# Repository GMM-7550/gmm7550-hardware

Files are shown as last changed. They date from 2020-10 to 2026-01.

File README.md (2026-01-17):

# CologneChip GateMate FPGA Module: GMM-7550

**January 2026 Update**

USB 3 adapter board is out of production, RP2040 firmware
is running, and basic functionality is tested -- no hardware
issues discovered.

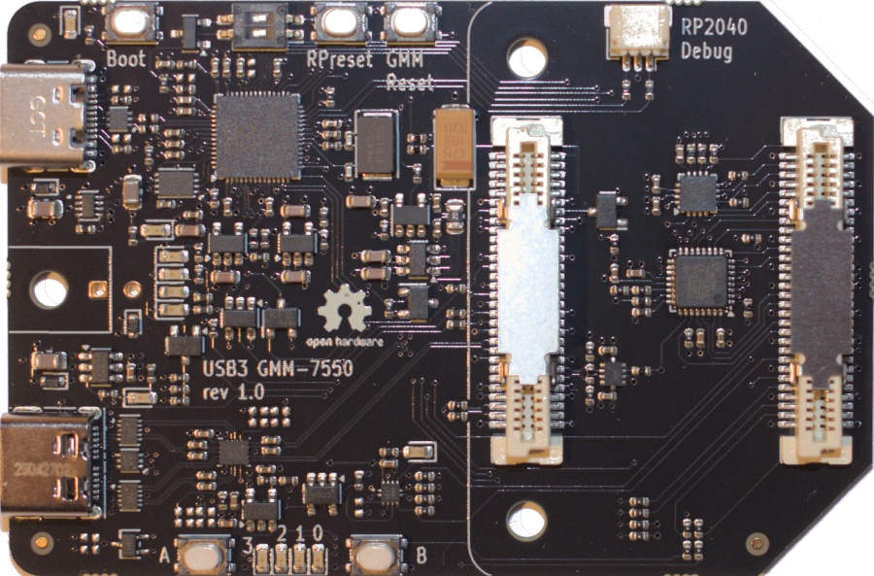
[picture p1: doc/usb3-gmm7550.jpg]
USB3 Adapter board


**October 2025 Update**

USB 3 adapter board is ready for production after the
[schematic](./doc/USB3-GMM-7550_1.0_2025-10-10.pdf)
changes and layout. KiCad 3D render of the board:

**July 2025 Update**

An experimental USB 3 Adapter board schematic is ready for
layout:

[USB 3 Adapter revision 0.9](./doc/USB3-GMM-7550_0.9_2025-07-24.pdf)

**January 2024 Update**

The project repositories are moved to a dedicated account.
Please, update your references to <https://github.com/gmm-7550/>
to follow further development.

**June 2022 Update**
After more than two years of development and delays
the module and adapter boards are out of production.

Tests are underway, no problems discovered so far, updates
are expected in a few weeks.

This project is licensed under [CERN-OHL-P v2](./cern_ohl_p_v2.txt)

Current module revision is 2.1 -- it is updated to the latest
(flip-chip) GateMate FPGA pin out. The other changes are complete
redesigns of the power and clock subsystems due to component
availability.

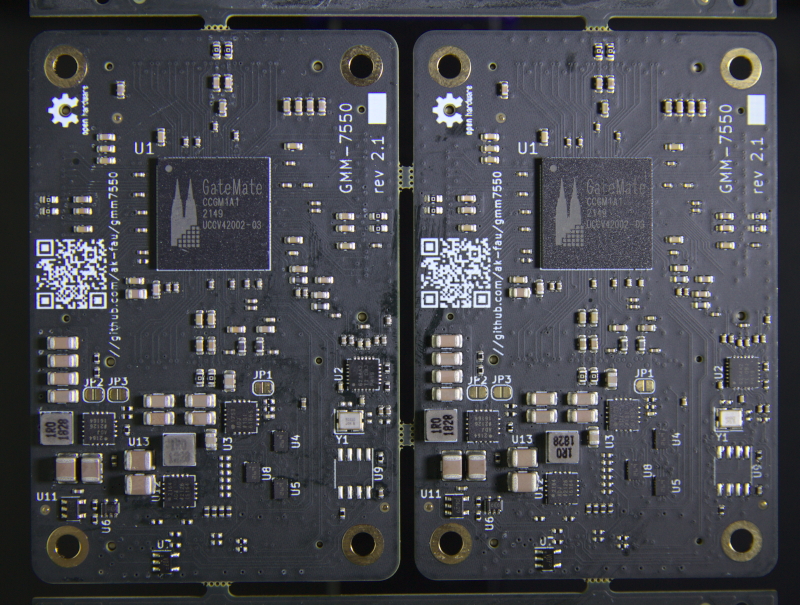
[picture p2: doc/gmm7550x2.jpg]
Assembled modules


[Schematic (pdf) version 2.1](./doc/GMM-7550_2.1_2022-04-24.pdf)

## 40-pin GPIO (R-Pi HAT) Adapter for GMM-7550 Module

The adapter board provides power to the GMM-7550 module (5V from
40-pin GPIO or from an external connector), I2C and SPI interfaces,
control over the module power enable and reset signals and module
power consumption monitoring.

Two 12-pin Pmod extension connectors are routed to the GateMate
FPGA South GPIO pins through 2.5/3.3 bi-directional level converter.

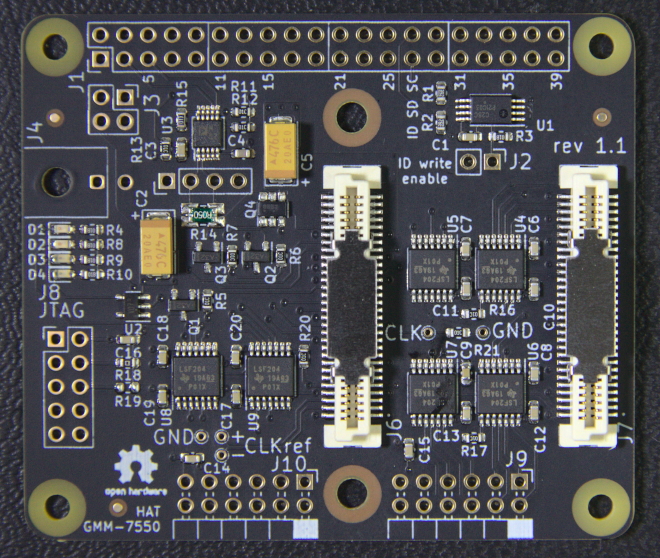
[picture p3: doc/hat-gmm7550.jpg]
Assembled 40-pin adapter board


[Schematic (pdf) version 1.1](./doc/HAT-GMM-7550_1.1_2022-04-24.pdf)

## Memory Extension Module

The module provides 512Kx8 static RAM (CY7C1049GN30-10ZSXI) with 10 ns
access time and 16 MiB QSPI NOR FLASH (S25LP128-JBLE). The module may
be connected to P1, P2 or P3 connector of the GMM-7550, up to three
modules may be connected simultaneously. An SPI Bridge example design
for FPGA routes SPI from a host (R-Pi or VisionFive board) to the
module connector and allows to access the SPI NOR chip on the module
from the host. The module control software provides commands to
automate the FPGA configuration and access to the SPI on the extension
module.

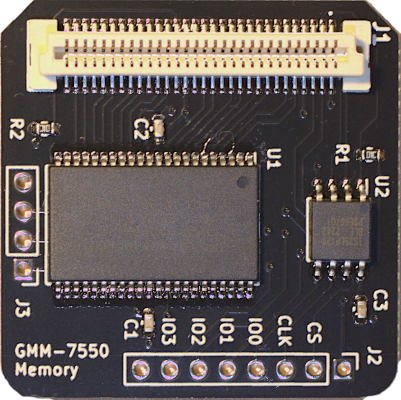
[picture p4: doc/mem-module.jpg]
Memory module


[Schematic (pdf) version 1.0](./doc/MEM-GMM-7550_1.0_2023-04-24.pdf)

## Test and Demo System based on VisionFive RISC-V SBC

The SBC runs [`buildroot`](https://buildroot.org/) embedded Linux,
experimental
[configuration for the VisionFive board](https://github.com/ak-fau/buildroot-visionfive/)
is available as a `buildroot`-external tree.

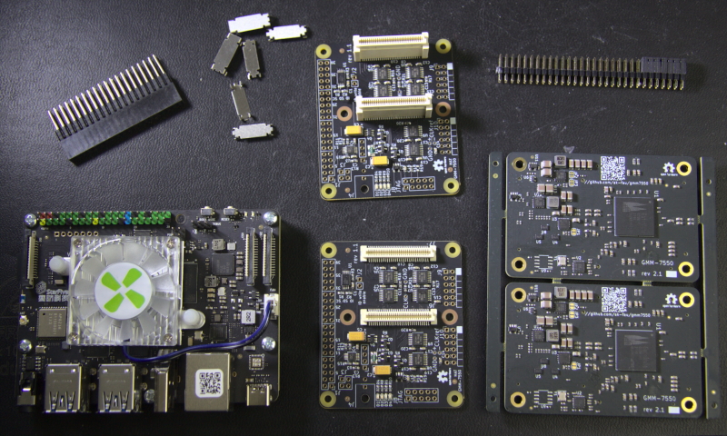
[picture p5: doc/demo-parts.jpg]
VisionFive SBC and modules for the test system


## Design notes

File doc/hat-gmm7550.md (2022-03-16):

# 40-pin GPIO (Raspberry Pi) HAT adapter for GMM-7550 module

# Connectors

## 40-pin GPIO J1

| RPi HAT | VisionFive | GMM | Pin | Pin | GMM | VisionFive | RPi HAT |
|---|---|---|:---:|:---:|---|---|---|
| +3.3V | +3.3V | +3.3V |  1  |  2  | +5V | +5V | +5V |
| | GPIO48 | SDA |  3  |  4  | +5V | +5V | +5V |
| | GPIO47 | SCL |  5  |  6  | GND | GND | GND |
| | GPIO46 | ON |  7  |  8  | Tx | GPIO14 | |
| GND | GND | GND |  9  |  10 | Rx | GPIO13 | |
| | GPIO44 | MR |  11 |  12 | | | |
| | GPIO22 | OFF |  13 |  14 | GND | GND | GND |
| | | |  15 |  16 | | | |
| +3.3V | +3.3V | +3.3V |  17 |  18 | | | |
| | GPIO18 | MOSI  |  19 |  20 | GND | GND | GND |
| | GPIO16 | MISO  |  21 |  22 | | | |
| | GPIO12 | SCK |  23 |  24 | | | |
| GND | GND | GND |  25 |  26 | | | |
| ID_SD | ID_SD | ID_SD |  27 |  28 | ID_SC | ID_SC | ID_SC |
| | | |  29 |  30 | GND | GND | GND |
| | | |  31 |  32 | | | |
| | | |  33 |  34 | GND | GND | GND |
| | | |  35 |  36 | | | |
| | | |  37 |  38 | | | |
| GND | GND | GND |  39 |  40 | GND | GND | GND |

## Pmod J9

Enable signal: `IO_SB_B3`

| Signal | Pin | Pin | Signal |
|---|:---:|:---:|---|
| `IO_SB_A6 (CLK3)` |  1  |  7  | `IO_SB_B6` |
| `IO_SB_A7 (CLK2)` |  2  |  8  | `IO_SB_B7` |
| `IO_SB_A8 (clk1)` |  3  |  9  | `IO_SB_B8` |
| `IO_SB_A5 (clk4)` |  4  |  10 | `IO_SB_B5` |
|  `GND` |  5  |  11 | `GND` |
|  `+3.3V` |  6  |  12 | `+3.3V` |

## Pmod J10

Enable signal: `IO_SA_A7`

| Signal | Pin | Pin | Signal |
|---|:---:|:---:|---|
| `IO_SA_A0` |  1  |  7  | `IO_SA_B0` |
| `IO_SA_A1` |  2  |  8  | `IO_SA_B1` |
| `IO_SA_A2` |  3  |  9  | `IO_SA_B2` |
| `IO_SA_A3` |  4  |  10 | `IO_SA_B3` |
|  `GND` |  5  |  11 | `GND` |
|  `+3.3V` |  6  |  12 | `+3.3V` |

## JTAG J8

| Signal | Pin | Pin | Signal |
|---|:---:|:---:|---|
| TCK |  1  |  2  | GND |
| TDO |  3  |  4  | Vio (opt)  |
| TMS |  5  |  6  | Vio (opt)  |
| n.c. |  7  |  8  | n.c. |
| TDI |  9  | 10  | GND |

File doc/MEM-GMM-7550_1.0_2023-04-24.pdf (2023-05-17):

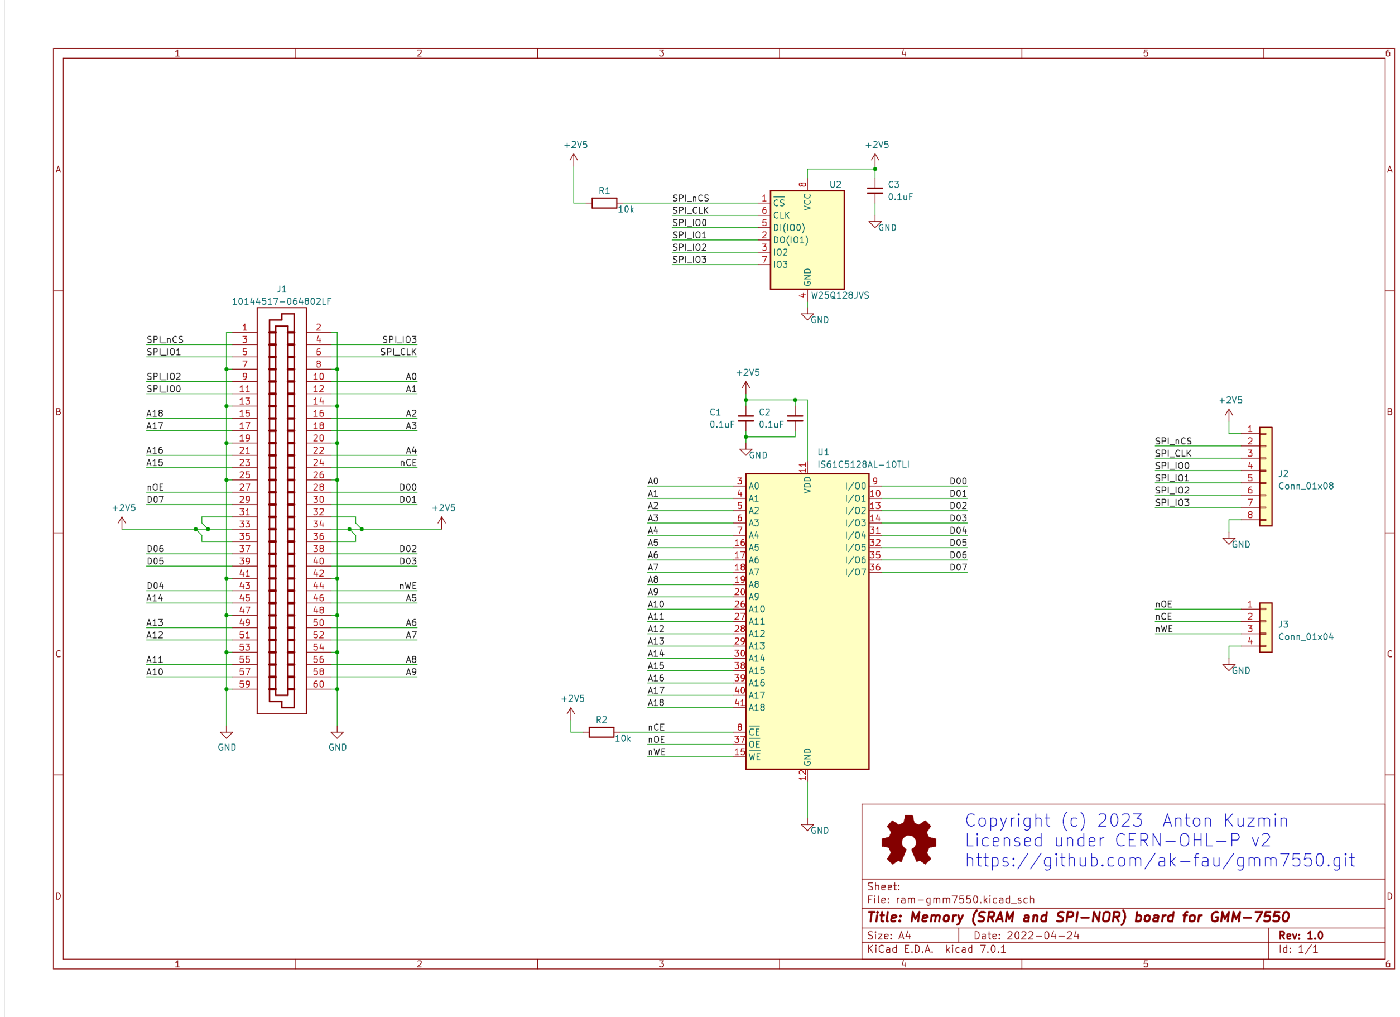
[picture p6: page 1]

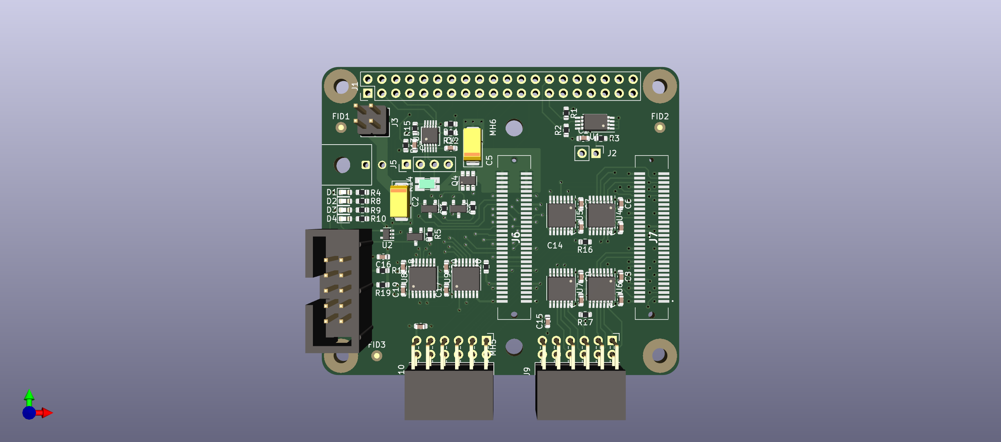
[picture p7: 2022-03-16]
doc/hat-gmm7550_preview_2022-01-22.png

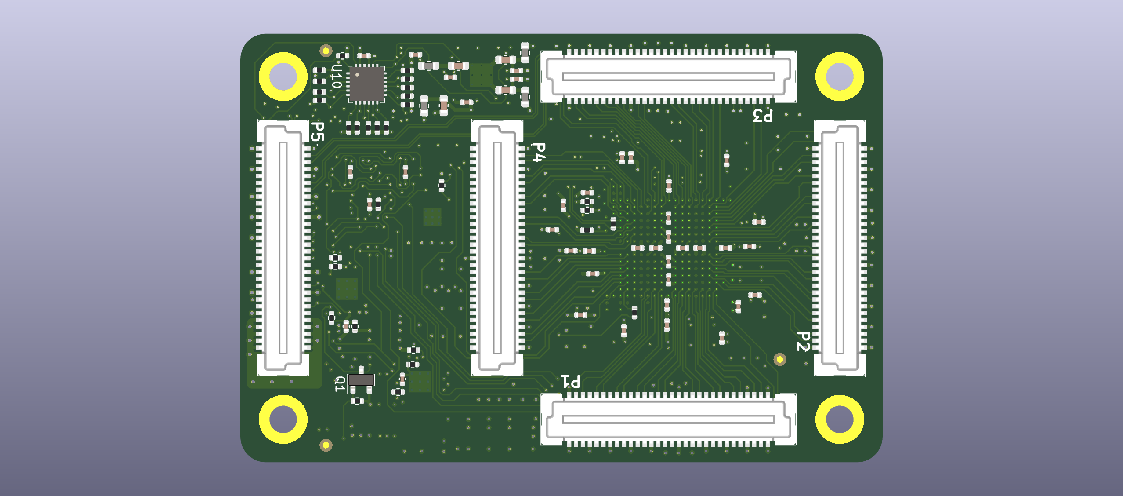
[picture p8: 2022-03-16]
doc/gmm7550_preview_bot_2022-03-09.png

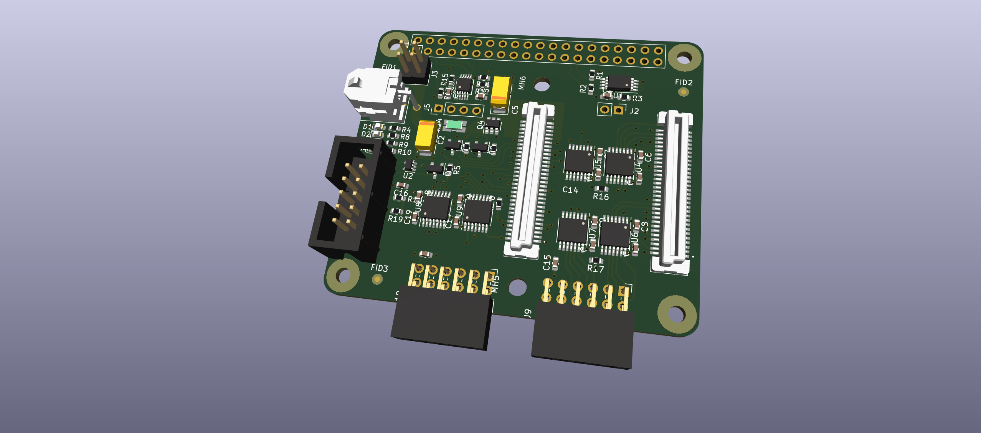
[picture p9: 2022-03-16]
doc/hat-gmm7550_preview_2022-01-27.png

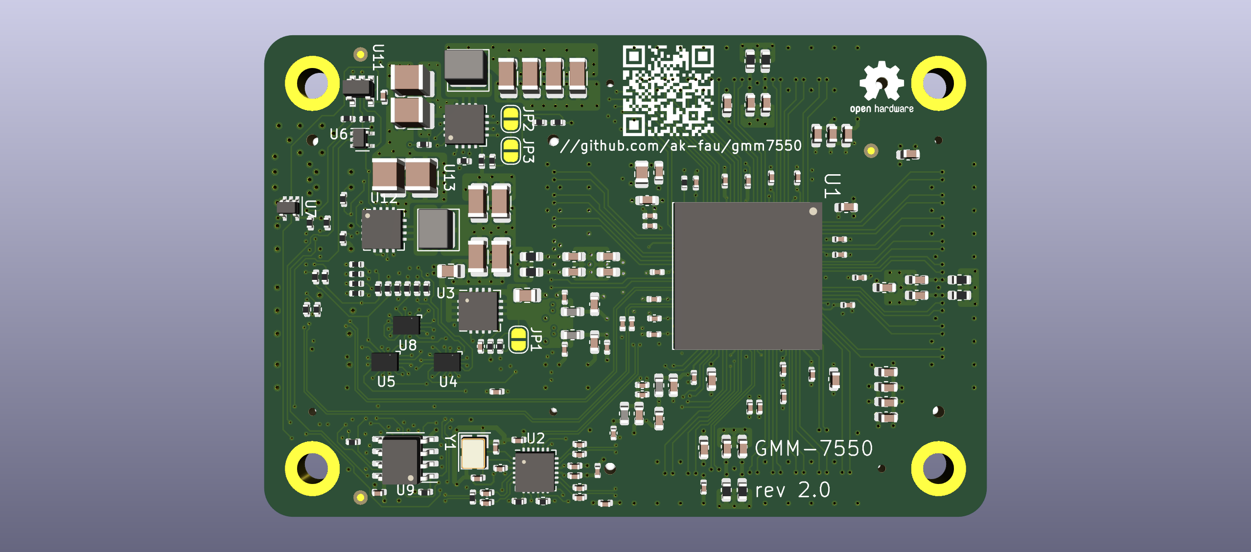
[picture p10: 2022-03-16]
doc/gmm7550_preview_top_2022-03-09.png

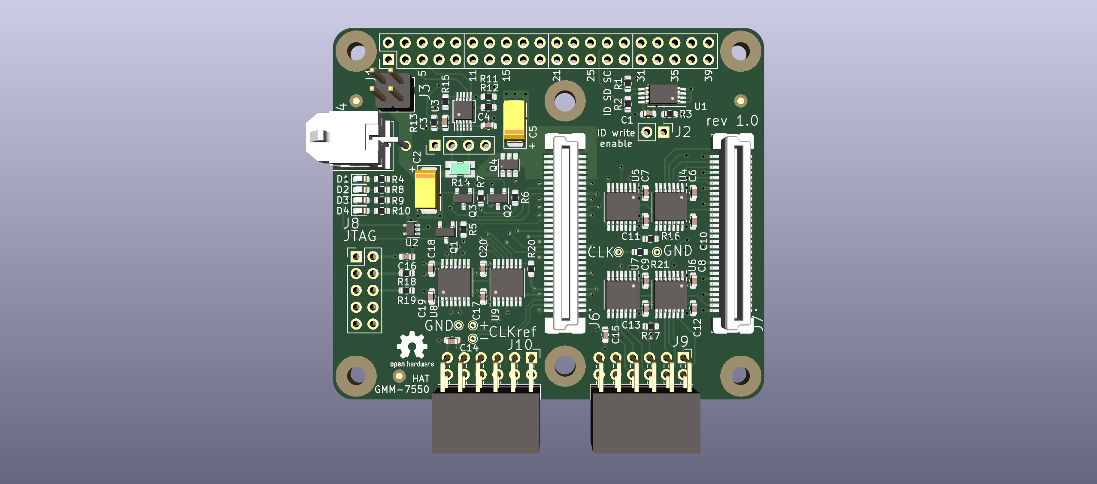
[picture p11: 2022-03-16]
doc/hat-gmm7550_preview_2022-03-09.png

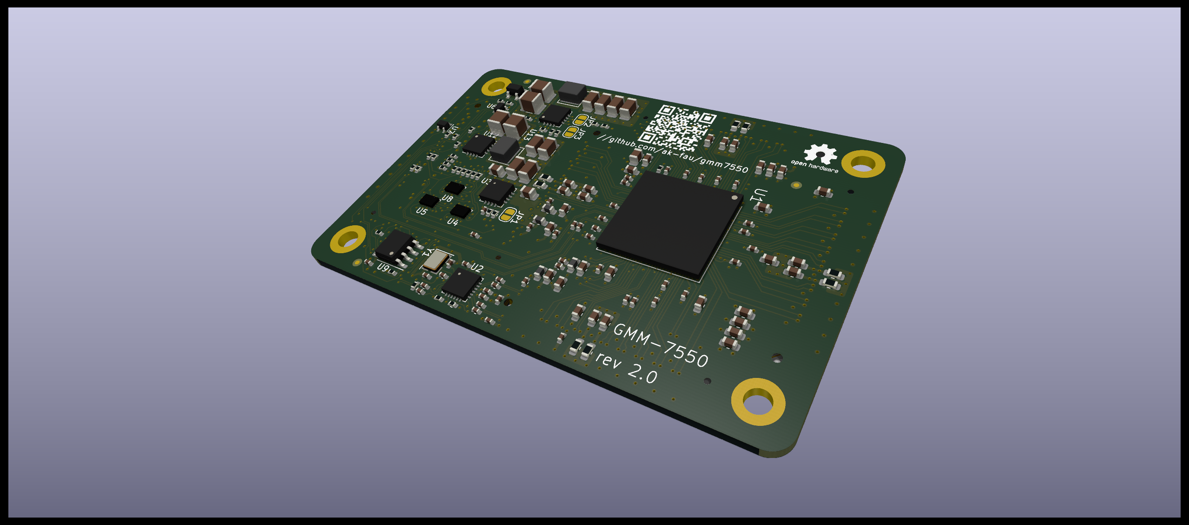
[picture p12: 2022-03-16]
doc/gmm7550_preview_3d_2022-03-09.png

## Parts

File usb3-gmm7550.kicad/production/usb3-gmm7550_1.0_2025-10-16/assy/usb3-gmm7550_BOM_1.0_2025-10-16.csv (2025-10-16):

Reference | Qty | Value | DNP | Exclude from BOM | Exclude from Board | Footprint | Datasheet
C1,C4,C5,C6,C7,C8,C9,C10,C12,C14,C15,C16,C21,C22,C26,C32,C33,C34,C35,C36,C37,C38,C39,C40,C41,C46,C47 | 27 | 0.1uF |  |  |  | Capacitor_SMD:C_0402_1005Metric | ~
C2,C3,C13,C17,C18,C44,C48,C49,C53 | 9 | 1.0uF |  |  |  | Capacitor_SMD:C_0402_1005Metric | ~
C11,C23,C45,C56 | 4 | 0.01uF |  |  |  | Capacitor_SMD:C_0402_1005Metric | ~
C19,C20,C27,C28,C29,C30,C31 | 7 | 2.2uF |  |  |  | Capacitor_SMD:C_0603_1608Metric | ~
C24 | 1 | DNI |  |  |  | Capacitor_SMD:C_0402_1005Metric | ~
C25 | 1 | 47uF, 16V |  |  |  | Capacitor_Tantalum_SMD:CP_EIA-6032-28_Kemet-C | ~
C42,C43 | 2 | 27pF |  |  |  | Capacitor_SMD:C_0402_1005Metric | ~
C50,C51,C52 | 3 | 10uF |  |  |  | Capacitor_SMD:C_0805_2012Metric | ~
D1,D11,D14 | 3 | CEZ6V2 |  |  |  | Diode_SMD:D_SOD-523 | ~
D2 | 1 | ESD752DCKR |  |  |  | usb3-gmm7550:SOT-SC70_DCK_TEX | https://www.ti.com/lit/gpn/esd752
D3,D4,D7,D8,D9,D10,D12,D13,D16 | 9 | 150060VS55040 |  |  |  | LED_SMD:LED_0603_1608Metric | ~
D5,D15 | 2 | HSMA-C197 |  |  |  | LED_SMD:LED_0603_1608Metric | ~
D6 | 1 | HSMC-C197 |  |  |  | LED_SMD:LED_0603_1608Metric | ~
J1 | 1 | USB_C_Receptacle |  |  |  | Connector_USB:USB_C_Receptacle_Molex_105450-0101 | https://www.usb.org/sites/default/files/documents/usb_type-c.zip
J2 | 1 | USB_C_Receptacle_USB2.0 |  |  |  | Connector_USB:USB_C_Receptacle_GCT_USB4105-xx-A_16P_TopMnt_Horizontal | https://www.usb.org/sites/default/files/documents/usb_type-c.zip
J3 | 1 | SWD |  |  |  | Connector_JST:JST_SH_SM03B-SRSS-TB_1x03-1MP_P1.00mm_Horizontal | ~
J4,J5 | 2 | 10144517-061802LF |  |  |  | Amphenol:10144517-061802LF
J6 | 1 | DNI |  |  |  | Connector_Molex:Molex_Micro-Fit_3.0_43045-0200_2x01_P3.00mm_Horizontal | ~
Q1,Q2,Q3,Q4 | 4 | NX6008NBK |  |  |  | Package_TO_SOT_SMD:SOT-23 | ~
R1,R2,R5,R6,R7,R8,R9,R10,R11,R12,R54,R55,R67,R79 | 14 | DNI |  |  |  | Resistor_SMD:R_0402_1005Metric | ~
R3,R13,R20,R21,R23,R26,R29,R31,R32,R34,R35,R42,R43,R50,R51,R56,R65,R70,R71,R72,R76,R77,R78 | 23 | 10k |  |  |  | Resistor_SMD:R_0402_1005Metric | ~
R4,R24 | 2 | 8.06k |  |  |  | Resistor_SMD:R_0402_1005Metric | ~
R14,R16,R57,R58 | 4 | 5.1k |  |  |  | Resistor_SMD:R_0402_1005Metric | ~
R15,R36,R40,R62,R63,R83 | 6 | 100 |  |  |  | Resistor_SMD:R_0402_1005Metric | ~
R17,R28,R60,R61 | 4 | 27.4 |  |  |  | Resistor_SMD:R_0402_1005Metric | ~
R18,R19,R89,R90 | 4 | 15 |  |  |  | Resistor_SMD:R_0402_1005Metric | ~
R22,R66,R80 | 3 | 0 |  |  |  | Resistor_SMD:R_0402_1005Metric | ~
R25,R27,R44,R45,R52,R53,R59,R64,R69,R73,R74,R75 | 12 | 1k |  |  |  | Resistor_SMD:R_0402_1005Metric | ~
R30,R33,R41,R46,R47,R48,R49,R68 | 8 | 75 |  |  |  | Resistor_SMD:R_0402_1005Metric | ~
R37 | 1 | 0.02 |  |  |  | Resistor_SMD:R_0805_2012Metric | ~
R38 | 1 | 120k |  |  |  | Resistor_SMD:R_0402_1005Metric | ~
R39 | 1 | 100k |  |  |  | Resistor_SMD:R_0402_1005Metric | ~
R81 | 1 | 900k |  |  |  | Resistor_SMD:R_0402_1005Metric | ~
R82,R84 | 2 | 301 |  |  |  | Resistor_SMD:R_0402_1005Metric | ~
R85 | 1 | 6.19k |  |  |  | Resistor_SMD:R_0402_1005Metric | ~
R86 | 1 | 2k |  |  |  | Resistor_SMD:R_0402_1005Metric | ~
R87 | 1 | 3.57k |  |  |  | Resistor_SMD:R_0402_1005Metric | ~
R88 | 1 | 1.69k |  |  |  | Resistor_SMD:R_0402_1005Metric | ~
SW1,SW2,SW3,SW4,SW5 | 5 | SW_Push |  |  |  | Button_Switch_SMD:SW_SPST_PTS810 | ~
SW6 | 1 | SW_DIP_x02 |  |  |  | Button_Switch_SMD:SW_DIP_SPSTx02_Slide_Omron_A6H-2101_W6.15mm_P1.27mm | ~
U1,U2 | 2 | ECMF4-40A100N10 |  |  |  | usb3-gmm7550:UQFN10L_1P4X2P25X0P4_STM | https://www.st.com/resource/en/datasheet/ecmf4-40a100n10.pdf
U3,U15 | 2 | ECMF02-2AMX6 |  |  |  | Package_DFN_QFN:ST_UQFN-6L_1.5x1.7mm_P0.5mm | https://www.st.com/resource/en/datasheet/ecmf02-2amx6.pdf
U4,U12,U13 | 3 | AP7330D |  |  |  | Package_TO_SOT_SMD:SOT-23-5
U5 | 1 | TUSB542 |  |  |  | usb3-gmm7550:Texas_X2QFN-18-1EP_2x2.4mm_P0.4mm_EP1x1.4mm_ThermalVias
U6 | 1 | SN65LVDS4RSER |  |  |  | usb3-gmm7550:RSE10 | https://www.ti.com/lit/gpn/sn65lvds4
U7 | 1 | USB3340 |  |  |  | Package_DFN_QFN:QFN-32-1EP_5x5mm_P0.5mm_EP3.3x3.3mm_ThermalVias | https://ww1.microchip.com/downloads/aemDocuments/documents/UNG/ProductDocuments/DataSheets/USB3340-Data-Sheet-DS00001678E.pdf
U8 | 1 | STUSB03E |  |  |  | Package_DFN_QFN:QFN-16-1EP_3x3mm_P0.5mm_EP1.7x1.7mm | https://www.st.com/resource/en/datasheet/stusb03e.pdf
U9 | 1 | SiP32510 |  |  |  | Package_TO_SOT_SMD:SOT-23-6 | https://www.vishay.com/docs/63577/sip32510.pdf
U10 | 1 | SN74LVC1G07DBV |  |  |  | Package_TO_SOT_SMD:SOT-23-5
U11 | 1 | INA180A2 |  |  |  | Package_TO_SOT_SMD:SOT-23-5 | http://www.ti.com/lit/ds/symlink/ina180.pdf
U14 | 1 | MX25R1635FZUIH0 |  |  |  | Package_SON:Winbond_USON-8-1EP_3x2mm_P0.5mm_EP0.2x1.6mm | https://www.mouser.com/datasheet/2/1127/APM_PSRAM_QSPI_APS1604M_SQR_v2_5_PKG-1954861.pdf
U16 | 1 | LM4040A30IDBZ |  |  |  | Package_TO_SOT_SMD:SOT-23 | http://www.ti.com/lit/ds/symlink/lm4040-n.pdf
U17 | 1 | RP2040 |  |  |  | Package_DFN_QFN:QFN-56-1EP_7x7mm_P0.4mm_EP3.2x3.2mm | https://datasheets.raspberrypi.com/rp2040/rp2040-datasheet.pdf
U18 | 1 | FUSB303BTMX |  |  |  | usb3-gmm7550:OnSemi_X2QFN-12_1.6x1.6mm | https://www.onsemi.com/pub/Collateral/FUSB303B-D.PDF
U19 | 1 | SiP32508DT |  |  |  | Package_TO_SOT_SMD:TSOT-23-6 | https://www.vishay.com/docs/62754/sip32508.pdf
U20 | 1 | LM66200DRLR |  |  |  | usb3-gmm7550:SOT-5X3_DRL_TEX | https://www.ti.com/lit/gpn/lm66200
U21 | 1 | SN74LVC1G06DBV |  |  |  | Package_TO_SOT_SMD:SOT-23-5 | http://www.ti.com/lit/sg/scyt129e/scyt129e.pdf
Y1 | 1 | 445I23D12M00000 |  |  |  | Crystal:Crystal_SMD_5032-2Pin_5.0x3.2mm | ~

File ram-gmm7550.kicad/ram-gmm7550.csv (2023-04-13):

Source: | /home/ak/Work/ccgm/gmm/ram-gmm7550.kicad/ram-gmm7550.kicad_sch
Date: | Tue Apr 11 13:08:18 2023
Tool: | Eeschema 7.0.1
Generator: | /usr/share/kicad/plugins/bom_csv_grouped_by_value_with_fp.py
Component Count: | 10
Ref | Qnty | Value | Cmp name | Footprint | Description | Vendor | DNP
C1, C2, C3 | 3 | 0.1uF | C_Small | Capacitor_SMD:C_0603_1608Metric | Unpolarized capacitor, small symbol
J1 | 1 | 10144517-064802LF | 10144517-061802LF | Amphenol:10144517-061802LF | Board to Board & Mezzanine Connectors Rec, R1, 60Pos
J2 | 1 | Conn_01x08 | Conn_01x08 | Connector_PinHeader_2.54mm:PinHeader_1x08_P2.54mm_Vertical | Generic connector, single row, 01x08, script generated (kicad-library-utils/schlib/autogen/connector/)
J3 | 1 | Conn_01x04 | Conn_01x04 | Connector_PinHeader_2.54mm:PinHeader_1x04_P2.54mm_Vertical | Generic connector, single row, 01x04, script generated (kicad-library-utils/schlib/autogen/connector/)
R1, R2 | 2 | 10k | R | Resistor_SMD:R_0603_1608Metric | Resistor
U1 | 1 | IS61C5128AL-10TLI | IS61C5128AL-10TLI | Package_SO:TSOP-II-44_10.16x18.41mm_P0.8mm | 512K x 8 HIGH-SPEED CMOS STATIC RAM, 10ns, TSOP II-44
U2 | 1 | W25Q128JVS | W25Q128JVS | Package_SO:SOIC-8_5.23x5.23mm_P1.27mm | 128Mb Serial Flash Memory, Standard/Dual/Quad SPI, SOIC-8

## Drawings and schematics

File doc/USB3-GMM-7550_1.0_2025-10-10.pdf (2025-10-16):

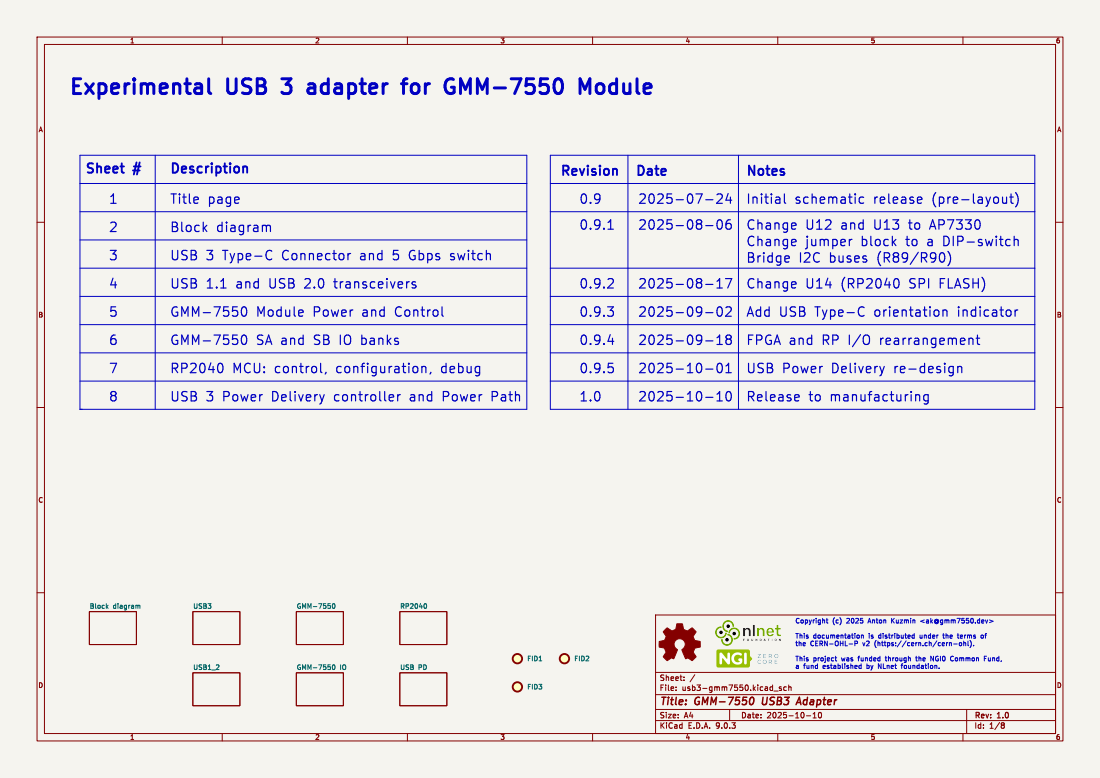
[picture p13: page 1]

Title page
Block diagram
USB 1.1 and USB 2.0 transceivers

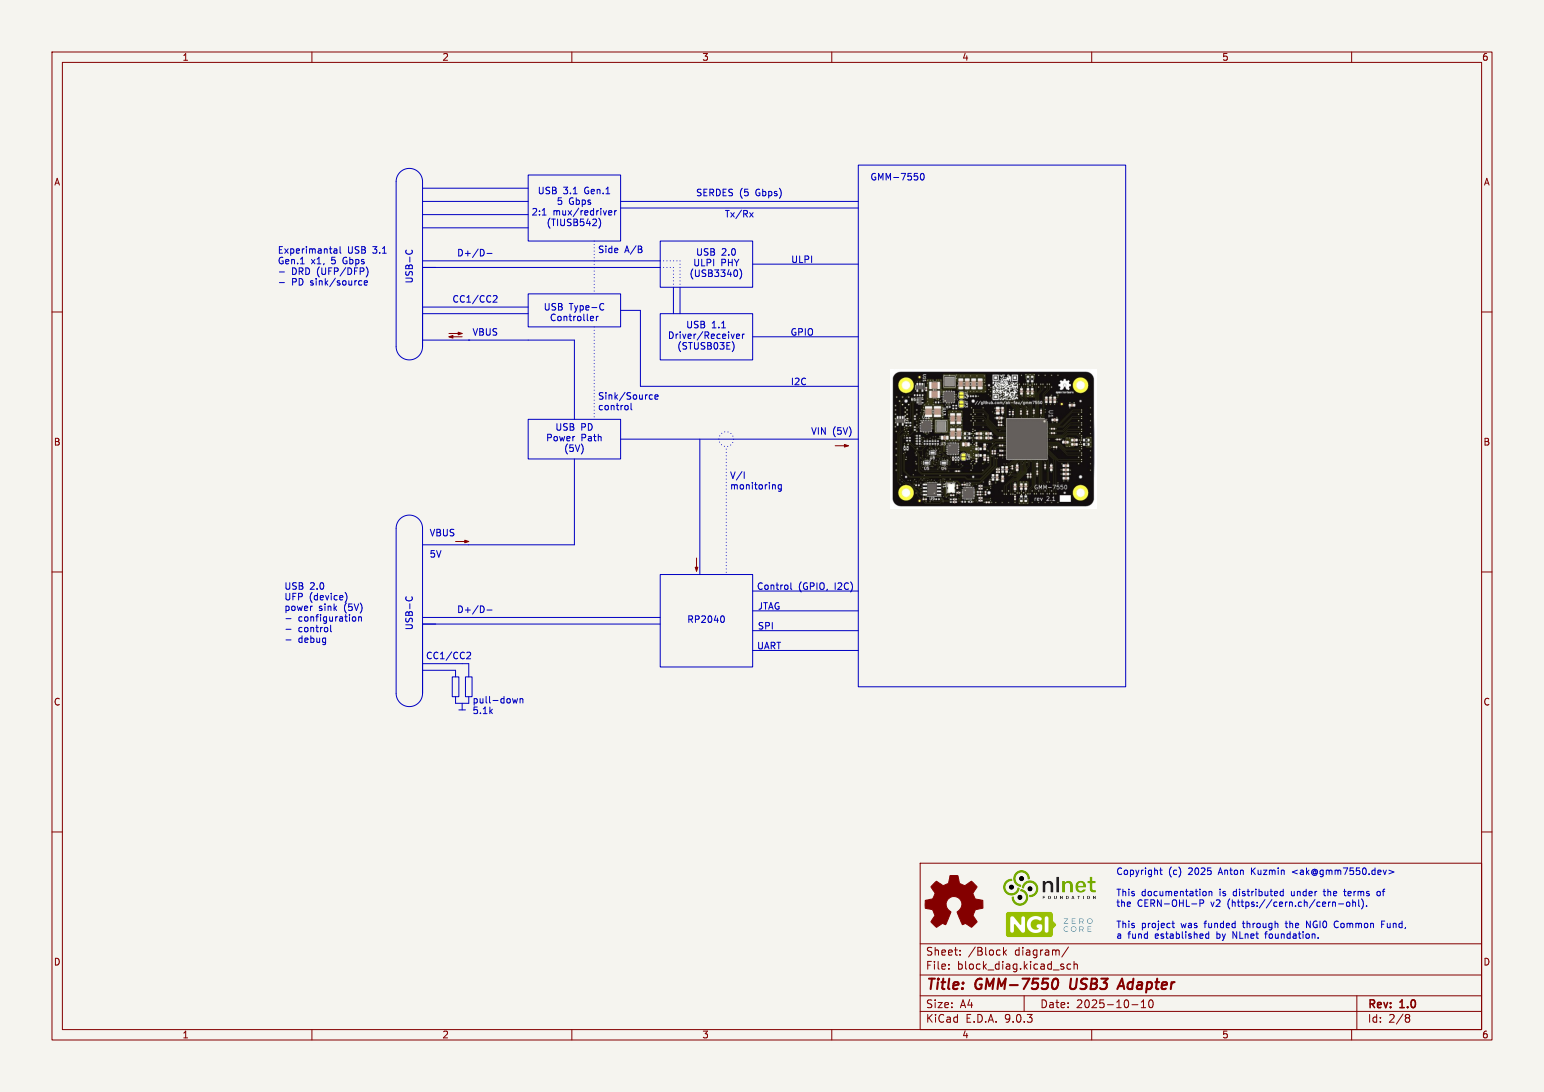
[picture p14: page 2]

- PD sink/source USB 2.0 UFP (device) power sink (5V)

(USB3340) SERDES (5 Gbps) Tx/Rx

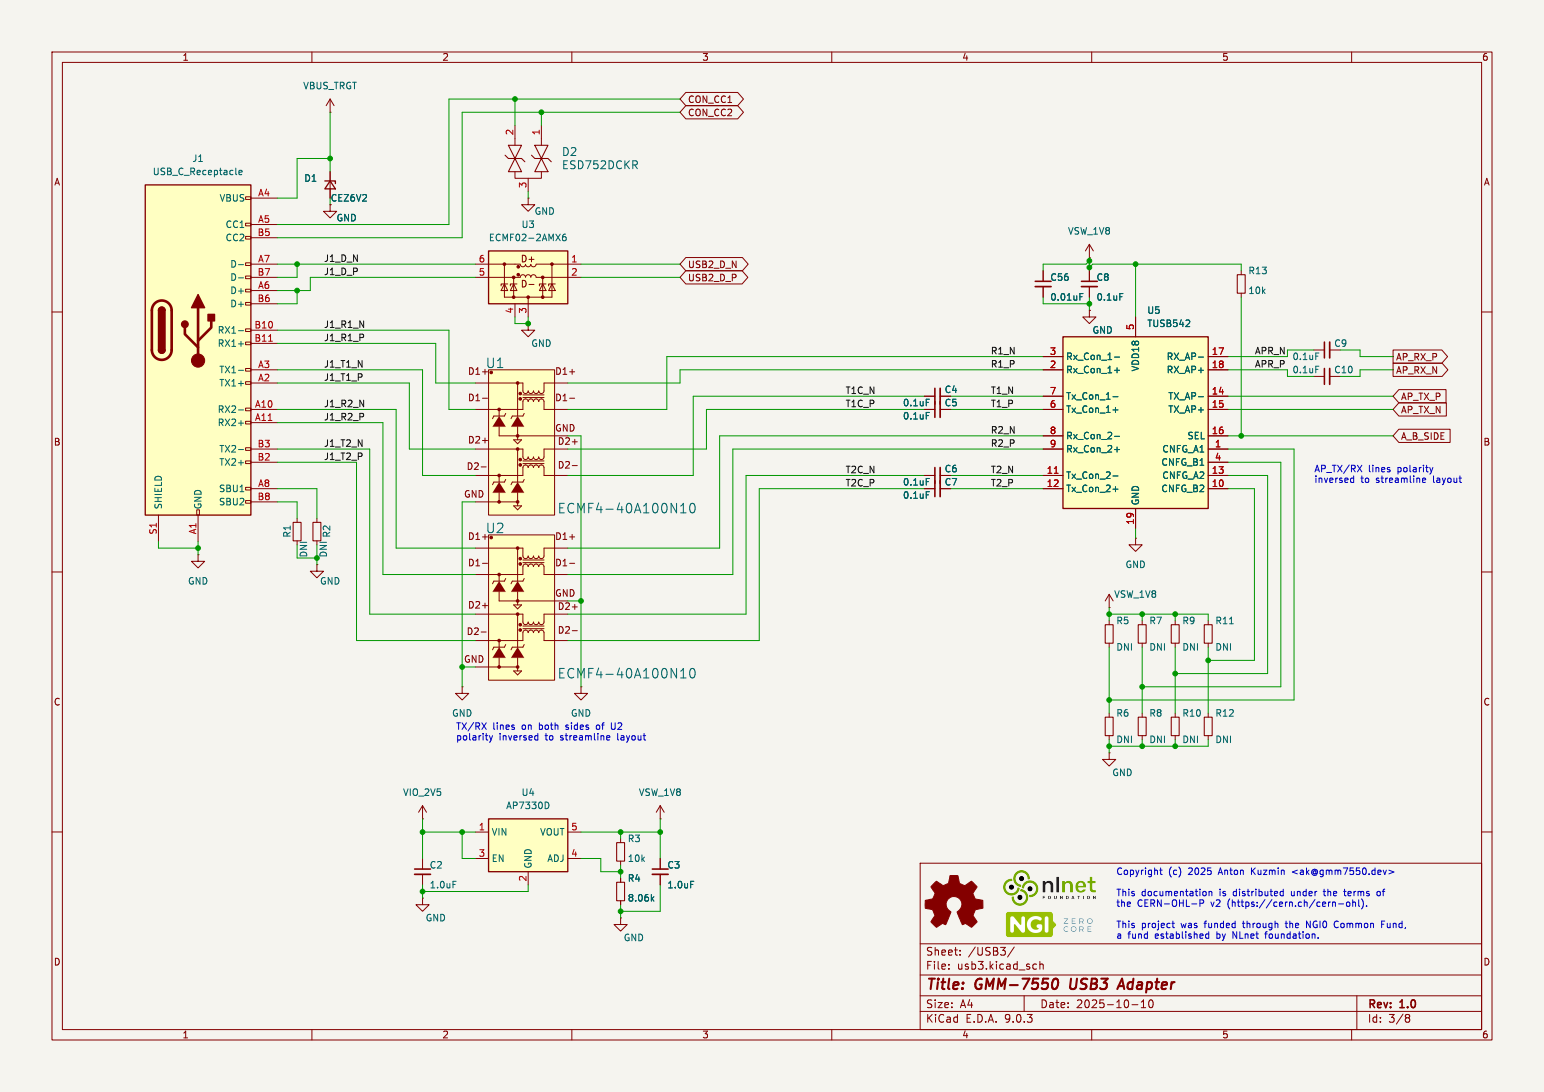
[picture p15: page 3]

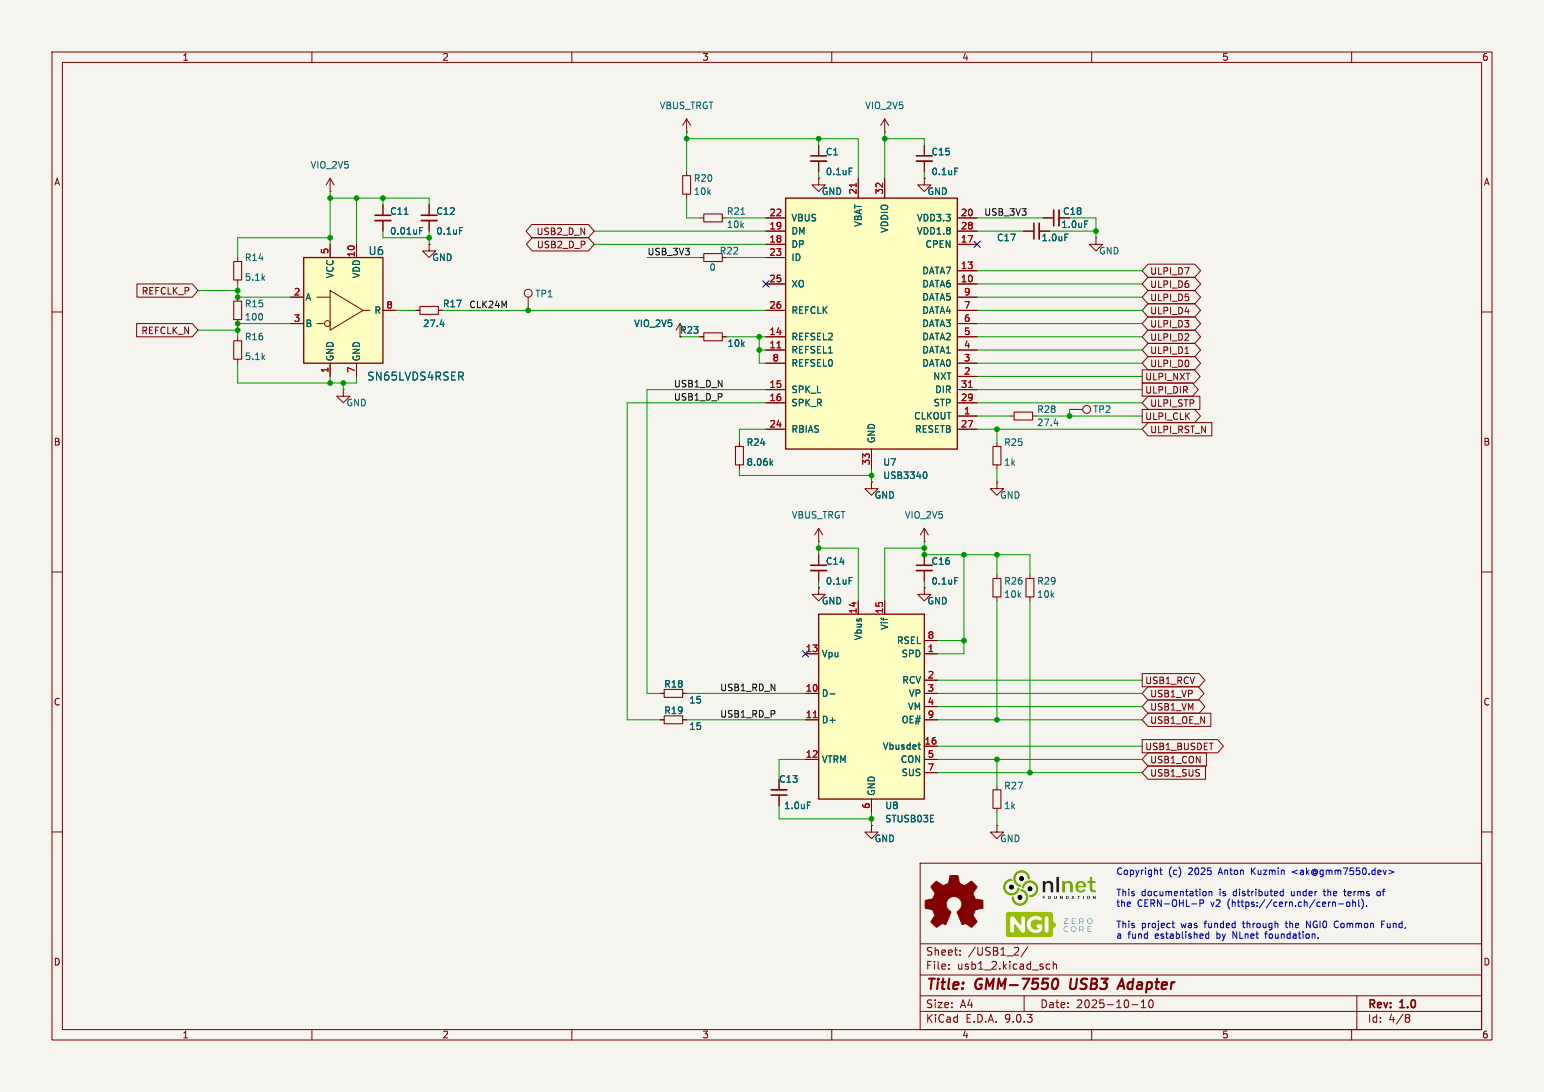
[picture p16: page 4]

6 Vif 15 RSEL 8 SPD 1 RCV 2 VP 3 VM 4 OE# 9 Vbusdet 16 CON 5 SUS 7 U7 USB3340 VBUS 22 DM 19 DP 18

6 Vif 15 RSEL 8 SPD 1 RCV 2 VP 3 VM 4 OE# 9 Vbusdet 16 CON 5 SUS 7 U8STUSB03E R29

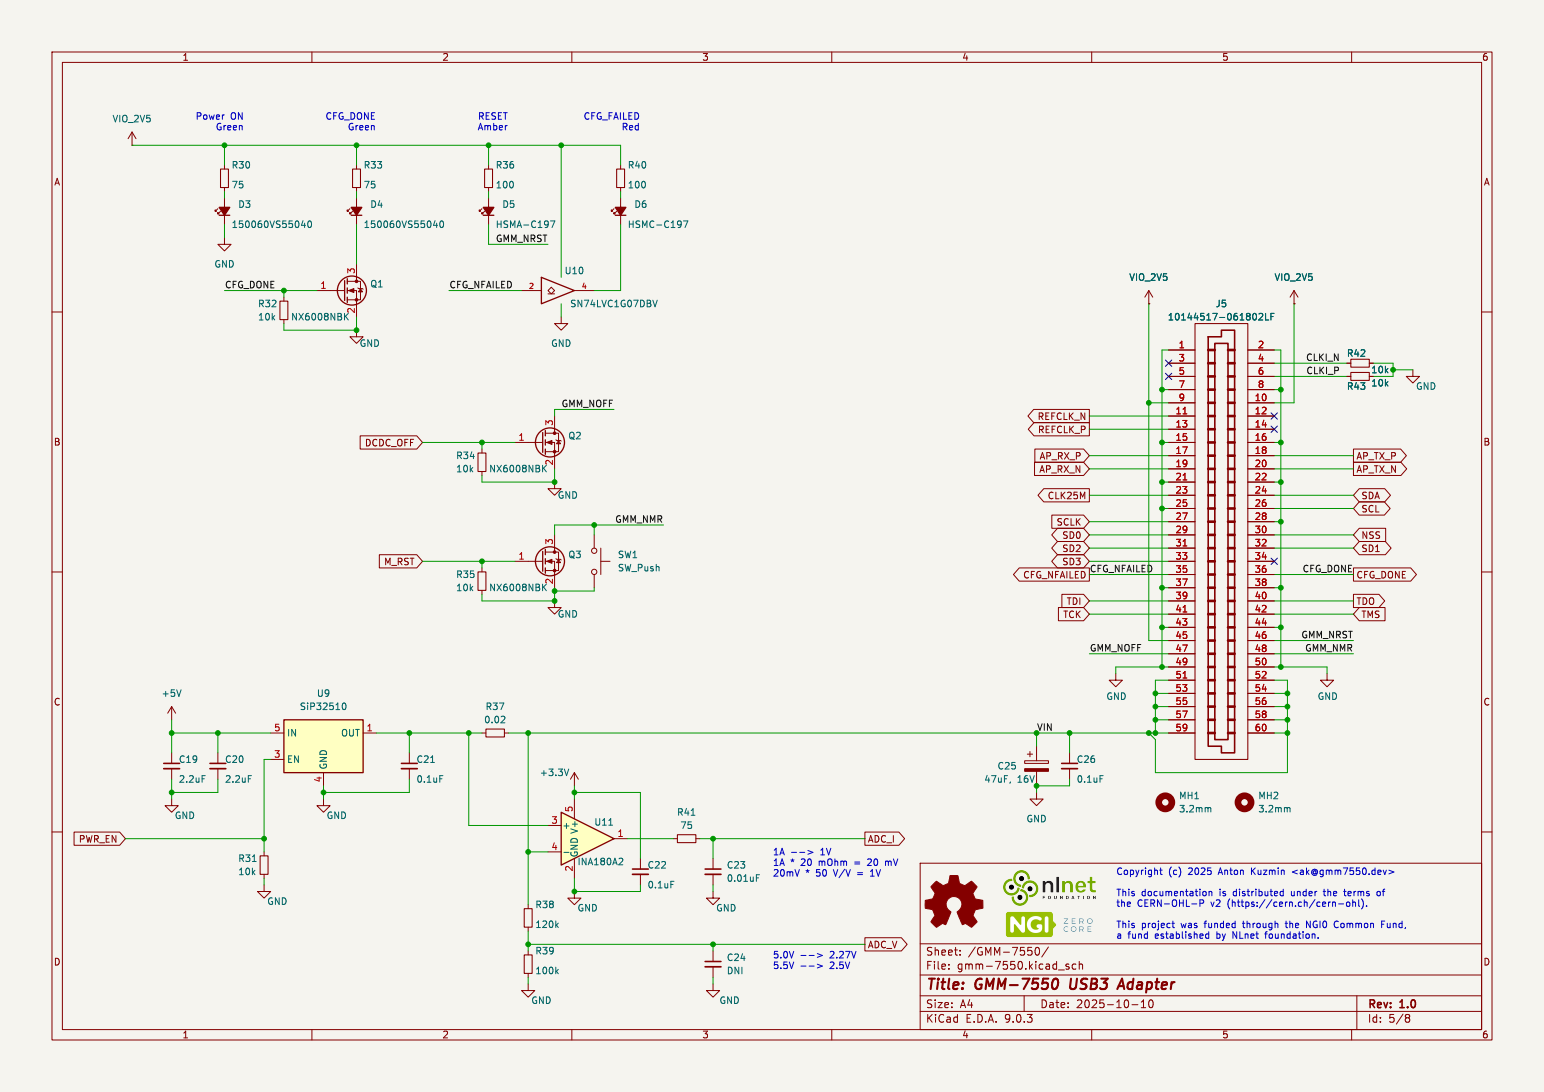
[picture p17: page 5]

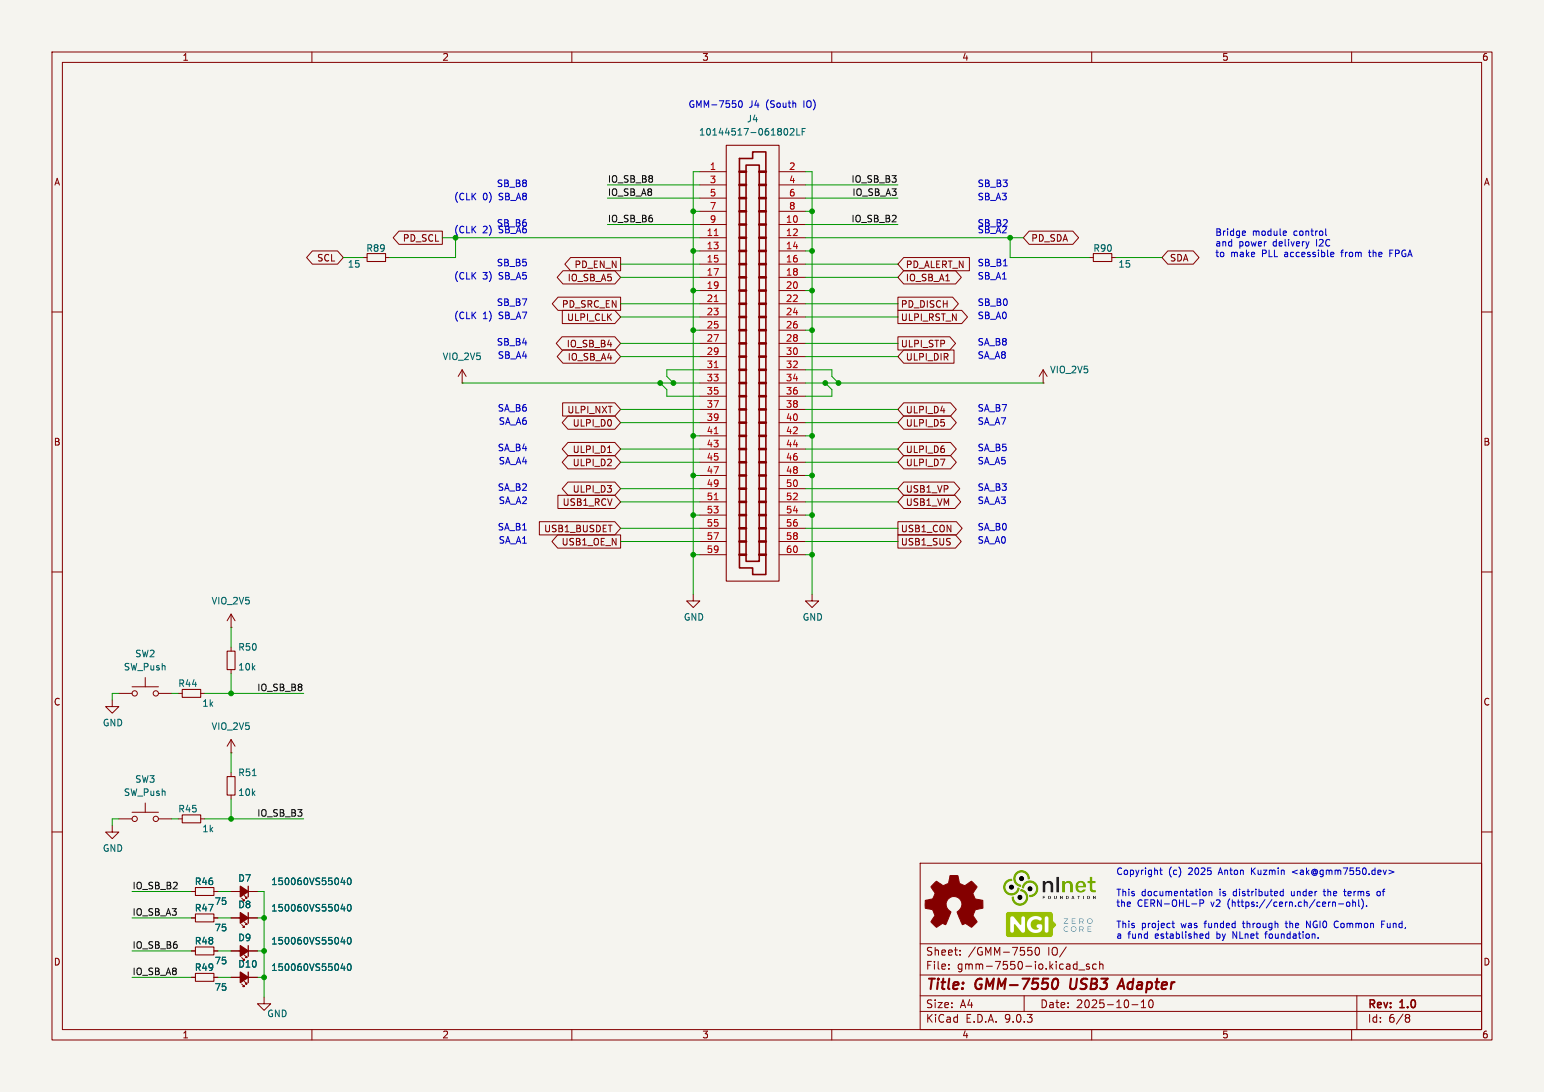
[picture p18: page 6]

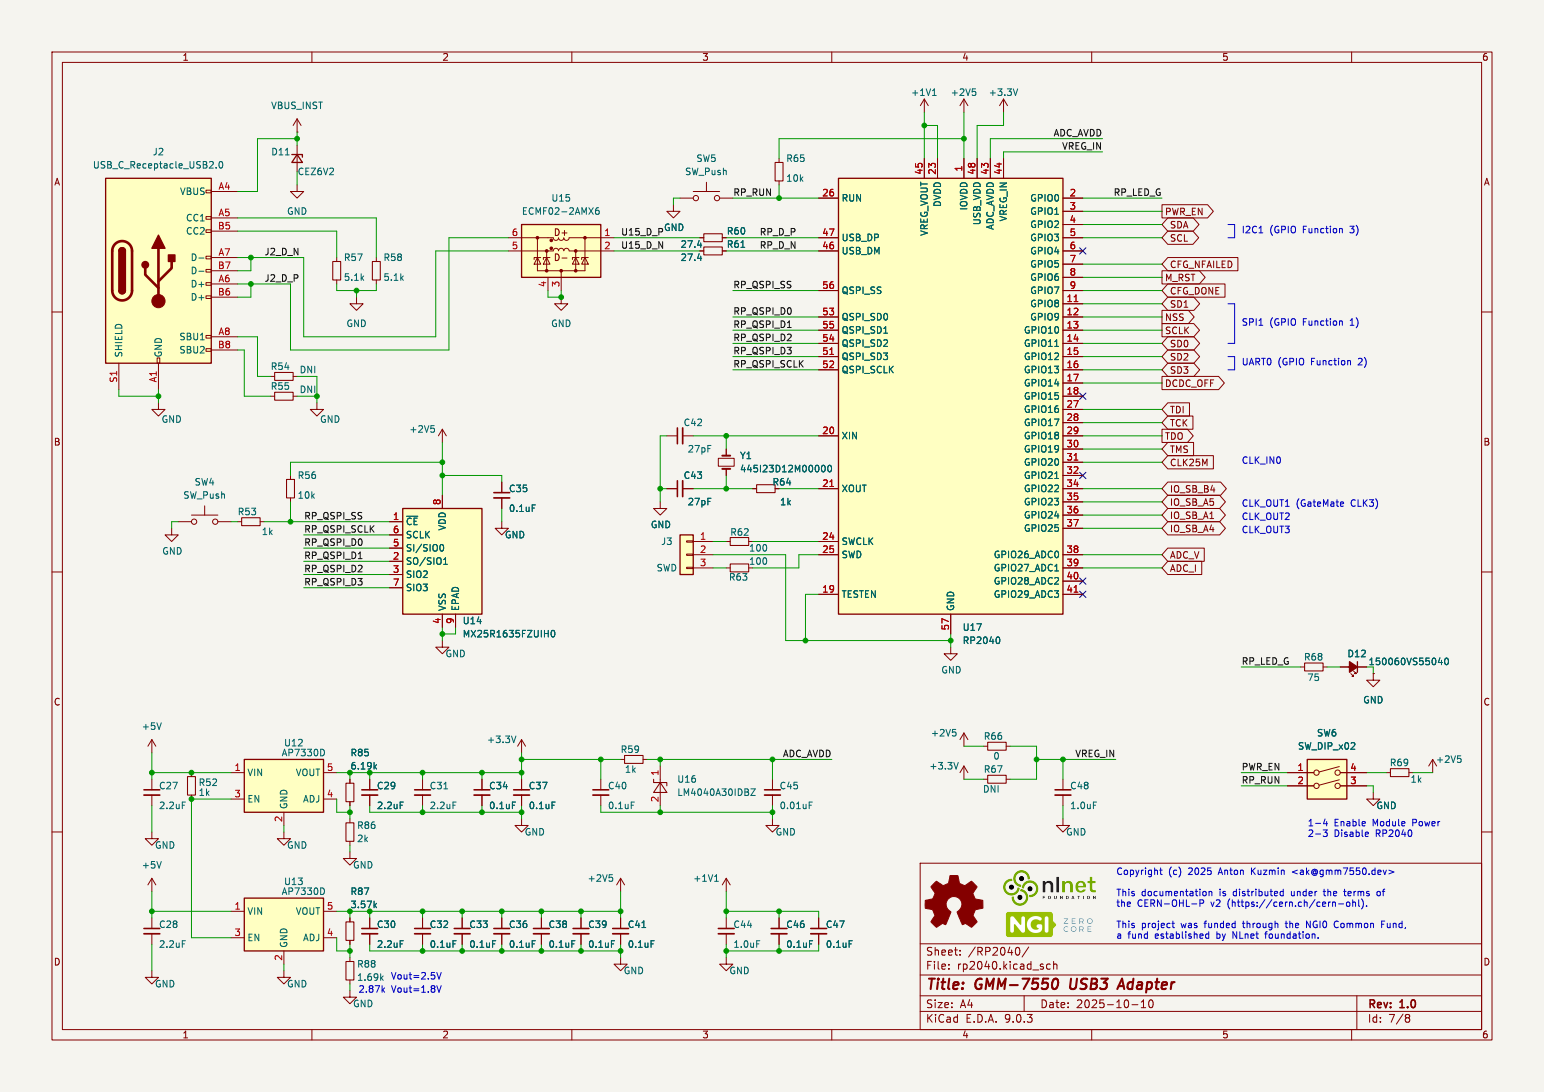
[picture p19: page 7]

2 VOUT 5 ADJ 4 U13 AP7330D GND GND

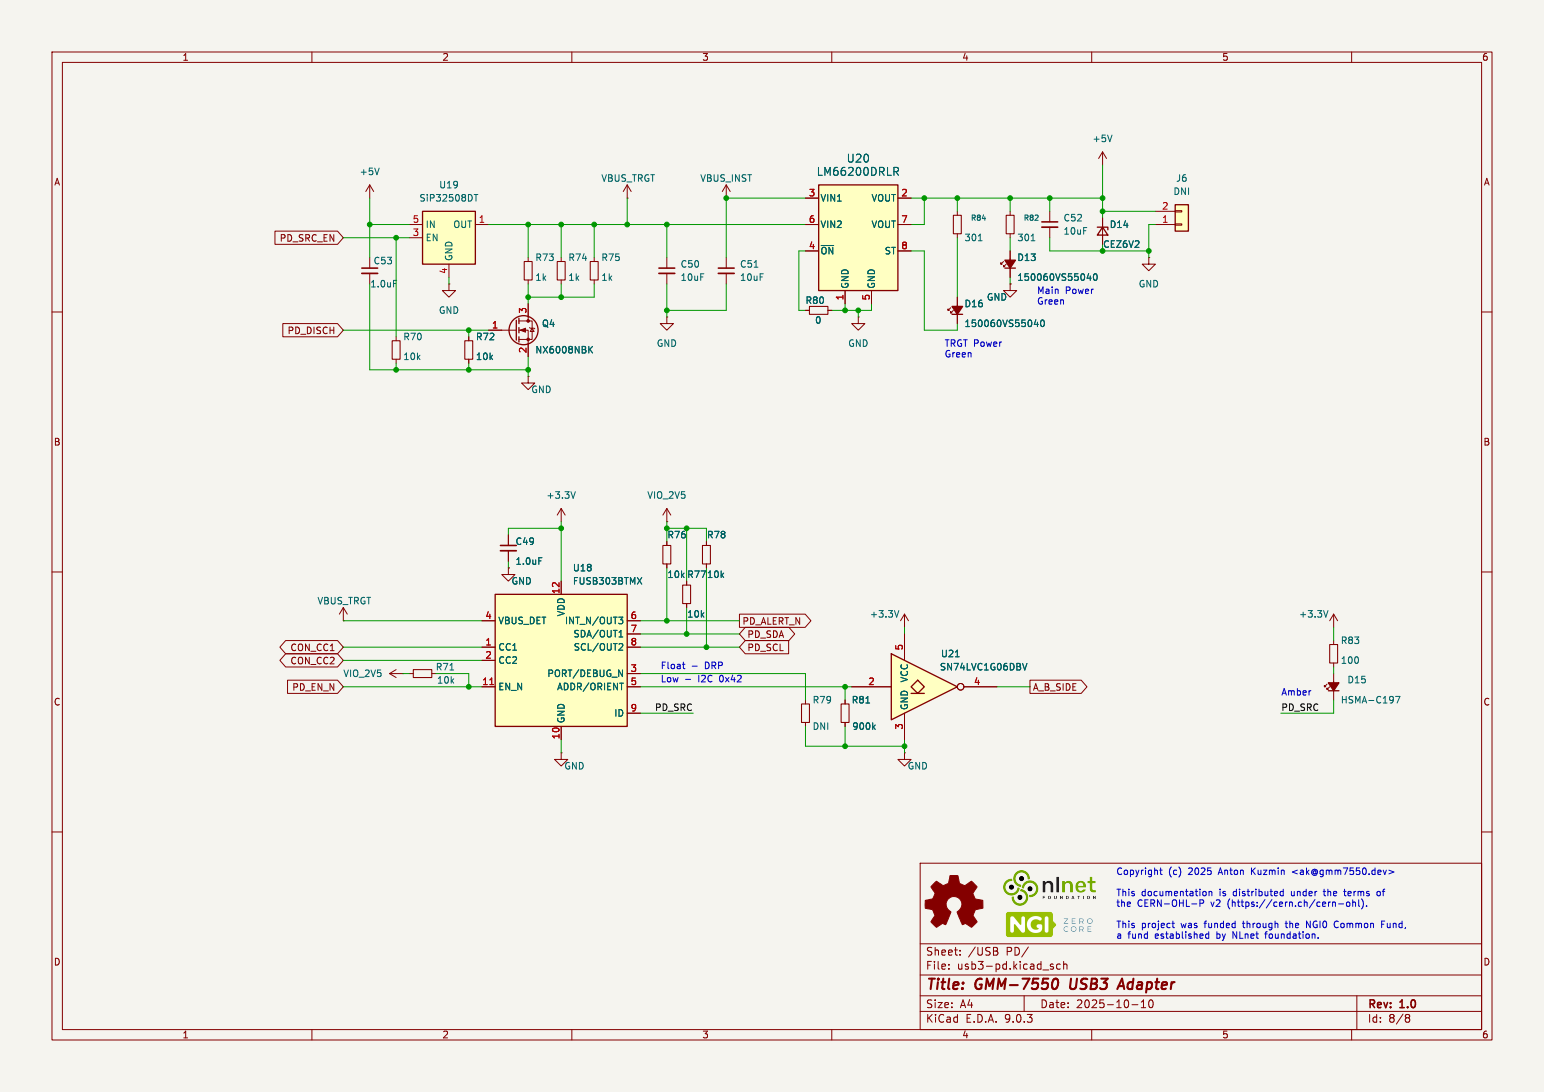
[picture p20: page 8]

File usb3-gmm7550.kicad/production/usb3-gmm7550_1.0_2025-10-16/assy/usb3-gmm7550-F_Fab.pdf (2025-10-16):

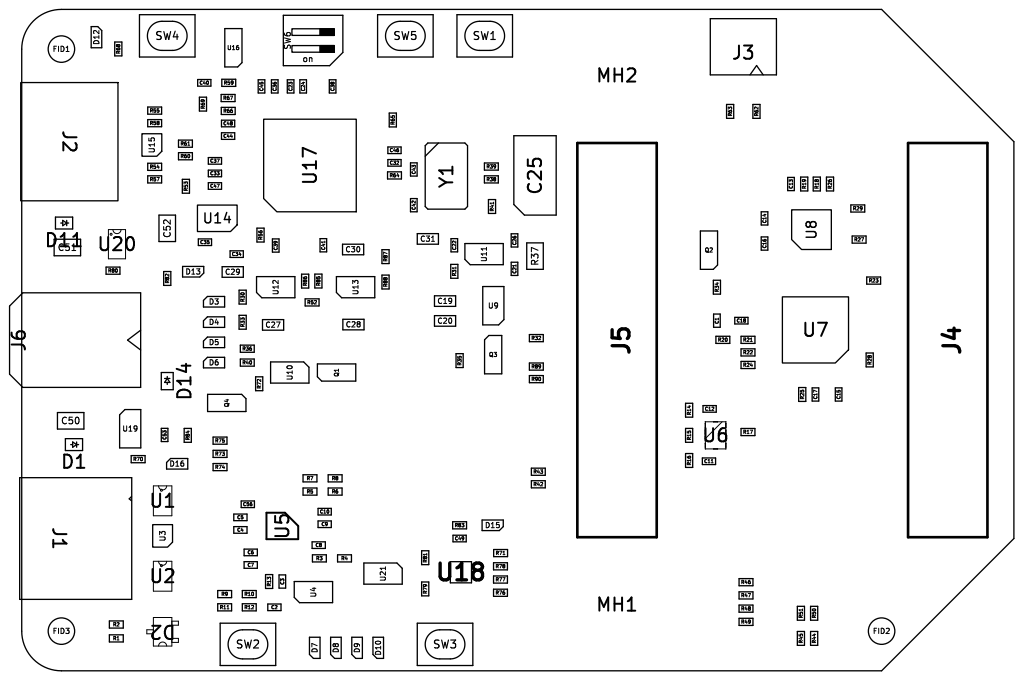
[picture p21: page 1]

a fund | established by | NLnet foundation. This project was funded | through | the | NGI0 Common | Fund,

USB3 Adapter File: usb3-gmm7550.kicad_pcb Sheet: Copyright (c) 2025 Anton | Kuzmin <ak@gmm7550.dev> Id: 11/11 Title: GMM-7550

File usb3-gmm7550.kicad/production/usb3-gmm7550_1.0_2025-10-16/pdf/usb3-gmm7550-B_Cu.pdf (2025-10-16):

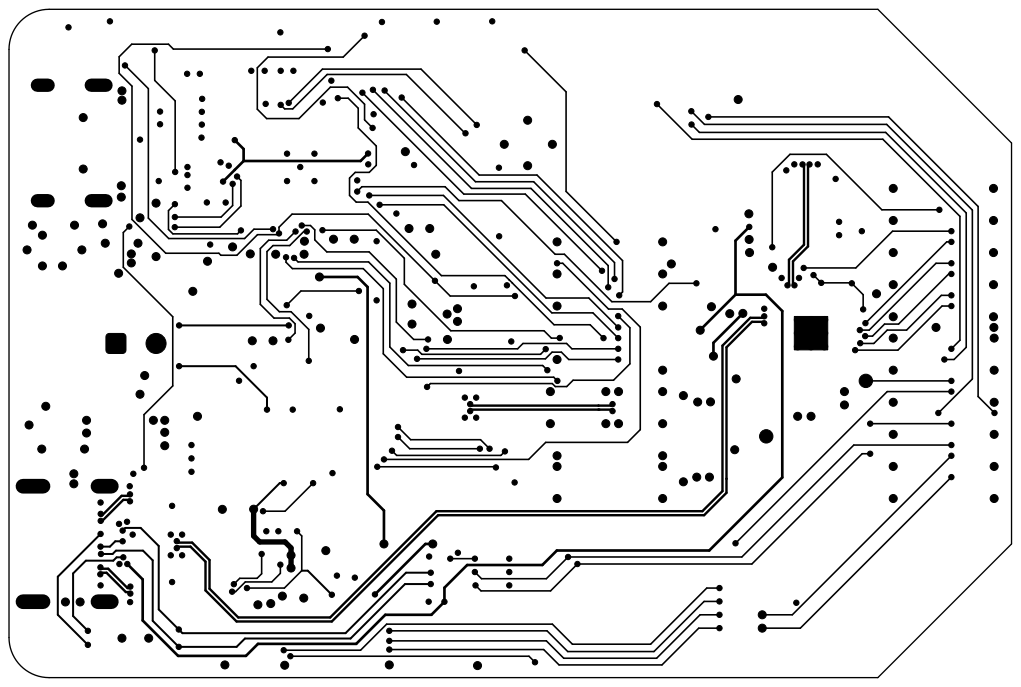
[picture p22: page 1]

the CERN-OHL-P a fund | v2 (https://cern.ch/cern-ohl). This documentation is distributed established by | NLnet foundation. This project was funded | through | under the terms of the | NGI0 Common | Fund,

USB3 Adapter File: usb3-gmm7550.kicad_pcb Sheet: Copyright (c) 2025 Anton | Kuzmin <ak@gmm7550.dev> Id: 4/11 Title: GMM-7550

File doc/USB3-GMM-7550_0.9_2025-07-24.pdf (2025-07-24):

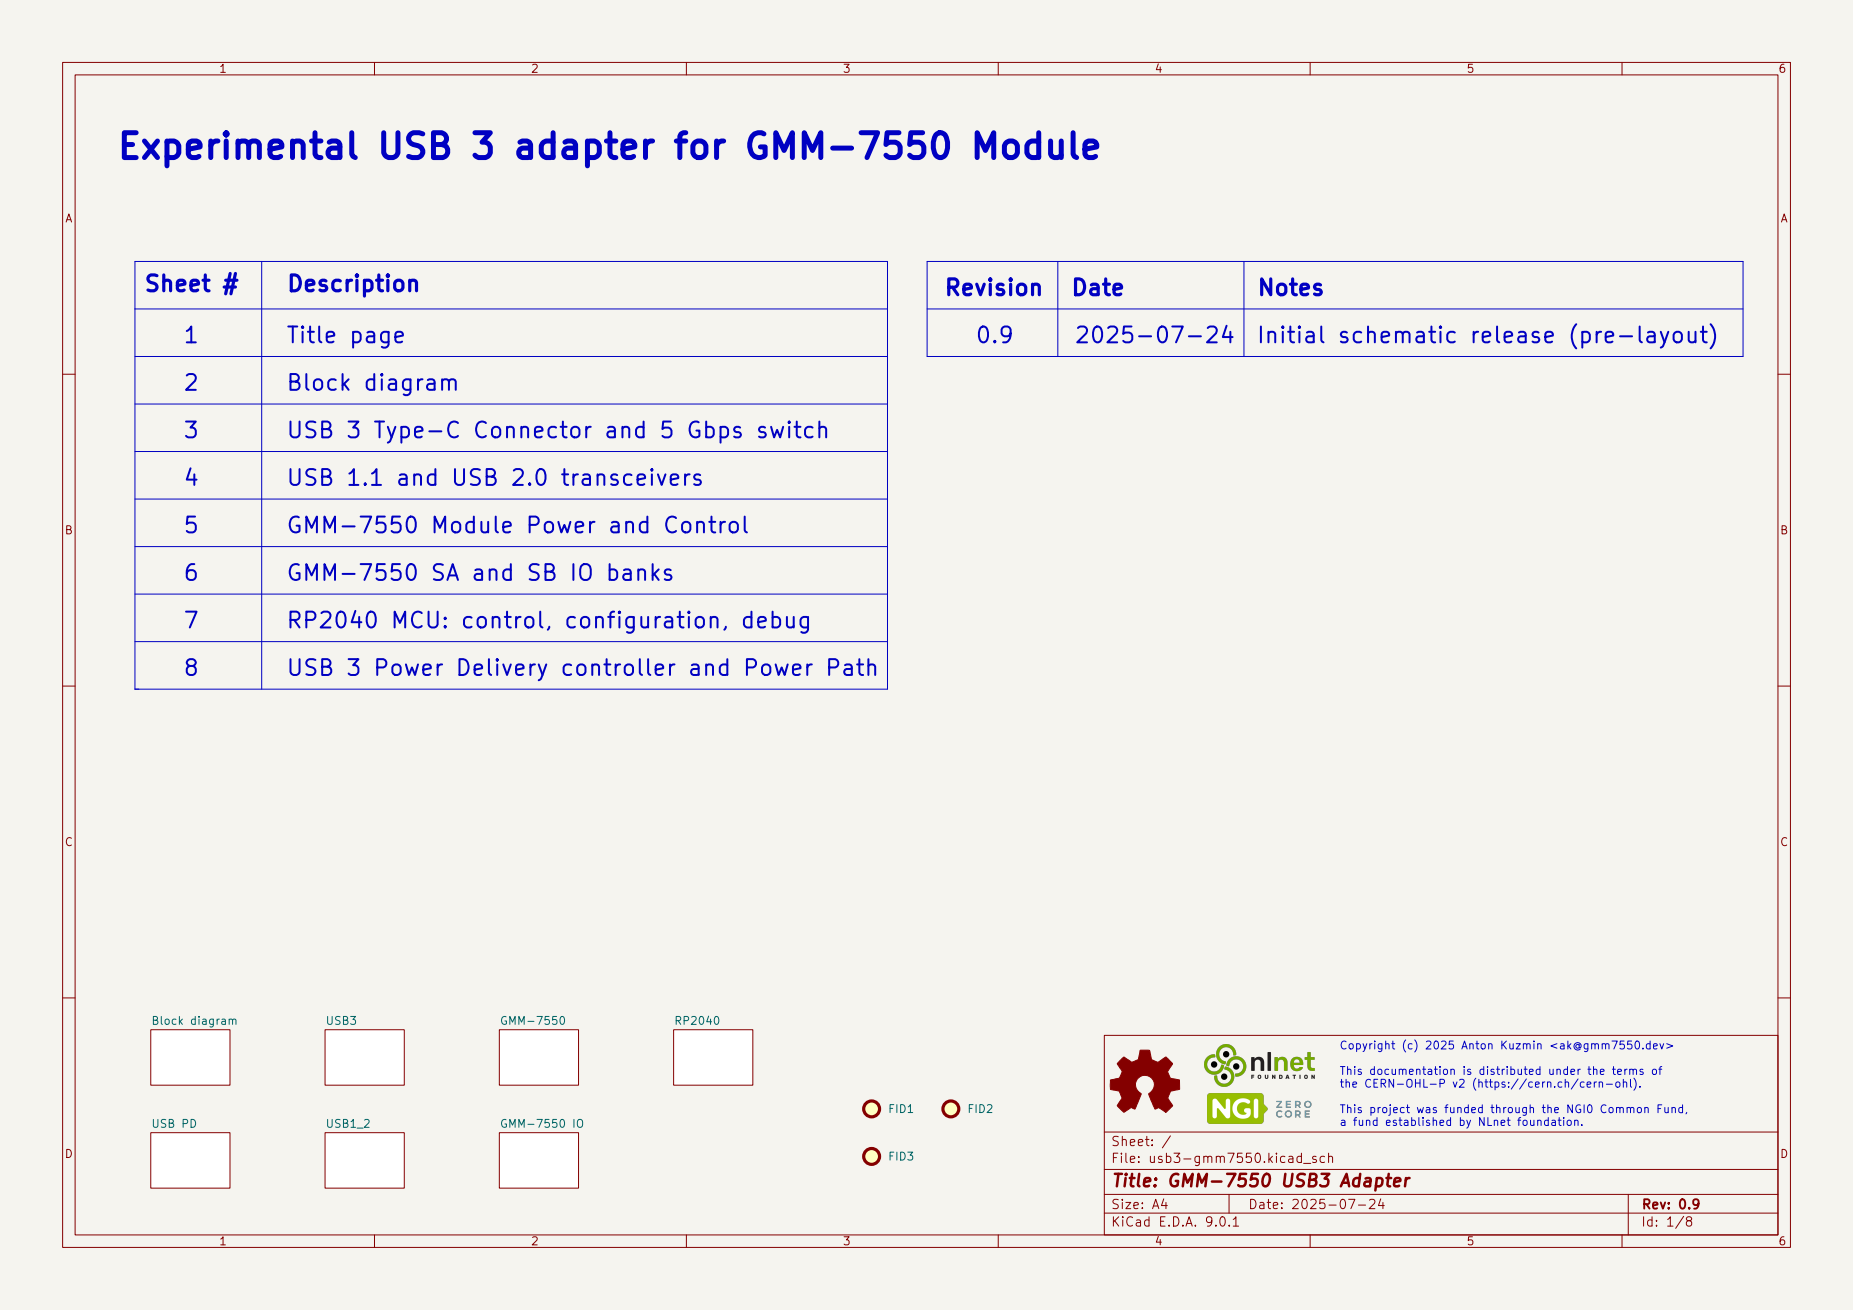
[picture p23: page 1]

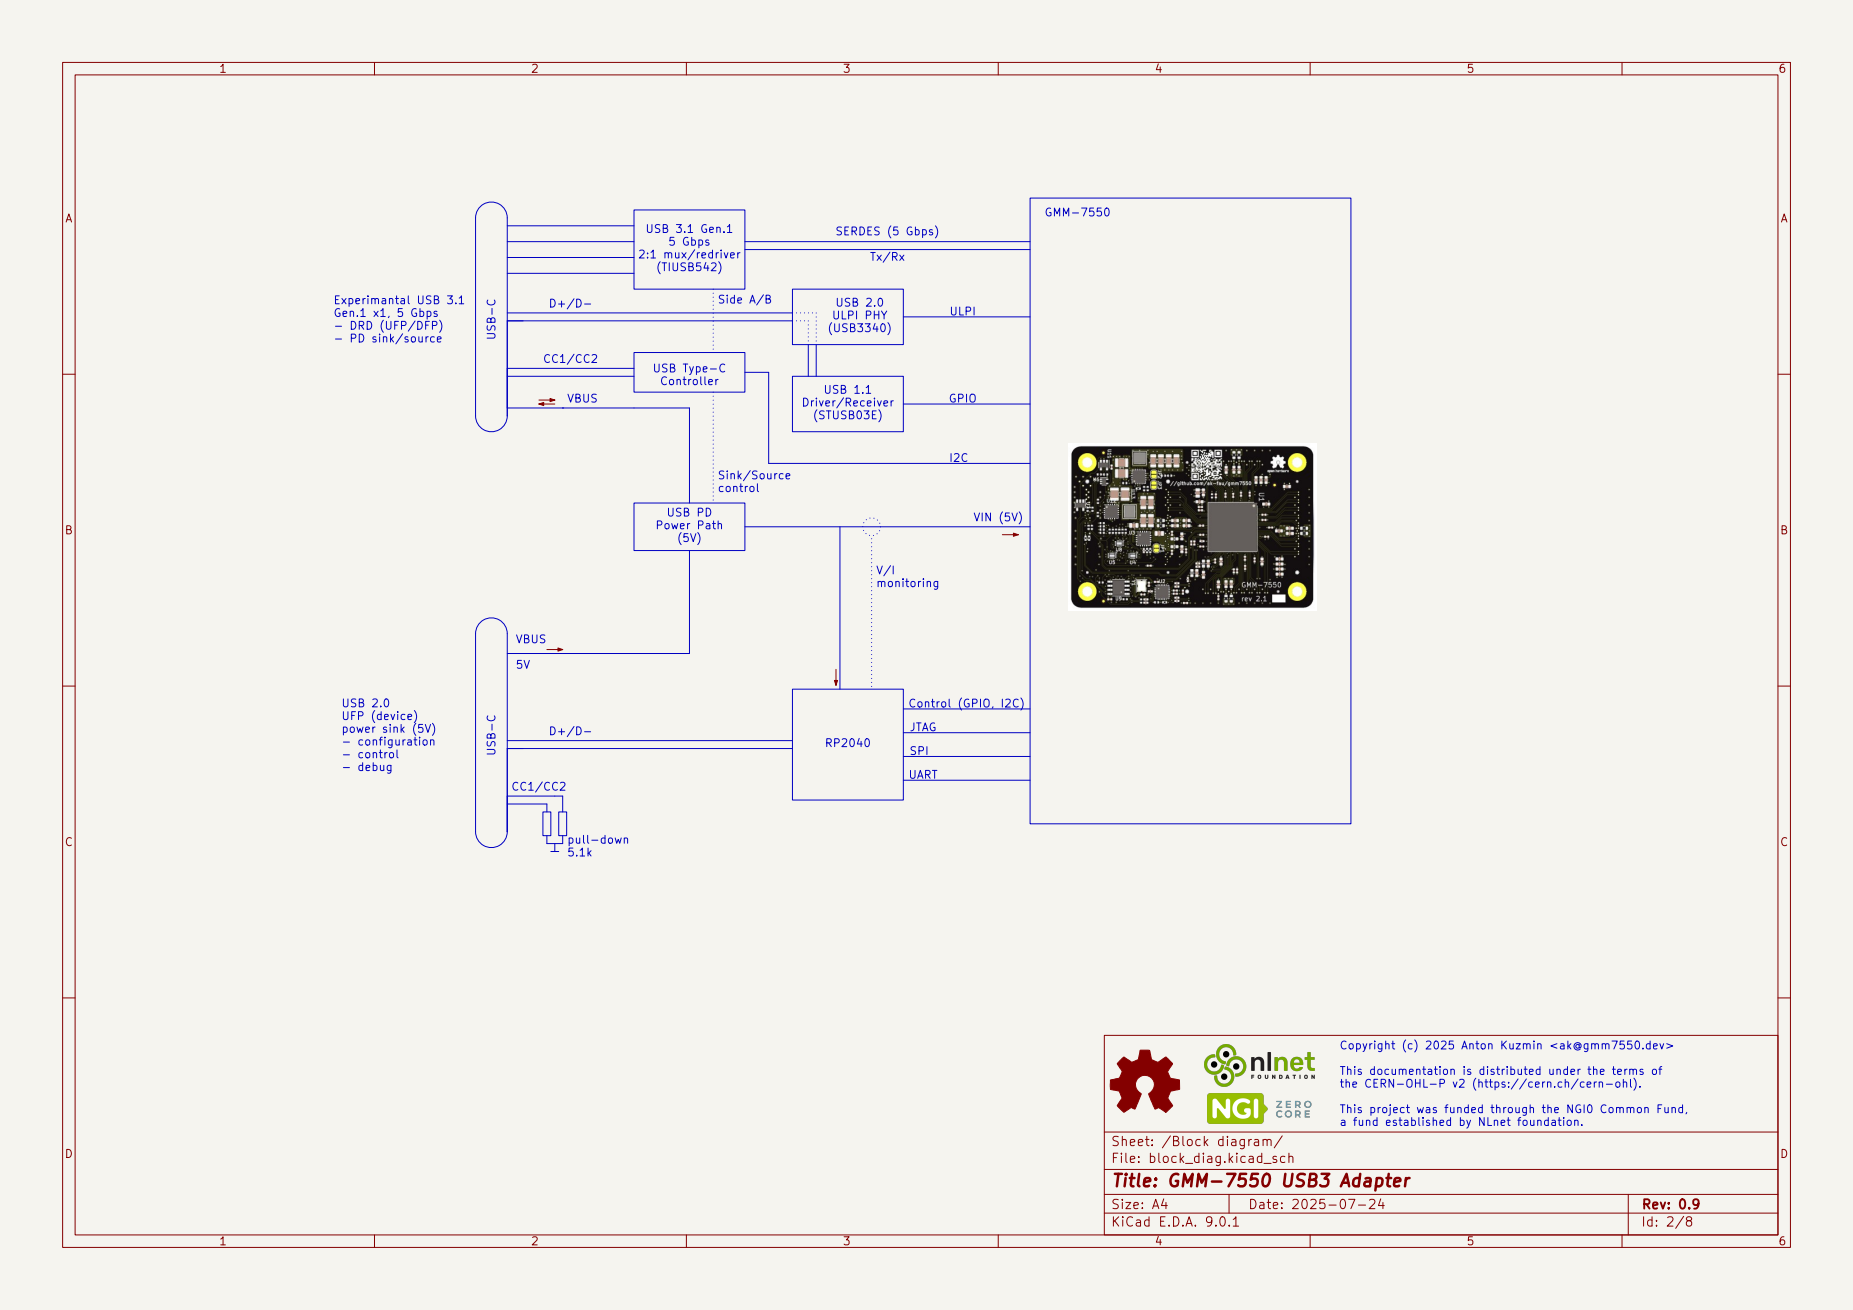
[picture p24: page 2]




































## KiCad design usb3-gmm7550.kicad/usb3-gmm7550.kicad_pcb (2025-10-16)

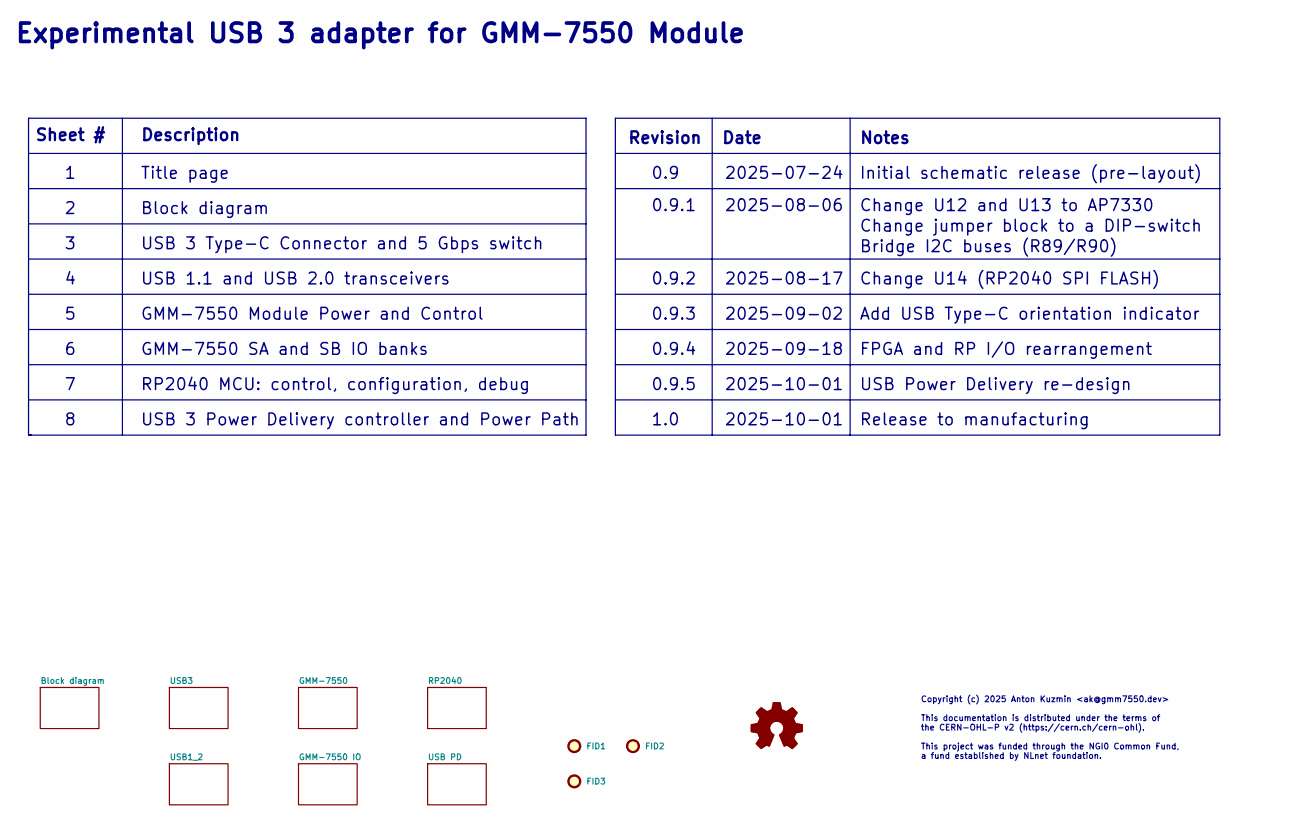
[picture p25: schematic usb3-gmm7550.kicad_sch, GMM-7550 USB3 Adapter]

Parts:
FID1, FID2, FID3: Fiducial; Fiducial_1mm_Mask2mm

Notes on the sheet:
Sheet #
Bridge I2C buses (R89/R90)
0.9
2025-09-02
Change U12 and U13 to AP7330
USB Power Delivery re-design
Revision
Title page
Release to manufacturing
2025-08-17
USB 1.1 and USB 2.0 transceivers
FPGA and RP I/O rearrangement
2025-09-18
Notes
Change U14 (RP2040 SPI FLASH)
GMM-7550 SA and SB IO banks
Date
USB 3 Type-C Connector and 5 Gbps switch
0.9.5
0.9.1
Block diagram
RP2040 MCU: control, configuration, debug
1.0
Experimental USB 3 adapter for GMM-7550 Module
USB 3 Power Delivery controller and Power Path
Initial schematic release (pre-layout)
0.9.2
0.9.3
2025-07-24
Change jumper block to a DIP-switch
2025-10-01
2025-08-06
Copyright (c) 2025 Anton Kuzmin <ak@gmm7550.dev> This documentation is distributed under the terms of the CERN-OHL-P v2 (https://cern.ch/cern-ohl). This project was funded through the NGI0 Common Fund, a fund established by NLnet foundation.
Add USB Type-C orientation indicator
Description
0.9.4
GMM-7550 Module Power and Control

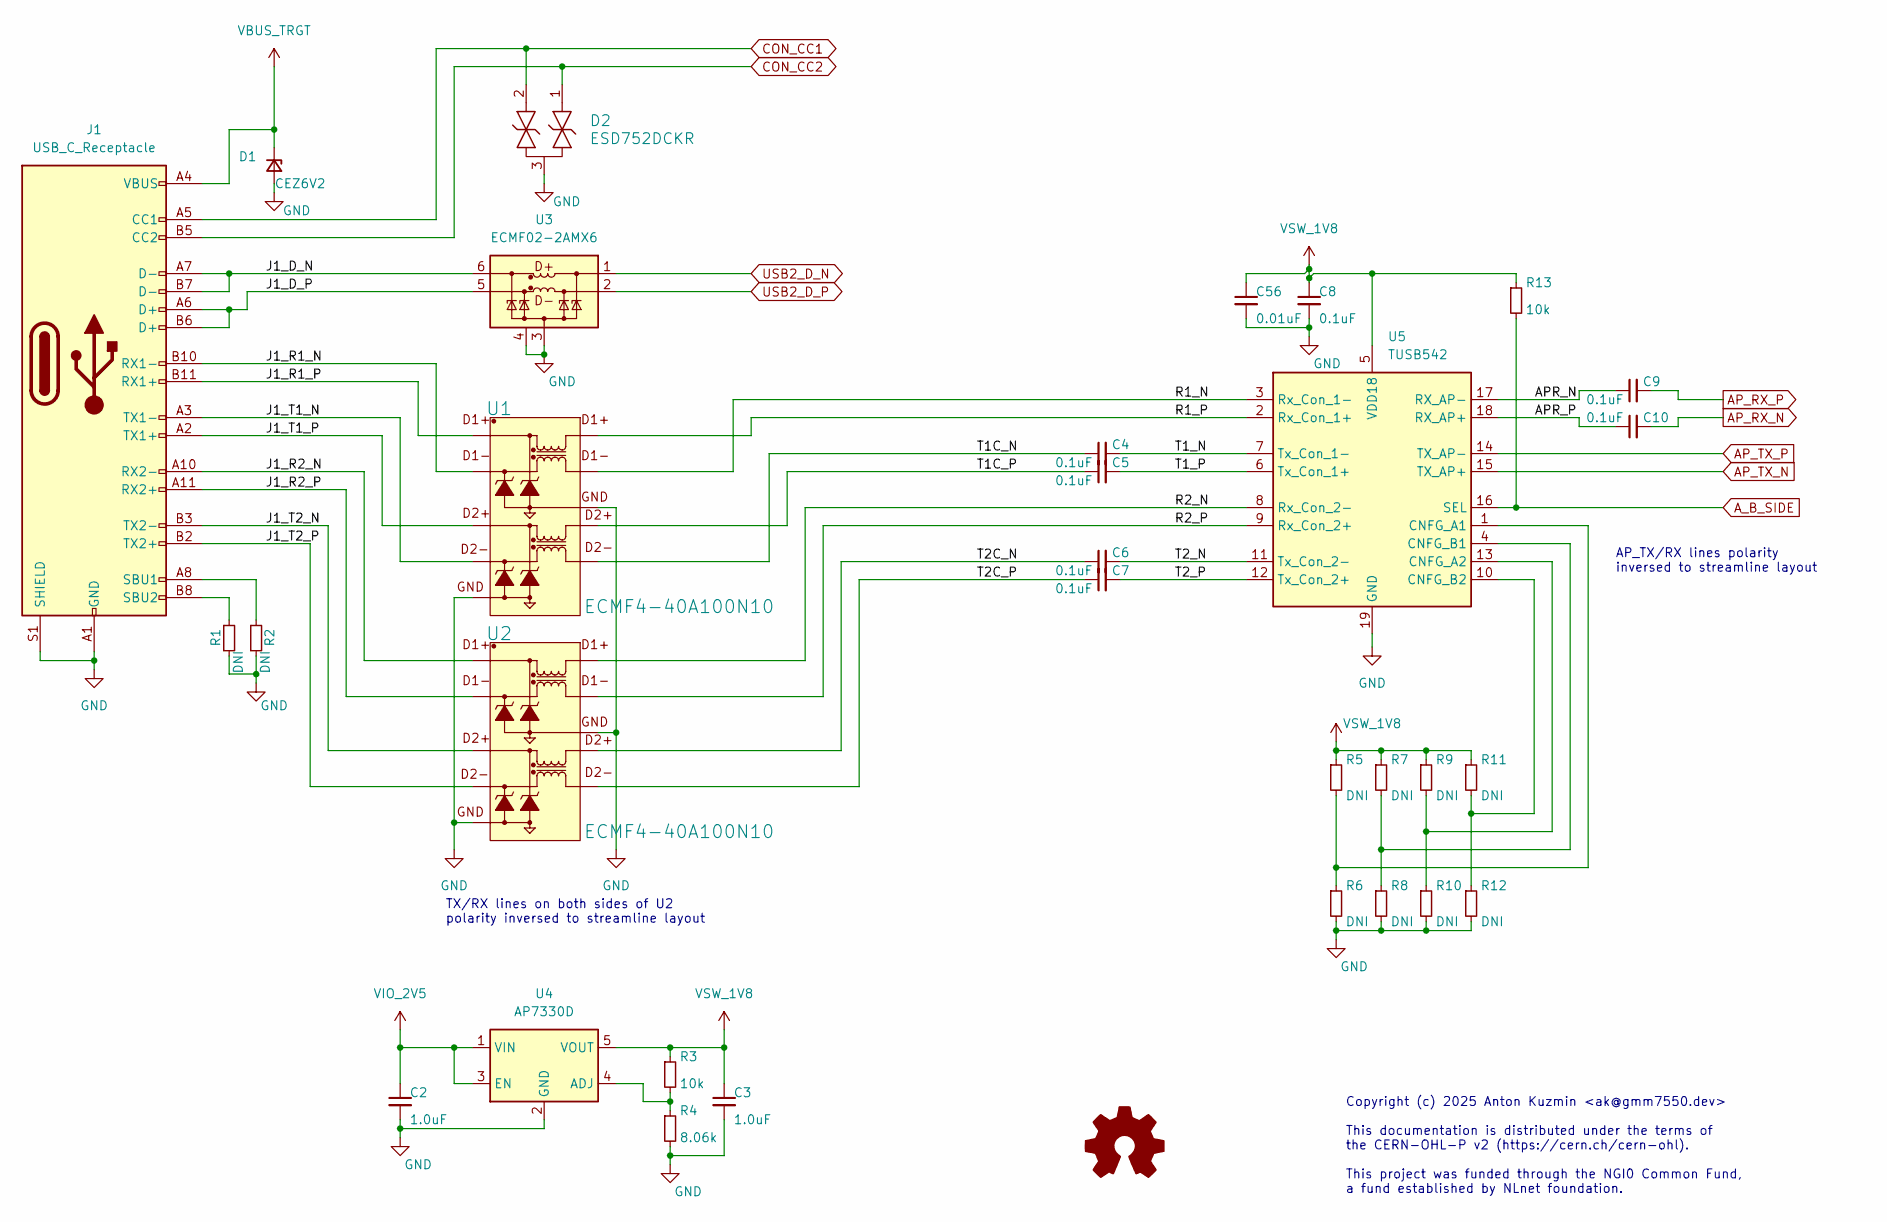
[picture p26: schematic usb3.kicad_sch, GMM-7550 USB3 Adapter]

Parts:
C2, C3: 1.0uF; C_0402_1005Metric
C4, C5, C6, C7, C8, C9, C10: 0.1uF; C_0402_1005Metric
C56: 0.01uF; C_0402_1005Metric
D1: CEZ6V2; D_SOD-523
D2: ESD752DCKR; SOT-SC70_DCK_TEX
J1: USB_C_Receptacle; USB_C_Receptacle_Molex_105450-0101
R1, R2, R5, R6, R7, R8, R9, R10, R11, R12: DNI; R_0402_1005Metric
R3, R13: 10k; R_0402_1005Metric
R4: 8.06k; R_0402_1005Metric
U1, U2: ECMF4-40A100N10; UQFN10L_1P4X2P25X0P4_STM
U3: ECMF02-2AMX6; ST_UQFN-6L_1.5x1.7mm_P0.5mm
U4: AP7330D; SOT-23-5
U5: TUSB542; Texas_X2QFN-18-1EP_2x2.4mm_P0.4mm_EP1x1.4mm_ThermalVias

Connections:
/USB3/APR_N: C9.1, U5.17 (RX_AP-)
/USB3/APR_P: C10.1, U5.18 (RX_AP+)
/USB3/J1_D_N: J1.A7 (D-), J1.B7 (D-), U3.6 (D+_out)
/USB3/J1_D_P: J1.A6 (D+), J1.B6 (D+), U3.5 (D-_out)
/USB3/J1_R1_N: J1.B10 (RX1-), U1.2 (D1-)
/USB3/J1_R1_P: J1.B11 (RX1+), U1.1 (D1+)
/USB3/J1_R2_N: J1.A10 (RX2-), U2.1 (D1+)
/USB3/J1_R2_P: J1.A11 (RX2+), U2.2 (D1-)
/USB3/J1_T1_N: J1.A3 (TX1-), U1.5 (D2-)
/USB3/J1_T1_P: J1.A2 (TX1+), U1.4 (D2+)
/USB3/J1_T2_N: J1.B3 (TX2-), U2.4 (D2+)
/USB3/J1_T2_P: J1.B2 (TX2+), U2.5 (D2-)
/USB3/R1_N: U1.9 (D1-1), U5.3 (Rx_Con_1-)
/USB3/R1_P: U1.10 (D1+1), U5.2 (Rx_Con_1+)
/USB3/R2_N: U2.10 (D1+1), U5.8 (Rx_Con_2-)
/USB3/R2_P: U2.9 (D1-1), U5.9 (Rx_Con_2+)
/USB3/T1C_N: C4.1, U1.6 (D2-1)
/USB3/T1C_P: C5.1, U1.7 (D2+1)
/USB3/T1_N: C4.2, U5.7 (Tx_Con_1-)
/USB3/T1_P: C5.2, U5.6 (Tx_Con_1+)
/USB3/T2C_N: C6.1, U2.7 (D2+1)
/USB3/T2C_P: C7.1, U2.6 (D2-1)
/USB3/T2_N: C6.2, U5.11 (Tx_Con_2-)
/USB3/T2_P: C7.2, U5.12 (Tx_Con_2+)
AP_RX_N: C10.2; also elsewhere on the board
AP_RX_P: C9.2; also elsewhere on the board
AP_TX_N: U5.15 (TX_AP+); also elsewhere on the board
AP_TX_P: U5.14 (TX_AP-); also elsewhere on the board
A_B_SIDE: R13.2, U5.16 (SEL); also elsewhere on the board
CON_CC1: D2.2, J1.A5 (CC1); also elsewhere on the board
CON_CC2: D2.1, J1.B5 (CC2); also elsewhere on the board
GND: C2.2, C3.2, C8.2, C56.2, D1.2 (A), D2.3, J1.A1 (GND), J1.A12 (GND), J1.B1 (GND), J1.B12 (GND), J1.S1 (SHIELD), R1.2, R2.2, R4.2, R6.2, R8.2, R10.2, R12.2, U1.3 (GND), U1.8 (GND1), U2.3 (GND), U2.8 (GND1), U3.3 (GND), U3.4 (NC), U4.2 (GND), U5.19 (GND); also elsewhere on the board
unnamed: J1.A8 (SBU1), R2.1
unnamed: J1.B8 (SBU2), R1.1
unnamed: R3.2, R4.1, U4.4 (ADJ)
unnamed: R5.2, R6.1, U5.1 (CNFG_A1)
unnamed: R9.2, R10.1, U5.13 (CNFG_A2)
unnamed: R7.2, R8.1, U5.4 (CNFG_B1)
unnamed: R11.2, R12.1, U5.10 (CNFG_B2)
USB2_D_N: U3.1 (D+_in); also elsewhere on the board
USB2_D_P: U3.2 (D-_in); also elsewhere on the board
VBUS_TRGT: D1.1 (K), J1.A4 (VBUS), J1.A9 (VBUS), J1.B4 (VBUS), J1.B9 (VBUS); also elsewhere on the board
VIO_2V5: C2.1, U4.1 (VIN), U4.3 (EN); also elsewhere on the board
VSW_1V8: C3.1, C8.1, C56.1, R3.1, R5.1, R7.1, R9.1, R11.1, R13.1, U4.5 (VOUT), U5.5 (VDD18)

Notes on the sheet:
Copyright (c) 2025 Anton Kuzmin <ak@gmm7550.dev> This documentation is distributed under the terms of the CERN-OHL-P v2 (https://cern.ch/cern-ohl). This project was funded through the NGI0 Common Fund, a fund established by NLnet foundation.
TX/RX lines on both sides of U2 polarity inversed to streamline layout
AP_TX/RX lines polarity inversed to streamline layout

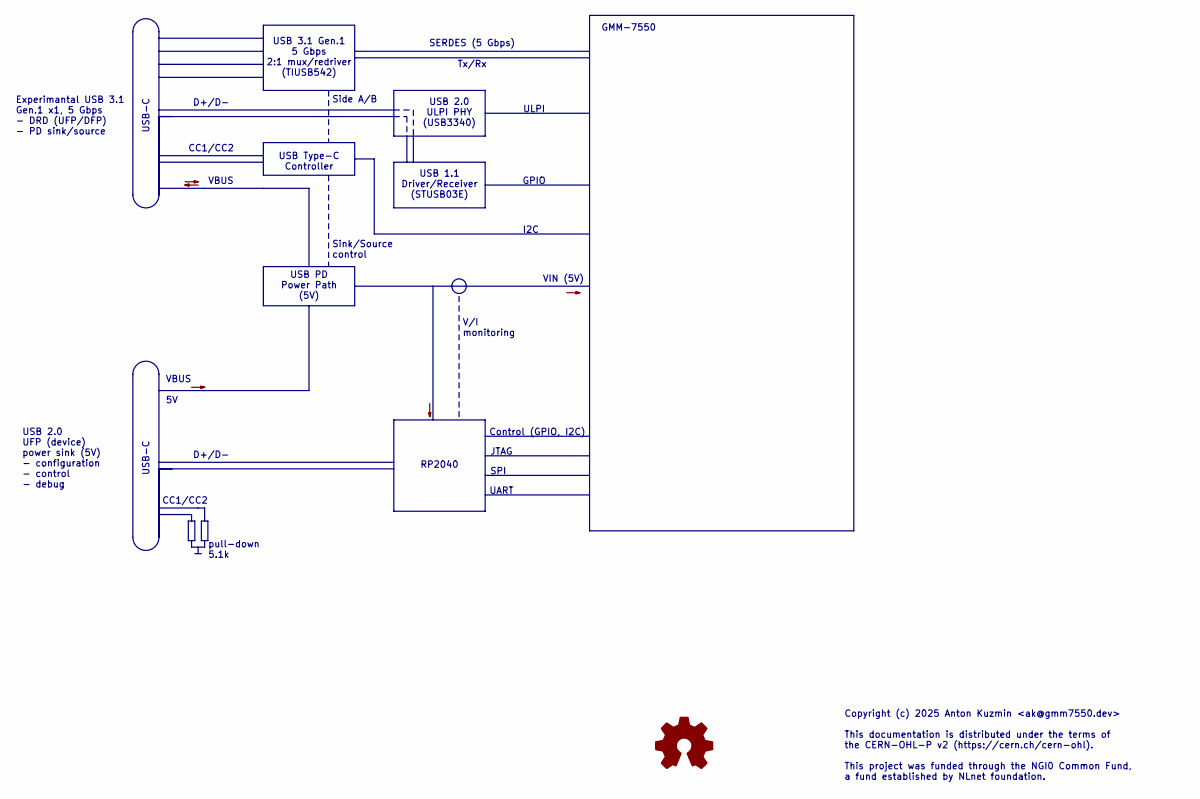
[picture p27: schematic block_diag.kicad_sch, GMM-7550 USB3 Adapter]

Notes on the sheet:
USB PD Power Path (5V)
Sink/Source control
USB Type-C Controller
Side A/B
CC1/CC2
ULPI
D+/D-
GMM-7550
USB 2.0 ULPI PHY (USB3340)
Copyright (c) 2025 Anton Kuzmin <ak@gmm7550.dev> This documentation is distributed under the terms of the CERN-OHL-P v2 (https://cern.ch/cern-ohl). This project was funded through the NGI0 Common Fund, a fund established by NLnet foundation.
SPI
VBUS 5V
pull-down 5.1k
UART
USB-C
Experimantal USB 3.1 Gen.1 x1, 5 Gbps - DRD (UFP/DFP) - PD sink/source
Control (GPIO, I2C)
USB 2.0 UFP (device) power sink (5V) - configuration - control - debug
USB 1.1 Driver/Receiver (STUSB03E)
VBUS
SERDES (5 Gbps) Tx/Rx
JTAG
I2C
V/I monitoring
GPIO
RP2040
USB 3.1 Gen.1 5 Gbps 2:1 mux/redriver (TIUSB542)
VIN (5V)

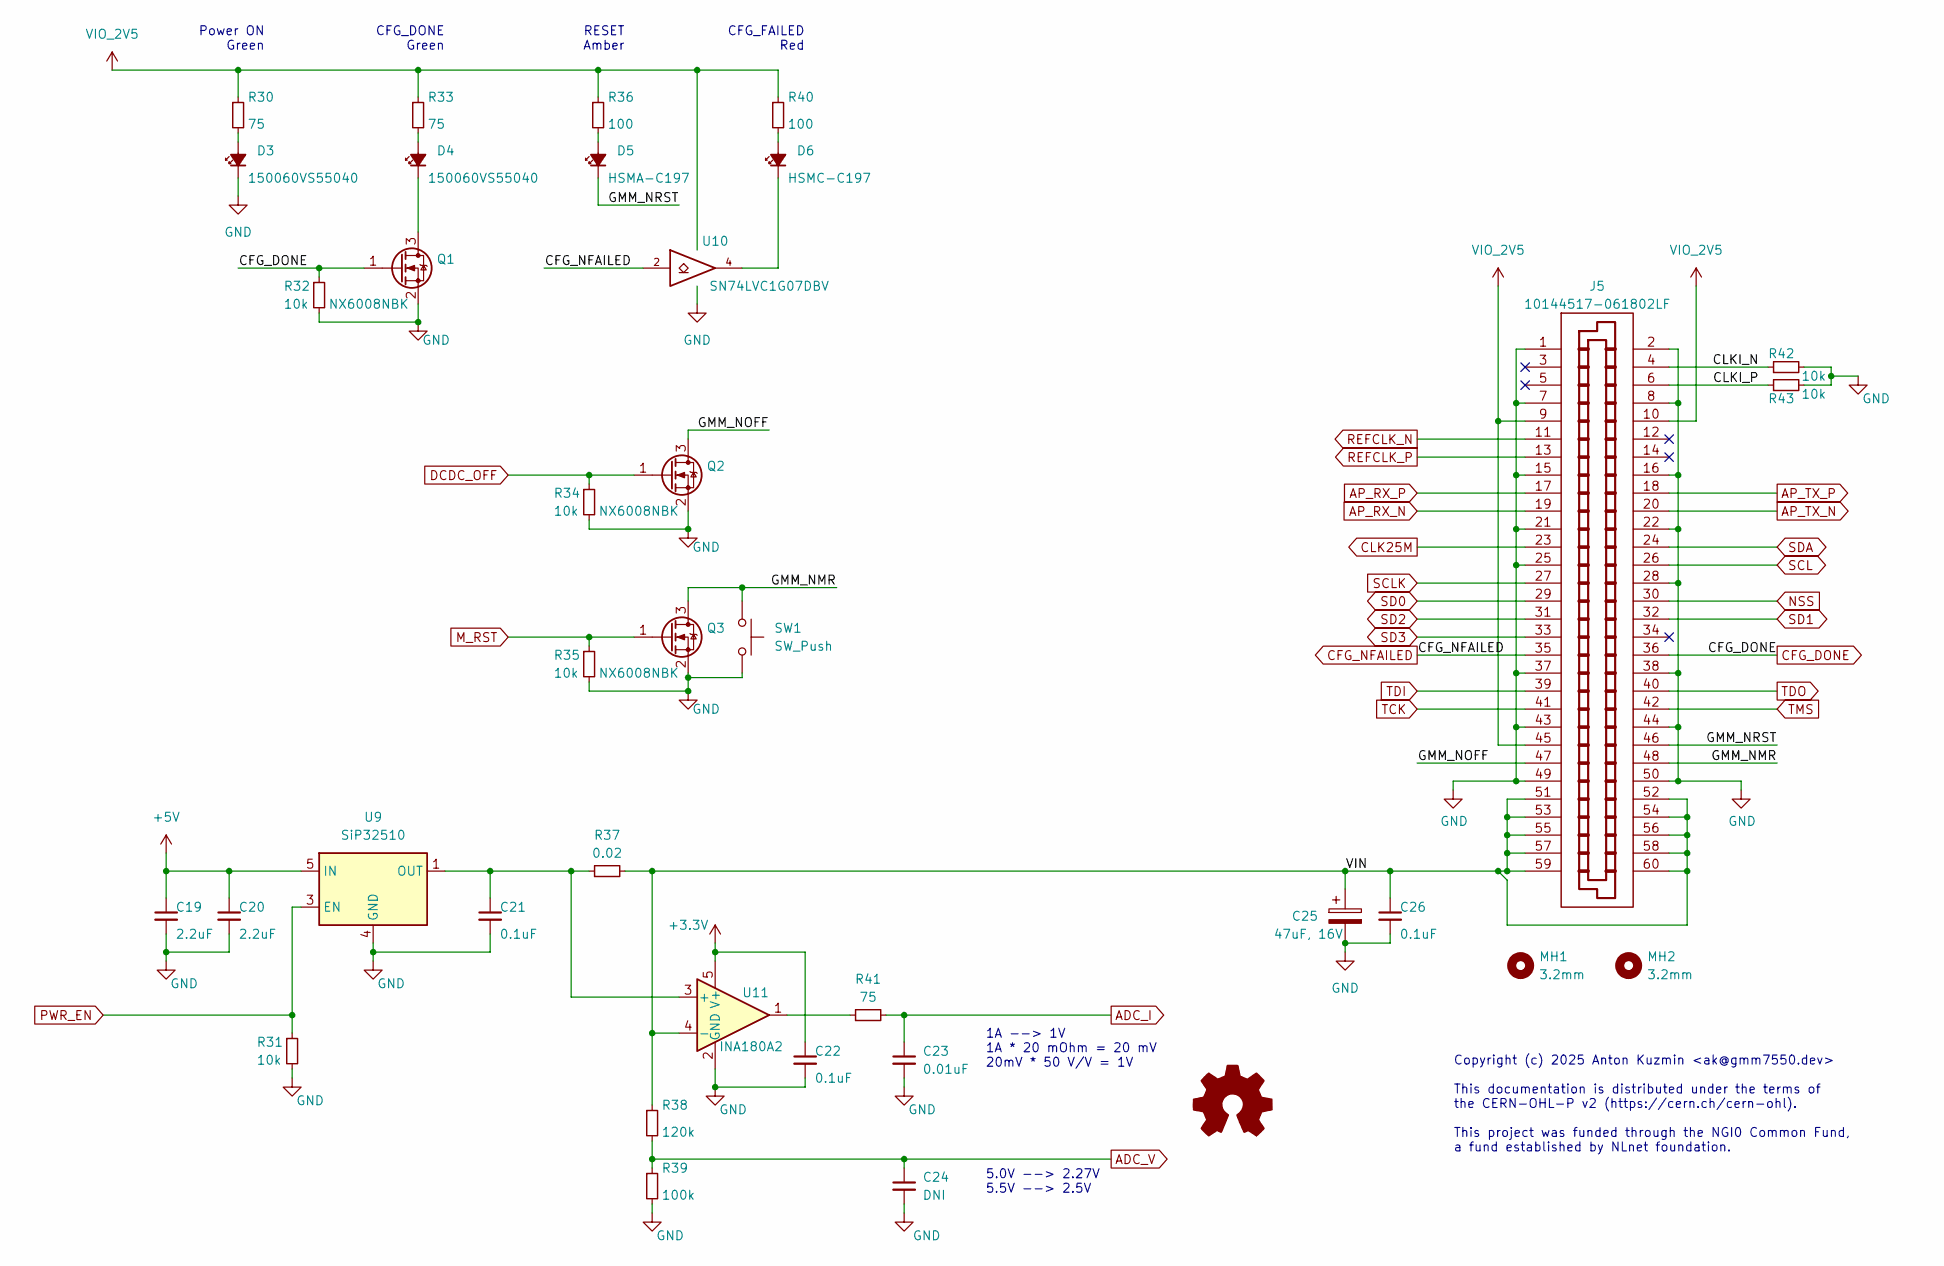
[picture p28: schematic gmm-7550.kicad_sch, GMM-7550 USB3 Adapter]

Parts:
C19, C20: 2.2uF; C_0603_1608Metric
C21, C22, C26: 0.1uF; C_0402_1005Metric
C23: 0.01uF; C_0402_1005Metric
C24: DNI; C_0402_1005Metric
C25: 47uF, 16V; CP_EIA-6032-28_Kemet-C
D3, D4: 150060VS55040; LED_0603_1608Metric
D5: HSMA-C197; LED_0603_1608Metric
D6: HSMC-C197; LED_0603_1608Metric
J5: 10144517-061802LF
MH1, MH2: 3.2mm; MountingHole_3.2mm_M3_ISO7380
Q1, Q2, Q3: NX6008NBK; SOT-23
R30, R33, R41: 75; R_0402_1005Metric
R31, R32, R34, R35, R42, R43: 10k; R_0402_1005Metric
R36, R40: 100; R_0402_1005Metric
R37: 0.02; R_0805_2012Metric; MPN PE0805FRE470R02Z
R38: 120k; R_0402_1005Metric
R39: 100k; R_0402_1005Metric
SW1: SW_Push; SW_SPST_PTS810
U9: SiP32510; SOT-23-6
U10: SN74LVC1G07DBV; SOT-23-5
U11: INA180A2; SOT-23-5

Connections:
+3.3V: C22.1, U11.5 (V+); also elsewhere on the board
+5V: C19.1, C20.1, U9.5 (IN), U9.6 (IN); also elsewhere on the board
/GMM-7550/CLKI_N: J5.4, R42.1
/GMM-7550/CLKI_P: J5.6, R43.1
/GMM-7550/GMM_NMR: J5.48, Q3.3 (D), SW1.1
/GMM-7550/GMM_NOFF: J5.47, Q2.3 (D)
/GMM-7550/GMM_NRST: D5.1 (K), J5.46
/GMM-7550/VIN: C25.1, C26.1, J5.51, J5.52, J5.53, J5.54, J5.55, J5.56, J5.57, J5.58, J5.59, J5.60, R37.2, R38.1, U11.4 (-)
ADC_I: C23.1, R41.2; also elsewhere on the board
ADC_V: C24.1, R38.2, R39.1; also elsewhere on the board
AP_RX_N: J5.19; also elsewhere on the board
AP_RX_P: J5.17; also elsewhere on the board
AP_TX_N: J5.20; also elsewhere on the board
AP_TX_P: J5.18; also elsewhere on the board
CFG_DONE: J5.36, Q1.1 (G), R32.1; also elsewhere on the board
CFG_NFAILED: J5.35, U10.2; also elsewhere on the board
CLK25M: J5.23; also elsewhere on the board
DCDC_OFF: Q2.1 (G), R34.1; also elsewhere on the board
GND: C19.2, C20.2, C21.2, C22.2, C23.2, C24.2, C25.2, C26.2, D3.1 (K), J5.1, J5.2, J5.7, J5.8, J5.15, J5.16, J5.21, J5.22, J5.25, J5.28, J5.37, J5.38, J5.43, J5.44, J5.49, J5.50, Q1.2 (S), Q2.2 (S), Q3.2 (S), R31.2, R32.2, R34.2, R35.2, R39.2, R42.2, R43.2, SW1.2, U9.4 (GND), U10.3 (GND), U11.2 (GND); also elsewhere on the board
M_RST: Q3.1 (G), R35.1; also elsewhere on the board
NSS: J5.30; also elsewhere on the board
unnamed: D3.2 (A), R30.2
unnamed: D4.2 (A), R33.2
unnamed: D4.1 (K), Q1.3 (D)
unnamed: D5.2 (A), R36.2
unnamed: D6.2 (A), R40.2
unnamed: D6.1 (K), U10.4
unnamed: R41.1, U11.1
unnamed: C21.1, R37.1, U9.1 (OUT), U9.2 (OUT), U11.3 (+)
PWR_EN: R31.1, U9.3 (EN); also elsewhere on the board
REFCLK_N: J5.11; also elsewhere on the board
REFCLK_P: J5.13; also elsewhere on the board
SCL: J5.26; also elsewhere on the board
SCLK: J5.27; also elsewhere on the board
SD0: J5.29; also elsewhere on the board
SD1: J5.32; also elsewhere on the board
SD2: J5.31; also elsewhere on the board
SD3: J5.33; also elsewhere on the board
SDA: J5.24; also elsewhere on the board
TCK: J5.41; also elsewhere on the board
TDI: J5.39; also elsewhere on the board
TDO: J5.40; also elsewhere on the board
TMS: J5.42; also elsewhere on the board
VIO_2V5: J5.9, J5.10, J5.45, R30.1, R33.1, R36.1, R40.1, U10.5 (VCC); also elsewhere on the board

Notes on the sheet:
5.0V --> 2.27V 5.5V --> 2.5V
RESET Amber
CFG_FAILED Red
CFG_DONE Green
Copyright (c) 2025 Anton Kuzmin <ak@gmm7550.dev> This documentation is distributed under the terms of the CERN-OHL-P v2 (https://cern.ch/cern-ohl). This project was funded through the NGI0 Common Fund, a fund established by NLnet foundation.
1A --> 1V 1A * 20 mOhm = 20 mV 20mV * 50 V/V = 1V
Power ON Green

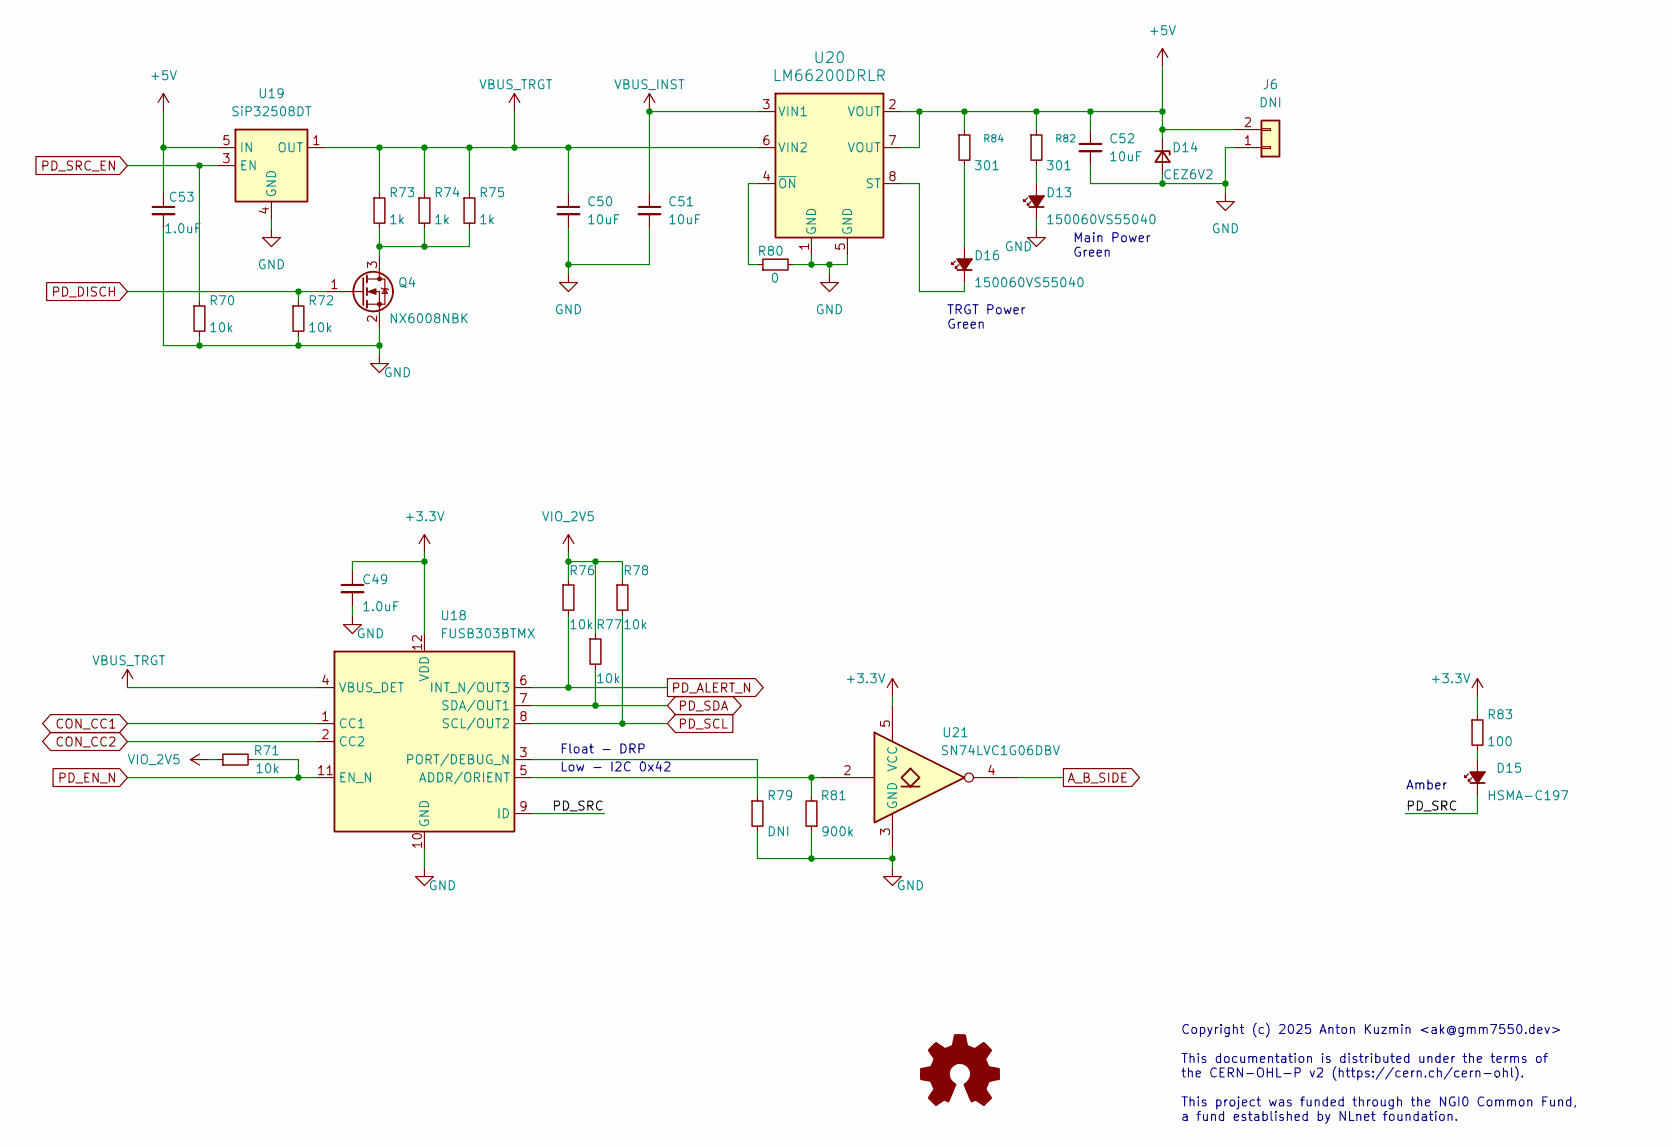
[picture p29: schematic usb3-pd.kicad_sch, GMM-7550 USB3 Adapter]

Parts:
C49, C53: 1.0uF; C_0402_1005Metric
C50, C51, C52: 10uF; C_0805_2012Metric
D13, D16: 150060VS55040; LED_0603_1608Metric
D14: CEZ6V2; D_SOD-523
D15: HSMA-C197; LED_0603_1608Metric
J6: DNI; Molex_Micro-Fit_3.0_43045-0200_2x01_P3.00mm_Horizontal
Q4: NX6008NBK; SOT-23
R70, R71, R72, R76, R77, R78: 10k; R_0402_1005Metric
R73, R74, R75: 1k; R_0402_1005Metric
R79: DNI; R_0402_1005Metric
R80: 0; R_0402_1005Metric
R81: 900k; R_0402_1005Metric
R82, R84: 301; R_0402_1005Metric
R83: 100; R_0402_1005Metric
U18: FUSB303BTMX; OnSemi_X2QFN-12_1.6x1.6mm; Manufacturer_Part_Number FUSB303BTMX; Mouser Part Number 863-FUSB303BTMX
U19: SiP32508DT; TSOT-23-6
U20: LM66200DRLR; SOT-5X3_DRL_TEX
U21: SN74LVC1G06DBV; SOT-23-5

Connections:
+3.3V: C49.1, R83.1, U18.12 (VDD), U21.5 (VCC); also elsewhere on the board
+5V: C52.1, C53.1, D14.1 (K), J6.2, R82.1, R84.1, U19.5 (IN), U19.6 (IN), U20.2 (VOUT), U20.7 (VOUT); also elsewhere on the board
/USB PD/PD_SRC: D15.1 (K), U18.9 (ID)
A_B_SIDE: U21.4; also elsewhere on the board
CON_CC1: U18.1 (CC1); also elsewhere on the board
CON_CC2: U18.2 (CC2); also elsewhere on the board
GND: C49.2, C50.2, C51.2, C52.2, C53.2, D13.1 (K), D14.2 (A), J6.1, Q4.2 (S), R70.2, R72.2, R79.2, R80.2, R81.1, U18.10 (GND), U19.4 (GND), U20.1 (GND), U20.5 (GND), U21.3 (GND); also elsewhere on the board
unnamed: D13.2 (A), R82.2
unnamed: D15.2 (A), R83.2
unnamed: D16.2 (A), R84.2
unnamed: D16.1 (K), U20.8 (ST)
unnamed: Q4.3 (D), R73.2, R74.2, R75.2
unnamed: R81.2, U18.5 (ADDR/ORIENT), U21.2
unnamed: R79.1, U18.3 (PORT/DEBUG_N)
unnamed: R80.1, U20.4 (~ON)
PD_ALERT_N: R76.2, U18.6 (INT_N/OUT3); also elsewhere on the board
PD_DISCH: Q4.1 (G), R72.1; also elsewhere on the board
PD_EN_N: R71.2, U18.11 (EN_N); also elsewhere on the board
PD_SCL: R78.2, U18.8 (SCL/OUT2); also elsewhere on the board
PD_SDA: R77.2, U18.7 (SDA/OUT1); also elsewhere on the board
PD_SRC_EN: R70.1, U19.3 (EN); also elsewhere on the board
VBUS_INST: C51.1, U20.3 (VIN1); also elsewhere on the board
VBUS_TRGT: C50.1, R73.1, R74.1, R75.1, U18.4 (VBUS_DET), U19.1 (OUT), U19.2 (OUT), U20.6 (VIN2); also elsewhere on the board
VIO_2V5: R71.1, R76.1, R77.1, R78.1; also elsewhere on the board

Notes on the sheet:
Amber
Copyright (c) 2025 Anton Kuzmin <ak@gmm7550.dev> This documentation is distributed under the terms of the CERN-OHL-P v2 (https://cern.ch/cern-ohl). This project was funded through the NGI0 Common Fund, a fund established by NLnet foundation.
Float - DRP
Low - I2C 0x42
Main Power Green
TRGT Power Green

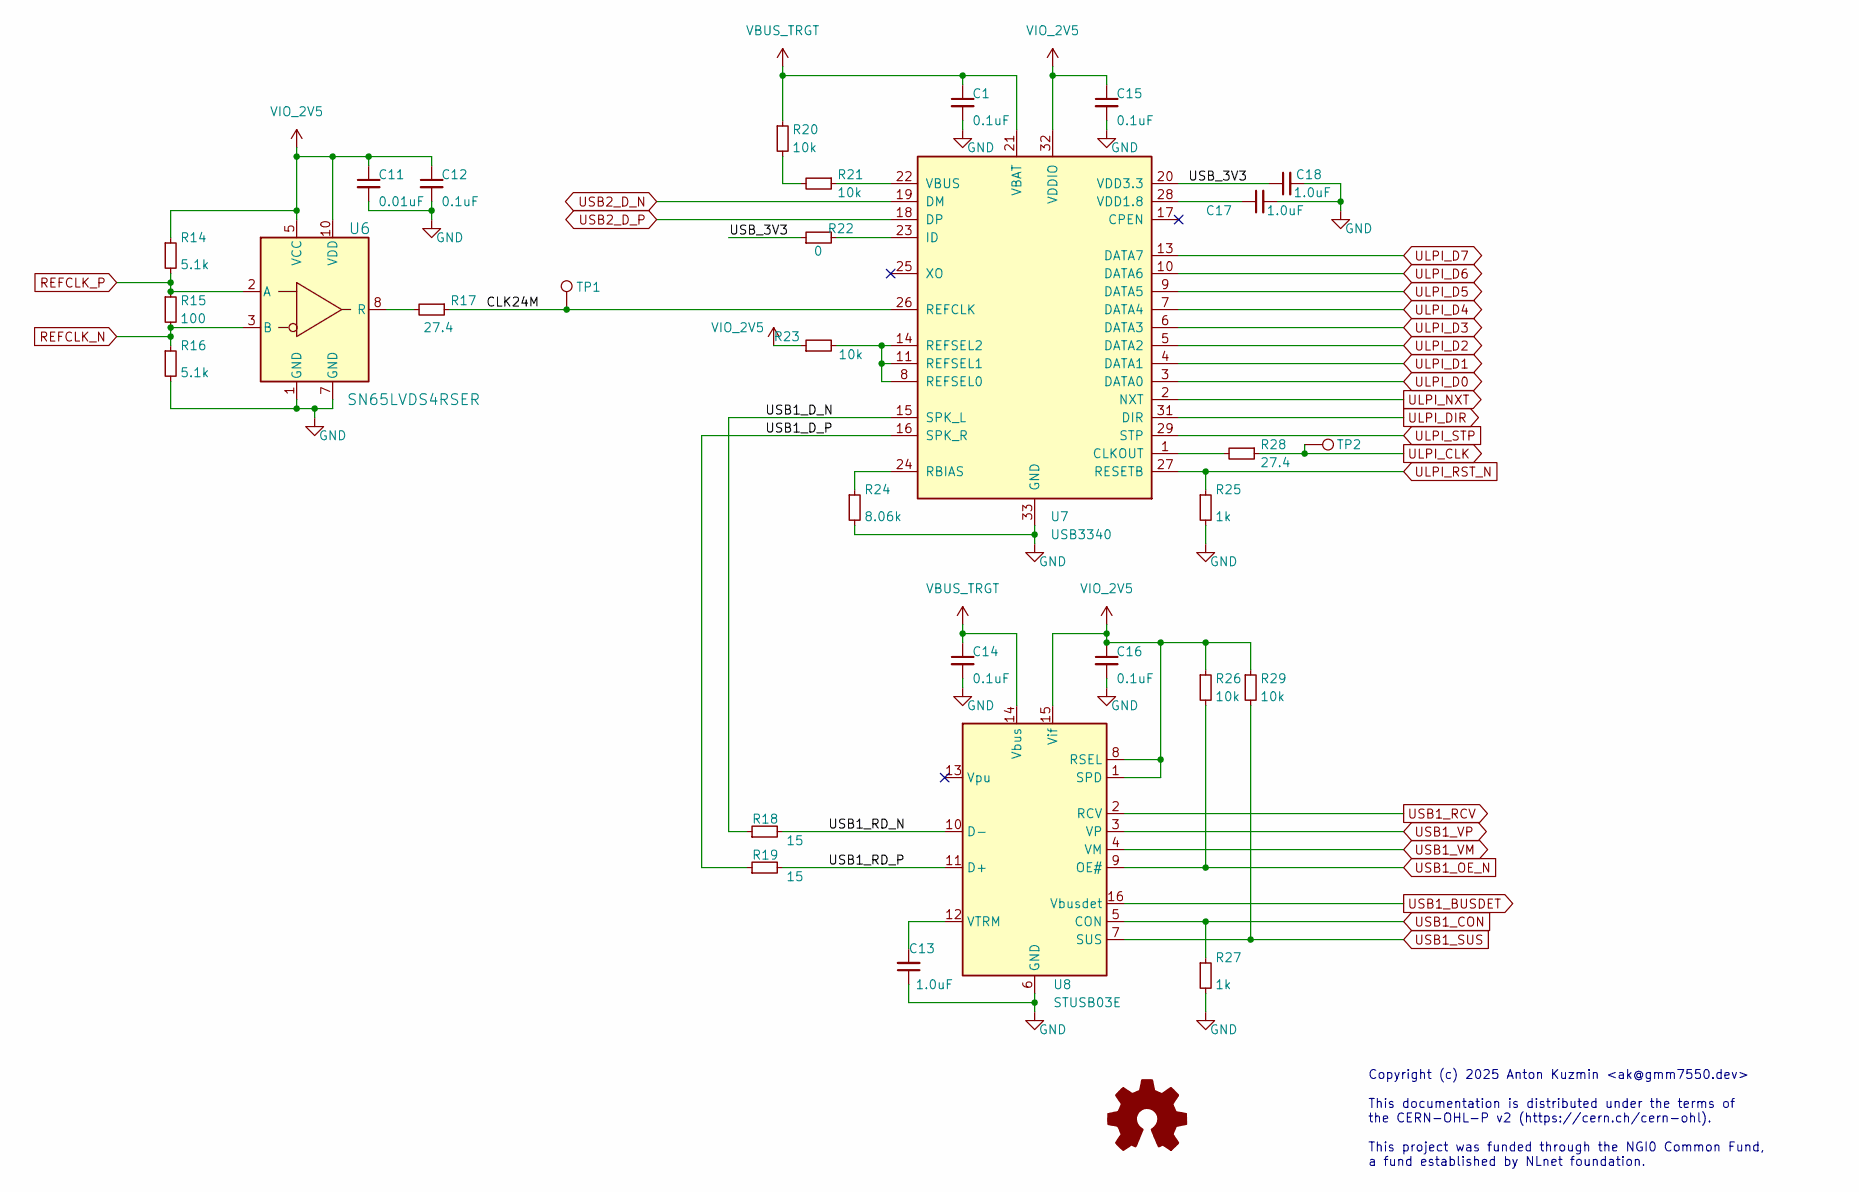
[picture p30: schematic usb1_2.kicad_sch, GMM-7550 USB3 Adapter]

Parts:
C1, C12, C14, C15, C16: 0.1uF; C_0402_1005Metric
C11: 0.01uF; C_0402_1005Metric
C13, C17, C18: 1.0uF; C_0402_1005Metric
R14, R16: 5.1k; R_0402_1005Metric
R15: 100; R_0402_1005Metric
R17, R28: 27.4; R_0402_1005Metric
R18, R19: 15; R_0402_1005Metric
R20, R21, R23, R26, R29: 10k; R_0402_1005Metric
R22: 0; R_0402_1005Metric
R24: 8.06k; R_0402_1005Metric
R25, R27: 1k; R_0402_1005Metric
TP1, TP2: TestPoint; TestPoint_Pad_D1.0mm
U6: SN65LVDS4RSER; RSE10
U7: USB3340; QFN-32-1EP_5x5mm_P0.5mm_EP3.3x3.3mm_ThermalVias
U8: STUSB03E; QFN-16-1EP_3x3mm_P0.5mm_EP1.7x1.7mm

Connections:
/USB1_2/CLK24M: R17.1, TP1.1, U7.26 (REFCLK)
/USB1_2/USB1_D_N: R18.1, U7.15 (SPK_L)
/USB1_2/USB1_D_P: R19.1, U7.16 (SPK_R)
/USB1_2/USB1_RD_N: R18.2, U8.10 (D-)
/USB1_2/USB1_RD_P: R19.2, U8.11 (D+)
/USB1_2/USB_3V3: C18.1, R22.1, U7.20 (VDD3.3)
GND: C1.2, C11.2, C12.2, C13.1, C14.2, C15.2, C16.2, C17.2, C18.2, R16.2, R24.2, R25.2, R27.2, U6.1 (GND), U6.7 (GND), U7.33 (GND), U8.6 (GND); also elsewhere on the board
unnamed: R20.2, R21.2
unnamed: R17.2, U6.8 (R)
unnamed: R28.2, U7.1 (CLKOUT)
unnamed: R22.2, U7.23 (ID)
unnamed: R24.1, U7.24 (RBIAS)
unnamed: R23.2, U7.8 (REFSEL0), U7.11 (REFSEL1), U7.14 (REFSEL2)
unnamed: R21.1, U7.22 (VBUS)
unnamed: C17.1, U7.28 (VDD1.8)
unnamed: C13.2, U8.12 (VTRM)
REFCLK_N: R15.2, R16.1, U6.3 (B); also elsewhere on the board
REFCLK_P: R14.2, R15.1, U6.2 (A); also elsewhere on the board
ULPI_CLK: R28.1, TP2.1; also elsewhere on the board
ULPI_D0: U7.3 (DATA0); also elsewhere on the board
ULPI_D1: U7.4 (DATA1); also elsewhere on the board
ULPI_D2: U7.5 (DATA2); also elsewhere on the board
ULPI_D3: U7.6 (DATA3); also elsewhere on the board
ULPI_D4: U7.7 (DATA4); also elsewhere on the board
ULPI_D5: U7.9 (DATA5); also elsewhere on the board
ULPI_D6: U7.10 (DATA6); also elsewhere on the board
ULPI_D7: U7.13 (DATA7); also elsewhere on the board
ULPI_DIR: U7.31 (DIR); also elsewhere on the board
ULPI_NXT: U7.2 (NXT); also elsewhere on the board
ULPI_RST_N: R25.1, U7.27 (RESETB); also elsewhere on the board
ULPI_STP: U7.29 (STP); also elsewhere on the board
USB1_BUSDET: U8.16 (Vbusdet); also elsewhere on the board
USB1_CON: R27.1, U8.5 (CON); also elsewhere on the board
USB1_OE_N: R26.2, U8.9 (OE#); also elsewhere on the board
USB1_RCV: U8.2 (RCV); also elsewhere on the board
USB1_SUS: R29.2, U8.7 (SUS); also elsewhere on the board
USB1_VM: U8.4 (VM); also elsewhere on the board
USB1_VP: U8.3 (VP); also elsewhere on the board
USB2_D_N: U7.19 (DM); also elsewhere on the board
USB2_D_P: U7.18 (DP); also elsewhere on the board
VBUS_TRGT: C1.1, C14.1, R20.1, U7.21 (VBAT), U8.14 (Vbus); also elsewhere on the board
VIO_2V5: C11.1, C12.1, C15.1, C16.1, R14.1, R23.1, R26.1, R29.1, U6.5 (VCC), U6.10 (VDD), U7.32 (VDDIO), U8.1 (SPD), U8.8 (RSEL), U8.15 (Vif); also elsewhere on the board

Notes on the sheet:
Copyright (c) 2025 Anton Kuzmin <ak@gmm7550.dev> This documentation is distributed under the terms of the CERN-OHL-P v2 (https://cern.ch/cern-ohl). This project was funded through the NGI0 Common Fund, a fund established by NLnet foundation.

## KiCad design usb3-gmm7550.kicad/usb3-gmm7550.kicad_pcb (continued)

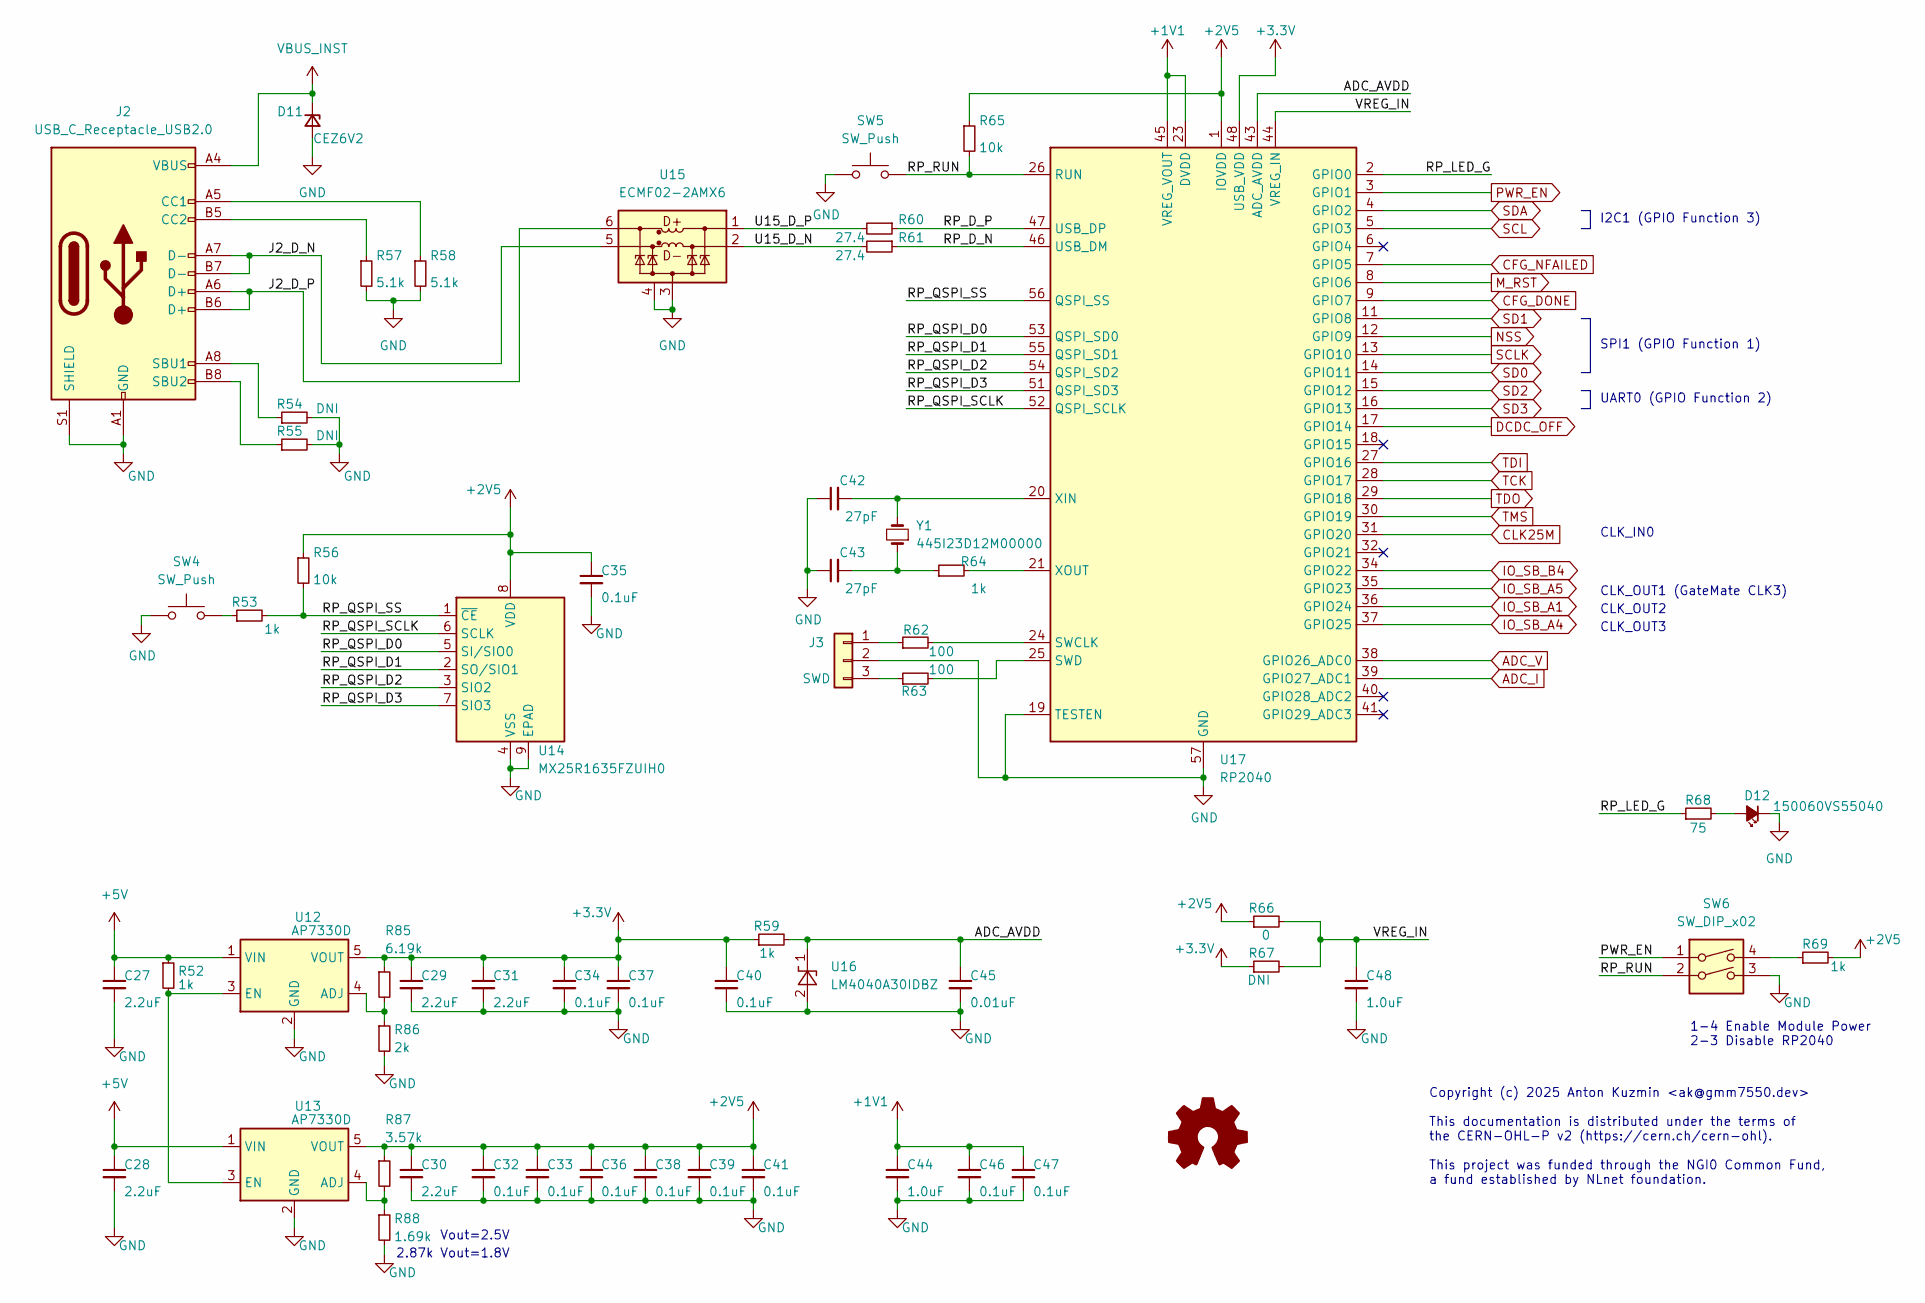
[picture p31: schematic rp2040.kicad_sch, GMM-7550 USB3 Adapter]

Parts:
C27, C28, C29, C30, C31: 2.2uF; C_0603_1608Metric
C32, C33, C34, C35, C36, C37, C38, C39, C40, C41, C46, C47: 0.1uF; C_0402_1005Metric
C42, C43: 27pF; C_0402_1005Metric
C44, C48: 1.0uF; C_0402_1005Metric
C45: 0.01uF; C_0402_1005Metric
D11: CEZ6V2; D_SOD-523
D12: 150060VS55040; LED_0603_1608Metric
J2: USB_C_Receptacle_USB2.0; USB_C_Receptacle_GCT_USB4105-xx-A_16P_TopMnt_Horizontal
J3: SWD; JST_SH_SM03B-SRSS-TB_1x03-1MP_P1.00mm_Horizontal
R52, R53, R59, R64, R69: 1k; R_0402_1005Metric
R54, R55, R67: DNI; R_0402_1005Metric
R56, R65: 10k; R_0402_1005Metric
R57, R58: 5.1k; R_0402_1005Metric
R60, R61: 27.4; R_0402_1005Metric
R62, R63: 100; R_0402_1005Metric
R66: 0; R_0402_1005Metric
R68: 75; R_0402_1005Metric
R85: 6.19k; R_0402_1005Metric
R86: 2k; R_0402_1005Metric
R87: 3.57k; R_0402_1005Metric
R88: 1.69k; R_0402_1005Metric
SW4, SW5: SW_Push; SW_SPST_PTS810
SW6: SW_DIP_x02; SW_DIP_SPSTx02_Slide_Omron_A6H-2101_W6.15mm_P1.27mm
U12, U13: AP7330D; SOT-23-5
U14: MX25R1635FZUIH0; Winbond_USON-8-1EP_3x2mm_P0.5mm_EP0.2x1.6mm
U15: ECMF02-2AMX6; ST_UQFN-6L_1.5x1.7mm_P0.5mm
U16: LM4040A30IDBZ; SOT-23
U17: RP2040; QFN-56-1EP_7x7mm_P0.4mm_EP3.2x3.2mm
Y1: 445I23D12M00000; Crystal_SMD_5032-2Pin_5.0x3.2mm

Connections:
+1V1: C44.1, C46.1, C47.1, U17.23 (DVDD), U17.45 (VREG_VOUT), U17.50 (DVDD)
+2V5: C30.1, C32.1, C33.1, C35.1, C36.1, C38.1, C39.1, C41.1, R56.1, R65.1, R66.1, R69.2, R87.1, U13.5 (VOUT), U14.8 (VDD), U17.1 (IOVDD), U17.10 (IOVDD), U17.22 (IOVDD), U17.33 (IOVDD), U17.42 (IOVDD), U17.49 (IOVDD)
+3.3V: C29.1, C31.1, C34.1, C37.1, C40.1, R59.1, R67.1, R85.1, U12.5 (VOUT), U17.48 (USB_VDD); also elsewhere on the board
+5V: C27.1, C28.1, R52.1, U12.1 (VIN), U13.1 (VIN); also elsewhere on the board
/RP2040/ADC_AVDD: C45.1, R59.2, U16.1 (K), U17.43 (ADC_AVDD)
/RP2040/J2_D_N: J2.A7 (D-), J2.B7 (D-), U15.5 (D-_out)
/RP2040/J2_D_P: J2.A6 (D+), J2.B6 (D+), U15.6 (D+_out)
/RP2040/RP_D_N: R61.1, U17.46 (USB_DM)
/RP2040/RP_D_P: R60.1, U17.47 (USB_DP)
/RP2040/RP_LED_G: R68.1, U17.2 (GPIO0)
/RP2040/RP_QSPI_D0: U14.5 (SI/SIO0), U17.53 (QSPI_SD0)
/RP2040/RP_QSPI_D1: U14.2 (SO/SIO1), U17.55 (QSPI_SD1)
/RP2040/RP_QSPI_D2: U14.3 (SIO2), U17.54 (QSPI_SD2)
/RP2040/RP_QSPI_D3: U14.7 (SIO3), U17.51 (QSPI_SD3)
/RP2040/RP_QSPI_SCLK: U14.6 (SCLK), U17.52 (QSPI_SCLK)
/RP2040/RP_QSPI_SS: R53.2, R56.2, U14.1 (~CE), U17.56 (QSPI_SS)
/RP2040/RP_RUN: R65.2, SW5.2, SW6.2, U17.26 (RUN)
/RP2040/U15_D_N: R61.2, U15.2 (D-_in)
/RP2040/U15_D_P: R60.2, U15.1 (D+_in)
/RP2040/VREG_IN: C48.1, R66.2, R67.2, U17.44 (VREG_IN)
ADC_I: U17.39 (GPIO27_ADC1); also elsewhere on the board
ADC_V: U17.38 (GPIO26_ADC0); also elsewhere on the board
CFG_DONE: U17.9 (GPIO7); also elsewhere on the board
CFG_NFAILED: U17.7 (GPIO5); also elsewhere on the board
CLK25M: U17.31 (GPIO20); also elsewhere on the board
DCDC_OFF: U17.17 (GPIO14); also elsewhere on the board
GND: C27.2, C28.2, C29.2, C30.2, C31.2, C32.2, C33.2, C34.2, C35.2, C36.2, C37.2, C38.2, C39.2, C40.2, C41.2, C42.1, C43.1, C44.2, C45.2, C46.2, C47.2, C48.2, D11.2 (A), D12.1 (K), J2.A1 (GND), J2.A12 (GND), J2.B1 (GND), J2.B12 (GND), J2.S1 (SHIELD), J3.2, R54.2, R55.2, R57.2, R58.2, R86.2, R88.2, SW4.1, SW5.1, SW6.3, U12.2 (GND), U13.2 (GND), U14.4 (VSS), U14.9 (EPAD), U15.3 (GND), U15.4 (NC), U16.2 (A), U17.19 (TESTEN), U17.57 (GND); also elsewhere on the board
IO_SB_A1: U17.36 (GPIO24); also elsewhere on the board
IO_SB_A4: U17.37 (GPIO25); also elsewhere on the board
IO_SB_A5: U17.35 (GPIO23); also elsewhere on the board
IO_SB_B4: U17.34 (GPIO22); also elsewhere on the board
M_RST: U17.8 (GPIO6); also elsewhere on the board
NSS: U17.12 (GPIO9); also elsewhere on the board
unnamed: C43.2, R64.1, Y1.1
unnamed: D12.2 (A), R68.2
unnamed: J2.A5 (CC1), R58.1
unnamed: J2.B5 (CC2), R57.1
unnamed: J2.A8 (SBU1), R54.1
unnamed: J2.B8 (SBU2), R55.1
unnamed: J3.1, R62.1
unnamed: J3.3, R63.1
unnamed: R53.1, SW4.2
unnamed: R69.1, SW6.4
unnamed: R85.2, R86.1, U12.4 (ADJ)
unnamed: R52.2, U12.3 (EN), U13.3 (EN)
unnamed: R87.2, R88.1, U13.4 (ADJ)
unnamed: R62.2, U17.24 (SWCLK)
unnamed: R63.2, U17.25 (SWD)
unnamed: C42.2, U17.20 (XIN), Y1.2
unnamed: R64.2, U17.21 (XOUT)
PWR_EN: SW6.1, U17.3 (GPIO1); also elsewhere on the board
SCL: U17.5 (GPIO3); also elsewhere on the board
SCLK: U17.13 (GPIO10); also elsewhere on the board
SD0: U17.14 (GPIO11); also elsewhere on the board
SD1: U17.11 (GPIO8); also elsewhere on the board
SD2: U17.15 (GPIO12); also elsewhere on the board
SD3: U17.16 (GPIO13); also elsewhere on the board
SDA: U17.4 (GPIO2); also elsewhere on the board
TCK: U17.28 (GPIO17); also elsewhere on the board
TDI: U17.27 (GPIO16); also elsewhere on the board
TDO: U17.29 (GPIO18); also elsewhere on the board
TMS: U17.30 (GPIO19); also elsewhere on the board
VBUS_INST: D11.1 (K), J2.A4 (VBUS), J2.A9 (VBUS), J2.B4 (VBUS), J2.B9 (VBUS); also elsewhere on the board

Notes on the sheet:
CLK_IN0
CLK_OUT1 (GateMate CLK3)
I2C1 (GPIO Function 3)
Vout=2.5V
2.87k Vout=1.8V
Copyright (c) 2025 Anton Kuzmin <ak@gmm7550.dev> This documentation is distributed under the terms of the CERN-OHL-P v2 (https://cern.ch/cern-ohl). This project was funded through the NGI0 Common Fund, a fund established by NLnet foundation.
CLK_OUT3
UART0 (GPIO Function 2)
1-4 Enable Module Power 2-3 Disable RP2040
CLK_OUT2
SPI1 (GPIO Function 1)

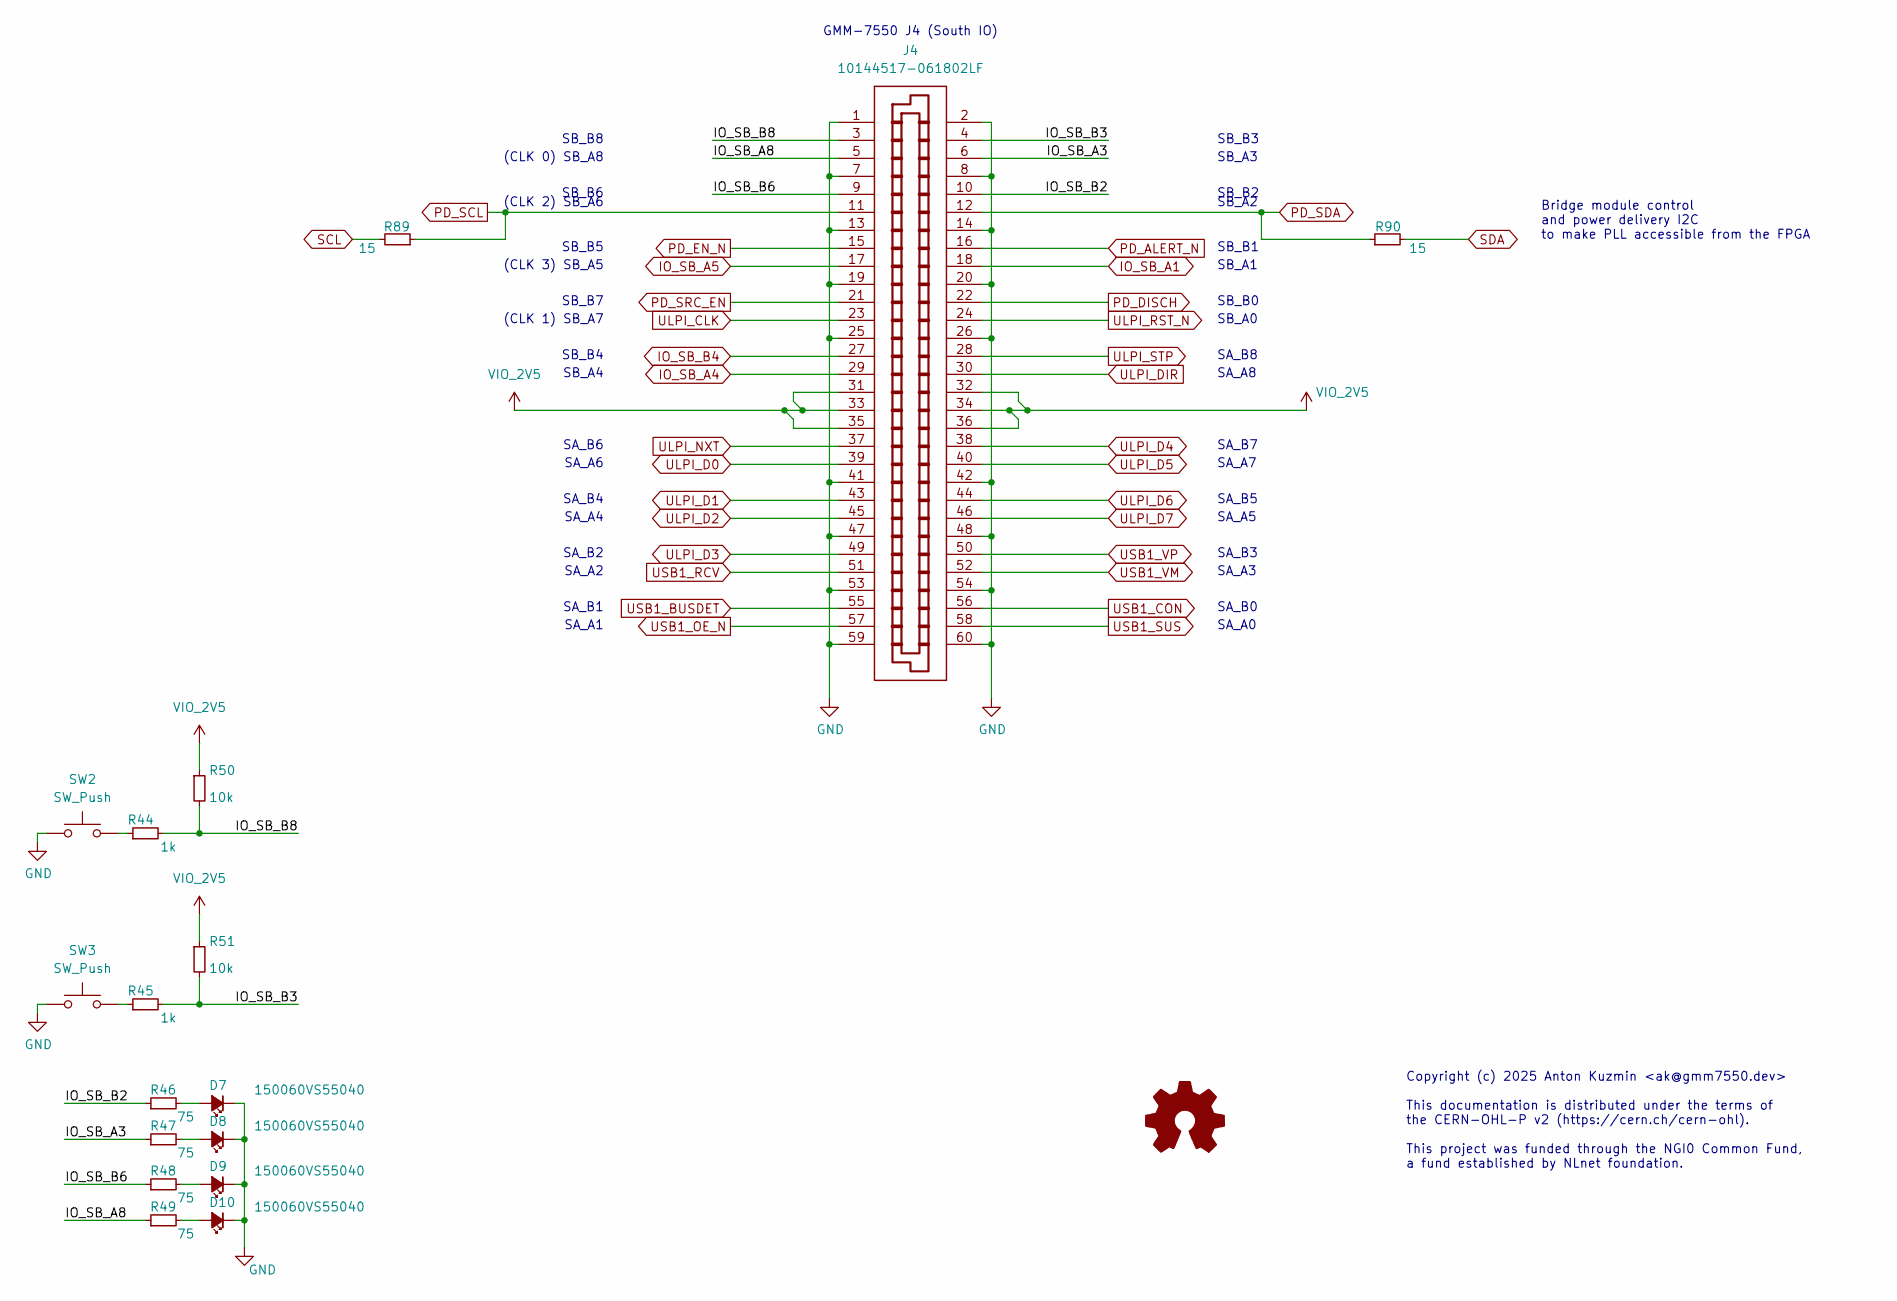
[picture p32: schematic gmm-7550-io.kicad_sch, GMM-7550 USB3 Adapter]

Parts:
D7, D8, D9, D10: 150060VS55040; LED_0603_1608Metric
J4: 10144517-061802LF
R44, R45: 1k; R_0402_1005Metric
R46, R47, R48, R49: 75; R_0402_1005Metric
R50, R51: 10k; R_0402_1005Metric
R89, R90: 15; R_0402_1005Metric
SW2, SW3: SW_Push; SW_SPST_PTS810

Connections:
/GMM-7550 IO/IO_SB_A3: J4.6, R47.1
/GMM-7550 IO/IO_SB_A8: J4.5, R49.1
/GMM-7550 IO/IO_SB_B2: J4.10, R46.1
/GMM-7550 IO/IO_SB_B3: J4.4, R45.2, R51.2
/GMM-7550 IO/IO_SB_B6: J4.9, R48.1
/GMM-7550 IO/IO_SB_B8: J4.3, R44.2, R50.2
GND: D7.1 (K), D8.1 (K), D9.1 (K), D10.1 (K), J4.1, J4.2, J4.7, J4.8, J4.13, J4.14, J4.19, J4.20, J4.25, J4.26, J4.41, J4.42, J4.47, J4.48, J4.53, J4.54, J4.59, J4.60, SW2.1, SW3.1; also elsewhere on the board
IO_SB_A1: J4.18; also elsewhere on the board
IO_SB_A4: J4.29; also elsewhere on the board
IO_SB_A5: J4.17; also elsewhere on the board
IO_SB_B4: J4.27; also elsewhere on the board
unnamed: D7.2 (A), R46.2
unnamed: D8.2 (A), R47.2
unnamed: D9.2 (A), R48.2
unnamed: D10.2 (A), R49.2
unnamed: R44.1, SW2.2
unnamed: R45.1, SW3.2
PD_ALERT_N: J4.16; also elsewhere on the board
PD_DISCH: J4.22; also elsewhere on the board
PD_EN_N: J4.15; also elsewhere on the board
PD_SCL: J4.11, R89.1; also elsewhere on the board
PD_SDA: J4.12, R90.1; also elsewhere on the board
PD_SRC_EN: J4.21; also elsewhere on the board
SCL: R89.2; also elsewhere on the board
SDA: R90.2; also elsewhere on the board
ULPI_CLK: J4.23; also elsewhere on the board
ULPI_D0: J4.39; also elsewhere on the board
ULPI_D1: J4.43; also elsewhere on the board
ULPI_D2: J4.45; also elsewhere on the board
ULPI_D3: J4.49; also elsewhere on the board
ULPI_D4: J4.38; also elsewhere on the board
ULPI_D5: J4.40; also elsewhere on the board
ULPI_D6: J4.44; also elsewhere on the board
ULPI_D7: J4.46; also elsewhere on the board
ULPI_DIR: J4.30; also elsewhere on the board
ULPI_NXT: J4.37; also elsewhere on the board
ULPI_RST_N: J4.24; also elsewhere on the board
ULPI_STP: J4.28; also elsewhere on the board
USB1_BUSDET: J4.55; also elsewhere on the board
USB1_CON: J4.56; also elsewhere on the board
USB1_OE_N: J4.57; also elsewhere on the board
USB1_RCV: J4.51; also elsewhere on the board
USB1_SUS: J4.58; also elsewhere on the board
USB1_VM: J4.52; also elsewhere on the board
USB1_VP: J4.50; also elsewhere on the board
VIO_2V5: J4.31, J4.32, J4.33, J4.34, J4.35, J4.36, R50.1, R51.1; also elsewhere on the board

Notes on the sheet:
SB_B7
SA_A0
SA_B8
(CLK 2) SB_A6
SA_B1
SA_A8
SA_A6
SA_A2
SB_B5
(CLK 0) SB_A8
SB_A0
GMM-7550 J4 (South IO)
SA_A7
SB_B0
SB_B3
SB_B4
SA_B7
SB_B2
(CLK 1) SB_A7
SA_A5
SB_B1
SB_A1
SA_B3
SB_A2
SB_B8
SA_B6
Bridge module control and power delivery I2C to make PLL accessible from the FPGA
SA_B5
SB_A3
(CLK 3) SB_A5
Copyright (c) 2025 Anton Kuzmin <ak@gmm7550.dev> This documentation is distributed under the terms of the CERN-OHL-P v2 (https://cern.ch/cern-ohl). This project was funded through the NGI0 Common Fund, a fund established by NLnet foundation.
SA_A3
SB_B6
SA_B2
SA_A1
SA_B4
SB_A4
SA_B0
SA_A4

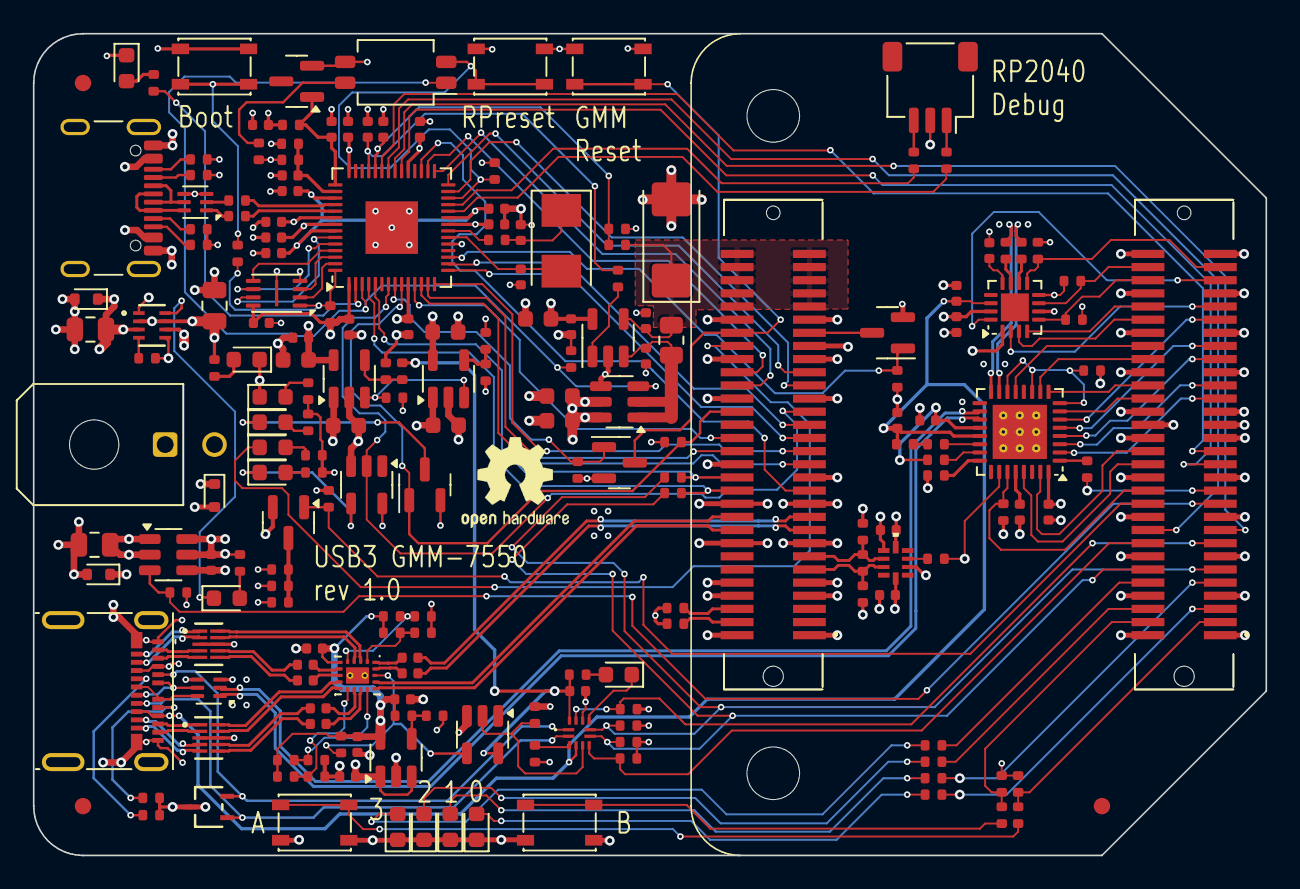
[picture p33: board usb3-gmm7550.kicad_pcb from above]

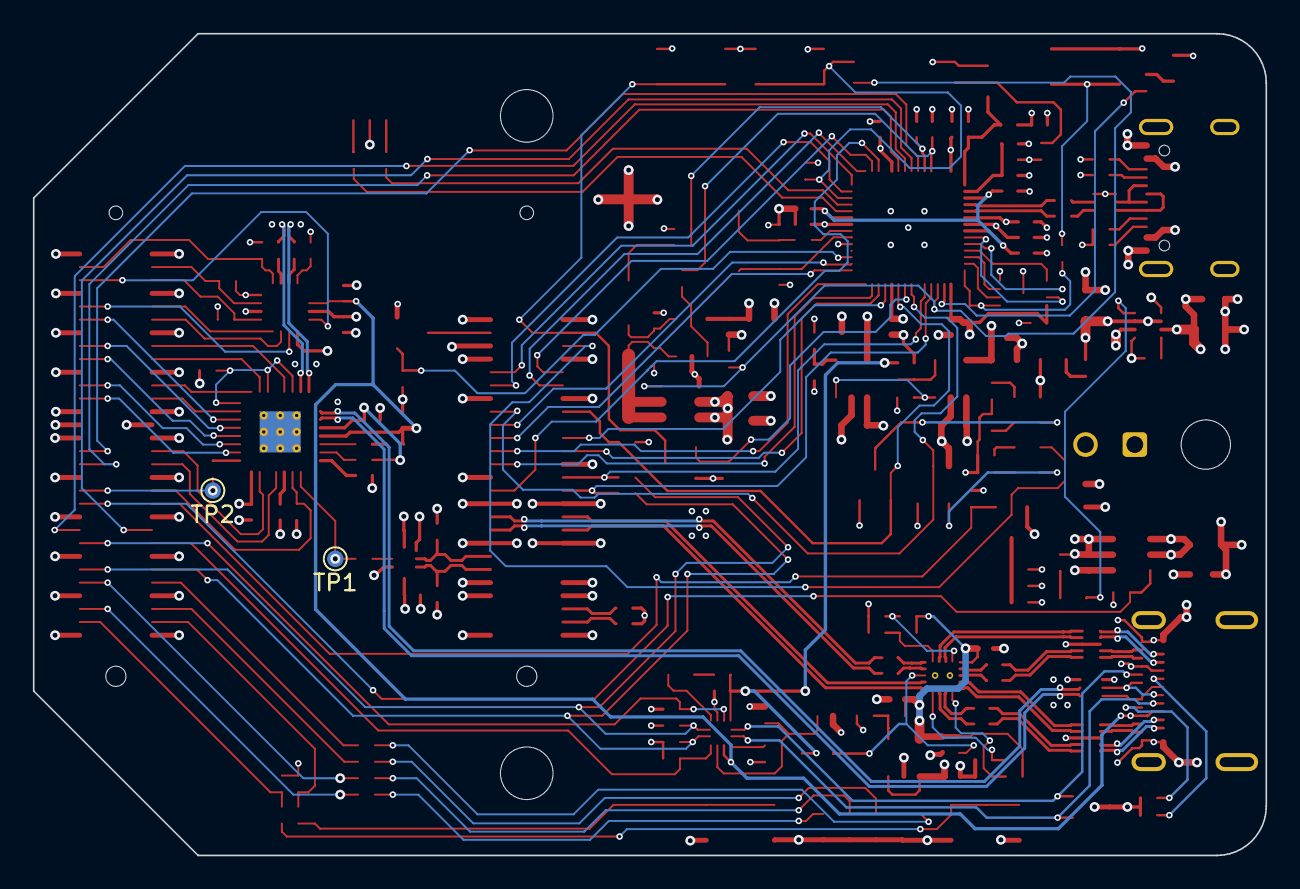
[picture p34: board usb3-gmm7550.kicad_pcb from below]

Board: 4 copper layers, 75.0 x 50.0 mm, 205 parts (2 on the bottom side), 184 nets.

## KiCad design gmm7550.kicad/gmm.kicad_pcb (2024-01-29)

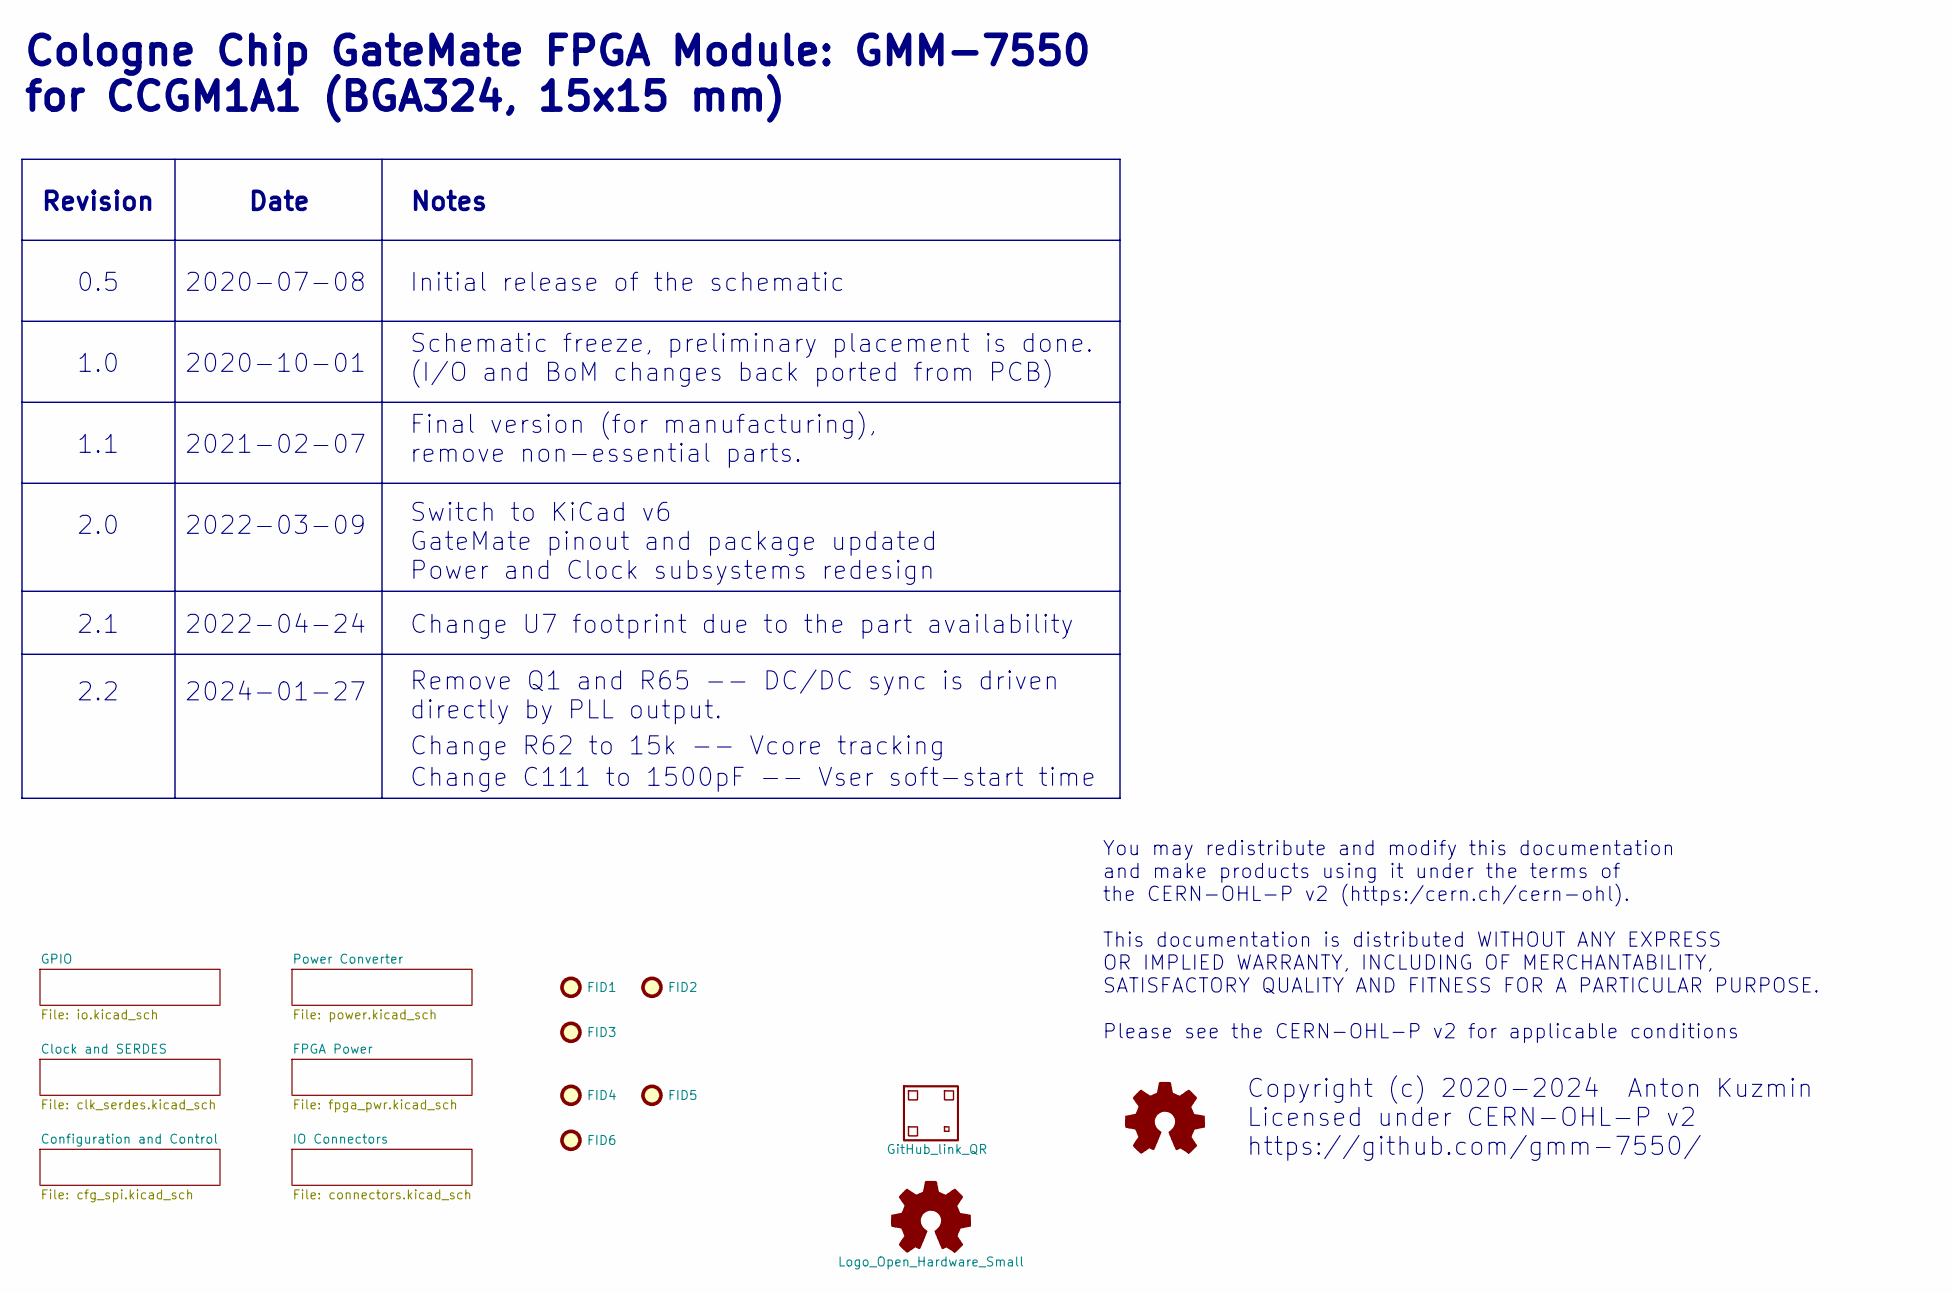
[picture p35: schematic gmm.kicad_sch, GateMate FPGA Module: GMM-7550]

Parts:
FID1, FID2, FID3, FID4, FID5, FID6: Fiducial; Fiducial_0.75mm_Mask1.5mm
LOGO1: Logo_Open_Hardware_Small; OSHW-Logo2_7.3x6mm_SilkScreen
QR1: GitHub_link_QR; gmm7550_dev_link_QR

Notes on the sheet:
Revision
Initial release of the schematic
1.1
0.5
Change C111 to 1500pF -- Vser soft-start time
2020-07-08
Final version (for manufacturing), remove non-essential parts.
2022-04-24
Notes
You may redistribute and modify this documentation and make products using it under the terms of the CERN-OHL-P v2 (https:/cern.ch/cern-ohl). This documentation is distributed WITHOUT ANY EXPRESS OR IMPLIED WARRANTY, INCLUDING OF MERCHANTABILITY, SATISFACTORY QUALITY AND FITNESS FOR A PARTICULAR PU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
2020-10-01
2021-02-07
Change R62 to 15k -- Vcore tracking
Copyright (c) 2020-2024 Anton Kuzmin Licensed under CERN-OHL-P v2 https://github.com/gmm-7550/
Switch to KiCad v6 GateMate pinout and package updated Power and Clock subsystems redesign
2.2
Change U7 footprint due to the part availability
Cologne Chip GateMate FPGA Module: GMM-7550 for CCGM1A1 (BGA324, 15x15 mm)
2.1
2.0
2022-03-09
1.0
Remove Q1 and R65 -- DC/DC sync is driven directly by PLL output.
Schematic freeze, preliminary placement is done. (I/O and BoM changes back ported from PCB)
2024-01-27
Date

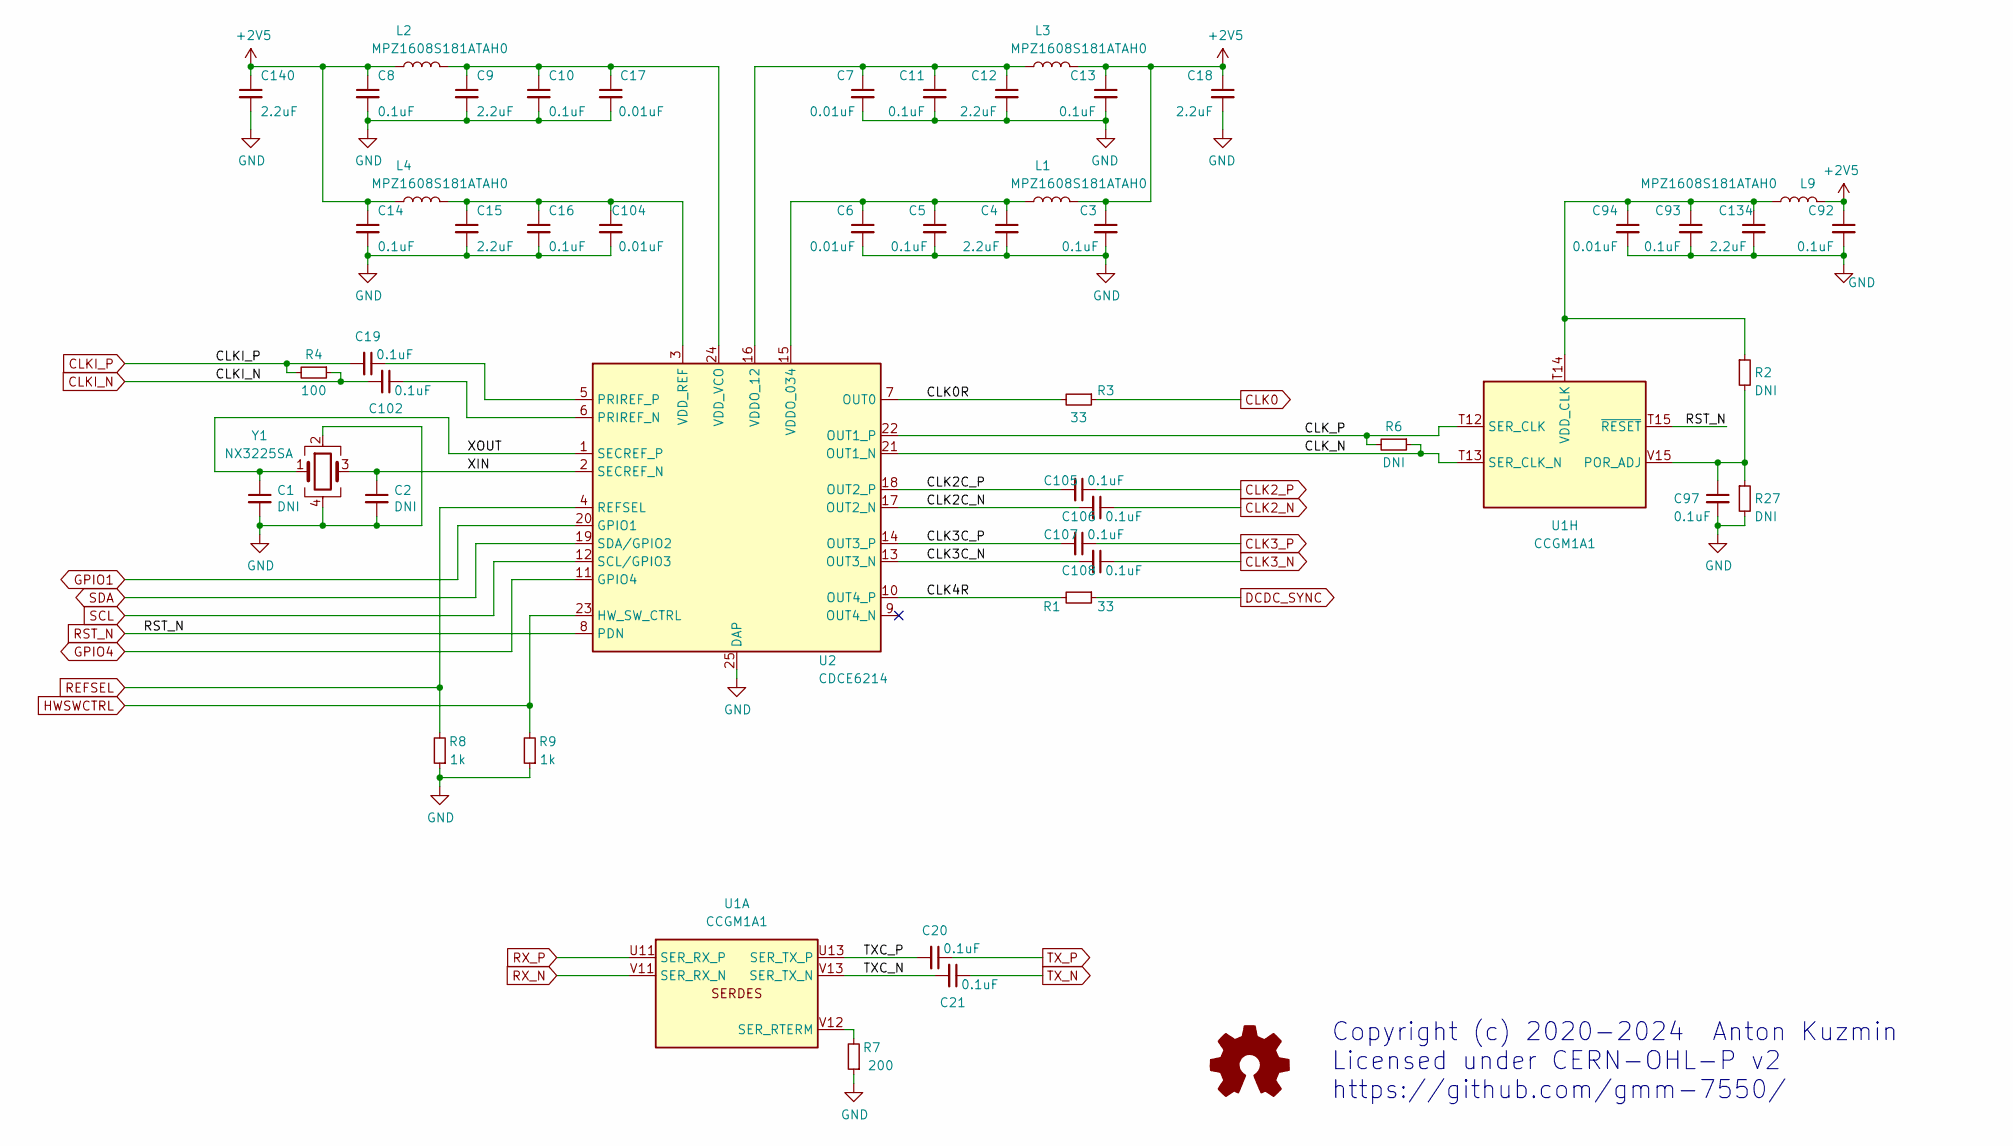
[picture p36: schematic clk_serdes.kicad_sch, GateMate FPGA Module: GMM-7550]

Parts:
C1, C2: DNI; C_0402_1005Metric
C3, C5, C8, C10, C11, C13, C14, C16, C19, C20, C21, C92, C93, C97, C102, C105, C106, C107, C108: 0.1uF; C_0402_1005Metric
C4, C9, C12, C15, C18, C134, C140: 2.2uF; C_0603_1608Metric
C6, C7, C17, C94, C104: 0.01uF; C_0402_1005Metric
L1, L2, L3, L4, L9: MPZ1608S181ATAH0; L_0603_1608Metric
R1, R3: 33; R_0402_1005Metric
R2, R6, R27: DNI; R_0402_1005Metric
R4: 100; R_0402_1005Metric
R7: 200; R_0402_1005Metric
R8, R9: 1k; R_0402_1005Metric
U1: CCGM1A1; BGA-324_15.0x15.0mm_Layout18x18_P0.8mm_Ball0.45mm_Pad0.35mm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
U2: CDCE6214; Texas_RGE0024H_EP2.7x2.7mm_ThermalVias
Y1: NX3225SA; Crystal_SMD_3225-4Pin_3.2x2.5mm

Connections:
+2V5: C3.1, C8.1, C13.1, C14.1, C18.1, C92.1, C140.1, L1.2, L2.1, L3.1, L4.1, L9.2; also elsewhere on the board
/Clock and SERDES/CLK0R: R3.2, U2.7 (OUT0)
/Clock and SERDES/CLK2C_N: C107.2, U2.17 (OUT2_N)
/Clock and SERDES/CLK2C_P: C105.2, U2.18 (OUT2_P)
/Clock and SERDES/CLK3C_N: C108.2, U2.13 (OUT3_N)
/Clock and SERDES/CLK3C_P: C106.2, U2.14 (OUT3_P)
/Clock and SERDES/CLK4R: R1.2, U2.10 (OUT4_P)
/Clock and SERDES/CLK_N: R6.1, U1.T13 (SER_CLK_N), U2.21 (OUT1_N)
/Clock and SERDES/CLK_P: R6.2, U1.T12 (SER_CLK), U2.22 (OUT1_P)
/Clock and SERDES/TXC_N: C21.2, U1.V13 (SER_TX_N)
/Clock and SERDES/TXC_P: C20.2, U1.U13 (SER_TX_P)
/Clock and SERDES/XIN: C2.1, U2.2 (SECREF_N), Y1.3
/Clock and SERDES/XOUT: C1.1, U2.1 (SECREF_P), Y1.1
CLK0: R3.1; also elsewhere on the board
CLK2_N: C107.1; also elsewhere on the board
CLK2_P: C105.1; also elsewhere on the board
CLK3_N: C108.1; also elsewhere on the board
CLK3_P: C106.1; also elsewhere on the board
CLKI_N: C102.2, R4.1; also elsewhere on the board
CLKI_P: C19.2, R4.2; also elsewhere on the board
DCDC_SYNC: R1.1; also elsewhere on the board
GND: C1.2, C2.2, C3.2, C4.2, C5.2, C6.2, C7.2, C8.2, C9.2, C10.2, C11.2, C12.2, C13.2, C14.2, C15.2, C16.2, C17.2, C18.2, C92.2, C93.2, C94.2, C97.2, C104.2, C134.2, C140.2, R7.1, R8.1, R9.1, R27.2, U2.25 (DAP), Y1.2, Y1.4; also elsewhere on the board
GPIO1: U2.20 (GPIO1); also elsewhere on the board
GPIO4: U2.11 (GPIO4); also elsewhere on the board
HWSWCTRL: R9.2, U2.23 (HW_SW_CTRL); also elsewhere on the board
unnamed: R7.2, U1.V12 (SER_RTERM)
unnamed: C97.1, R2.2, R27.1, U1.V15 (POR_ADJ)
unnamed: C93.1, C94.1, C134.1, L9.1, R2.1, U1.T14 (VDD_CLK)
unnamed: C102.1, U2.6 (PRIREF_N)
unnamed: C19.1, U2.5 (PRIREF_P)
unnamed: C7.1, C11.1, C12.1, L3.2, U2.16 (VDDO_12)
unnamed: C4.1, C5.1, C6.1, L1.1, U2.15 (VDDO_034)
unnamed: C15.1, C16.1, C104.1, L4.2, U2.3 (VDD_REF)
unnamed: C9.1, C10.1, C17.1, L2.2, U2.24 (VDD_VCO)
REFSEL: R8.2, U2.4 (REFSEL); also elsewhere on the board
RST_N: U1.T15 (~RESET), U2.8 (PDN); also elsewhere on the board
RX_N: U1.V11 (SER_RX_N); also elsewhere on the board
RX_P: U1.U11 (SER_RX_P); also elsewhere on the board
SCL: U2.12 (SCL/GPIO3); also elsewhere on the board
SDA: U2.19 (SDA/GPIO2); also elsewhere on the board
TX_N: C21.1; also elsewhere on the board
TX_P: C20.1; also elsewhere on the board

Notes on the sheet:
Copyright (c) 2020-2024 Anton Kuzmin Licensed under CERN-OHL-P v2 https://github.com/gmm-7550/

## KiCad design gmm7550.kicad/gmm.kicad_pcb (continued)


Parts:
C22, C31, C32, C41, C42, C51, C52, C61: 2.2uF; C_0603_1608Metric
C23, C30, C33, C40, C43, C50, C53, C60: 0.47uF; C_0603_1608Metric
C24, C25, C26, C27, C28, C29, C34, C35, C36, C37, C38, C39, C44, C45, C46, C47, C48, C49, C54, C55, C56, C57, C58, C59: 0.1uF; C_0402_1005Metric
R10, R11, R12, R13, R14, R15, R16, R17: DNI; R_0603_1608Metric
U1: CCGM1A1; BGA-324_15.0x15.0mm_Layout18x18_P0.8mm_Ball0.45mm_Pad0.35mm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

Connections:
+2V5: R10.1, R11.1, R12.1, R13.1, R14.1, R15.1, R16.1, R17.1; also elsewhere on the board
GND: C22.2, C23.2, C24.2, C25.2, C26.2, C27.2, C28.2, C29.2, C30.2, C31.2, C32.2, C33.2, C34.2, C35.2, C36.2, C37.2, C38.2, C39.2, C40.2, C41.2, C42.2, C43.2, C44.2, C45.2, C46.2, C47.2, C48.2, C49.2, C50.2, C51.2, C52.2, C53.2, C54.2, C55.2, C56.2, C57.2, C58.2, C59.2, C60.2, C61.2; also elsewhere on the board
IO_EA_A0: U1.M15 (IO_EA_A0); also elsewhere on the board
IO_EA_A1: U1.L16 (IO_EA_A1); also elsewhere on the board
IO_EA_A2: U1.K18 (IO_EA_A2); also elsewhere on the board
IO_EA_A3: U1.K16 (IO_EA_A3); also elsewhere on the board
IO_EA_A4: U1.J18 (IO_EA_A4); also elsewhere on the board
IO_EA_A5: U1.J16 (IO_EA_A5); also elsewhere on the board
IO_EA_A6: U1.H16 (IO_EA_A6); also elsewhere on the board
IO_EA_A7: U1.G18 (IO_EA_A7); also elsewhere on the board
IO_EA_A8: U1.G16 (IO_EA_A8); also elsewhere on the board
IO_EA_B0: U1.M14 (IO_EA_B0); also elsewhere on the board
IO_EA_B1: U1.L15 (IO_EA_B1); also elsewhere on the board
IO_EA_B2: U1.K17 (IO_EA_B2); also elsewhere on the board
IO_EA_B3: U1.K15 (IO_EA_B3); also elsewhere on the board
IO_EA_B4: U1.J17 (IO_EA_B4); also elsewhere on the board
IO_EA_B5: U1.J15 (IO_EA_B5); also elsewhere on the board
IO_EA_B6: U1.H15 (IO_EA_B6); also elsewhere on the board
IO_EA_B7: U1.G17 (IO_EA_B7); also elsewhere on the board
IO_EA_B8: U1.G15 (IO_EA_B8); also elsewhere on the board
IO_EB_A0: U1.F18 (IO_EB_A0); also elsewhere on the board
IO_EB_A1: U1.F16 (IO_EB_A1); also elsewhere on the board
IO_EB_A2: U1.D18 (IO_EB_A2); also elsewhere on the board
IO_EB_A3: U1.E16 (IO_EB_A3); also elsewhere on the board
IO_EB_A4: U1.C18 (IO_EB_A4); also elsewhere on the board
IO_EB_A5: U1.B17 (IO_EB_A5); also elsewhere on the board
IO_EB_A6: U1.D16 (IO_EB_A6); also elsewhere on the board
IO_EB_A7: U1.D15 (IO_EB_A7); also elsewhere on the board
IO_EB_A8: U1.B15 (IO_EB_A8); also elsewhere on the board
IO_EB_B0: U1.F17 (IO_EB_B0); also elsewhere on the board
IO_EB_B1: U1.F15 (IO_EB_B1); also elsewhere on the board
IO_EB_B2: U1.D17 (IO_EB_B2); also elsewhere on the board
IO_EB_B3: U1.E15 (IO_EB_B3); also elsewhere on the board
IO_EB_B4: U1.C17 (IO_EB_B4); also elsewhere on the board
IO_EB_B5: U1.A17 (IO_EB_B5); also elsewhere on the board
IO_EB_B6: U1.C16 (IO_EB_B6); also elsewhere on the board
IO_EB_B7: U1.C15 (IO_EB_B7); also elsewhere on the board
IO_EB_B8: U1.A15 (IO_EB_B8); also elsewhere on the board
IO_NA_A0: U1.A3 (IO_NA_A0); also elsewhere on the board
IO_NA_A1: U1.A4 (IO_NA_A1); also elsewhere on the board
IO_NA_A2: U1.B5 (IO_NA_A2); also elsewhere on the board
IO_NA_A3: U1.C6 (IO_NA_A3); also elsewhere on the board
IO_NA_A4: U1.A6 (IO_NA_A4); also elsewhere on the board
IO_NA_A5: U1.C7 (IO_NA_A5); also elsewhere on the board
IO_NA_A6: U1.C8 (IO_NA_A6); also elsewhere on the board
IO_NA_A7: U1.A8 (IO_NA_A7); also elsewhere on the board
IO_NA_A8: U1.C9 (IO_NA_A8); also elsewhere on the board
IO_NA_B0: U1.B3 (IO_NA_B0); also elsewhere on the board
IO_NA_B1: U1.B4 (IO_NA_B1); also elsewhere on the board
IO_NA_B2: U1.C5 (IO_NA_B2); also elsewhere on the board
IO_NA_B3: U1.D6 (IO_NA_B3); also elsewhere on the board
IO_NA_B4: U1.B6 (IO_NA_B4); also elsewhere on the board
IO_NA_B5: U1.D7 (IO_NA_B5); also elsewhere on the board
IO_NA_B6: U1.D8 (IO_NA_B6); also elsewhere on the board
IO_NA_B7: U1.B8 (IO_NA_B7); also elsewhere on the board
IO_NA_B8: U1.D9 (IO_NA_B8); also elsewhere on the board
IO_NB_A0: U1.B9 (IO_NB_A0); also elsewhere on the board
IO_NB_A1: U1.D10 (IO_NB_A1); also elsewhere on the board
IO_NB_A2: U1.B11 (IO_NB_A2); also elsewhere on the board
IO_NB_A3: U1.D11 (IO_NB_A3); also elsewhere on the board
IO_NB_A4: U1.B12 (IO_NB_A4); also elsewhere on the board
IO_NB_A5: U1.D12 (IO_NB_A5); also elsewhere on the board
IO_NB_A6: U1.D13 (IO_NB_A6); also elsewhere on the board
IO_NB_A7: U1.B14 (IO_NB_A7); also elsewhere on the board
IO_NB_A8: U1.D14 (IO_NB_A8); also elsewhere on the board
IO_NB_B0: U1.A9 (IO_NB_B0); also elsewhere on the board
IO_NB_B1: U1.C10 (IO_NB_B1); also elsewhere on the board
IO_NB_B2: U1.A11 (IO_NB_B2); also elsewhere on the board
IO_NB_B3: U1.C11 (IO_NB_B3); also elsewhere on the board
IO_NB_B4: U1.A12 (IO_NB_B4); also elsewhere on the board
IO_NB_B5: U1.C12 (IO_NB_B5); also elsewhere on the board
IO_NB_B6: U1.C13 (IO_NB_B6); also elsewhere on the board
IO_NB_B7: U1.A14 (IO_NB_B7); also elsewhere on the board
IO_NB_B8: U1.C14 (IO_NB_B8); also elsewhere on the board
IO_SA_A0: U1.U5 (IO_SA_A0); also elsewhere on the board
IO_SA_A1: U1.R6 (IO_SA_A1); also elsewhere on the board
IO_SA_A2: U1.R7 (IO_SA_A2); also elsewhere on the board
IO_SA_A3: U1.U7 (IO_SA_A3); also elsewhere on the board
IO_SA_A4: U1.R8 (IO_SA_A4); also elsewhere on the board
IO_SA_A5: U1.U8 (IO_SA_A5); also elsewhere on the board
IO_SA_A6: U1.R9 (IO_SA_A6); also elsewhere on the board
IO_SA_A7: U1.R10 (IO_SA_A7); also elsewhere on the board
IO_SA_A8: U1.U10 (IO_SA_A8); also elsewhere on the board
IO_SA_B0: U1.V5 (IO_SA_B0); also elsewhere on the board
IO_SA_B1: U1.T6 (IO_SA_B1); also elsewhere on the board
IO_SA_B2: U1.T7 (IO_SA_B2); also elsewhere on the board
IO_SA_B3: U1.V7 (IO_SA_B3); also elsewhere on the board
IO_SA_B4: U1.T8 (IO_SA_B4); also elsewhere on the board
IO_SA_B5: U1.V8 (IO_SA_B5); also elsewhere on the board
IO_SA_B6: U1.T9 (IO_SA_B6); also elsewhere on the board
IO_SA_B7: U1.T10 (IO_SA_B7); also elsewhere on the board
IO_SA_B8: U1.V10 (IO_SA_B8); also elsewhere on the board
IO_SB_A0: U1.U17 (IO_SB_A0); also elsewhere on the board
IO_SB_A1: U1.R17 (IO_SB_A1); also elsewhere on the board
IO_SB_A2: U1.P17 (IO_SB_A2); also elsewhere on the board
IO_SB_A3: U1.M17 (IO_SB_A3); also elsewhere on the board
IO_SB_A4: U1.P11 (IO_SB_A4); also elsewhere on the board
IO_SB_A5: U1.R13 (CLK4/IO_SB_A5); also elsewhere on the board
IO_SB_A6: U1.P14 (CLK3/IO_SB_A6); also elsewhere on the board
IO_SB_A7: U1.P12 (CLK2/IO_SB_A7); also elsewhere on the board
IO_SB_A8: U1.N14 (CLK1/IO_SB_A8); also elsewhere on the board
IO_SB_B0: U1.U18 (IO_SB_B0); also elsewhere on the board
IO_SB_B1: U1.R18 (IO_SB_B1); also elsewhere on the board
IO_SB_B2: U1.P18 (IO_SB_B2); also elsewhere on the board
IO_SB_B3: U1.M18 (IO_SB_B3); also elsewhere on the board
IO_SB_B4: U1.R11 (IO_SB_B4); also elsewhere on the board
IO_SB_B5: U1.R14 (IO_SB_B5); also elsewhere on the board
IO_SB_B6: U1.P15 (IO_SB_B6); also elsewhere on the board
IO_SB_B7: U1.P13 (IO_SB_B7); also elsewhere on the board
IO_SB_B8: U1.N15 (IO_SB_B8); also elsewhere on the board
IO_WB_A0: U1.N1 (IO_WB_A0); also elsewhere on the board
IO_WB_A1: U1.M3 (IO_WB_A1); also elsewhere on the board
IO_WB_A2: U1.L3 (IO_WB_A2); also elsewhere on the board
IO_WB_A3: U1.L1 (IO_WB_A3); also elsewhere on the board
IO_WB_A4: U1.K3 (IO_WB_A4); also elsewhere on the board
IO_WB_A5: U1.K1 (IO_WB_A5); also elsewhere on the board
IO_WB_A6: U1.J3 (IO_WB_A6); also elsewhere on the board
IO_WB_A7: U1.H1 (IO_WB_A7); also elsewhere on the board
IO_WB_A8: U1.H3 (IO_WB_A8); also elsewhere on the board
IO_WB_B0: U1.N2 (IO_WB_B0); also elsewhere on the board
IO_WB_B1: U1.M4 (IO_WB_B1); also elsewhere on the board
IO_WB_B2: U1.L4 (IO_WB_B2); also elsewhere on the board
IO_WB_B3: U1.L2 (IO_WB_B3); also elsewhere on the board
IO_WB_B4: U1.K4 (IO_WB_B4); also elsewhere on the board
IO_WB_B5: U1.K2 (IO_WB_B5); also elsewhere on the board
IO_WB_B6: U1.J4 (IO_WB_B6); also elsewhere on the board
IO_WB_B7: U1.H2 (IO_WB_B7); also elsewhere on the board
IO_WB_B8: U1.H4 (IO_WB_B8); also elsewhere on the board
IO_WC_A0: U1.G1 (IO_WC_A0); also elsewhere on the board
IO_WC_A1: U1.G3 (IO_WC_A1); also elsewhere on the board
IO_WC_A2: U1.F3 (IO_WC_A2); also elsewhere on the board
IO_WC_A3: U1.E1 (IO_WC_A3); also elsewhere on the board
IO_WC_A4: U1.E3 (IO_WC_A4); also elsewhere on the board
IO_WC_A5: U1.D1 (IO_WC_A5); also elsewhere on the board
IO_WC_A6: U1.D3 (IO_WC_A6); also elsewhere on the board
IO_WC_A7: U1.C3 (IO_WC_A7); also elsewhere on the board
IO_WC_A8: U1.B1 (IO_WC_A8); also elsewhere on the board
IO_WC_B0: U1.G2 (IO_WC_B0); also elsewhere on the board
IO_WC_B1: U1.G4 (IO_WC_B1); also elsewhere on the board
IO_WC_B2: U1.F4 (IO_WC_B2); also elsewhere on the board
IO_WC_B3: U1.E2 (IO_WC_B3); also elsewhere on the board
IO_WC_B4: U1.E4 (IO_WC_B4); also elsewhere on the board
IO_WC_B5: U1.D2 (IO_WC_B5); also elsewhere on the board
IO_WC_B6: U1.D4 (IO_WC_B6); also elsewhere on the board
IO_WC_B7: U1.C4 (IO_WC_B7); also elsewhere on the board
IO_WC_B8: U1.B2 (IO_WC_B8); also elsewhere on the board
VIO_EA: C42.1, C43.1, C44.1, C45.1, C46.1, R14.2, U1.G14 (VDD_EA), U1.H17 (VDD_EA), U1.J14 (VDD_EA), U1.L14 (VDD_EA), U1.L17 (VDD_EA); also elsewhere on the board
VIO_EB: C47.1, C48.1, C49.1, C50.1, C51.1, R15.2, U1.A16 (VDD_EB), U1.B18 (VDD_EB), U1.E14 (VDD_EB), U1.E17 (VDD_EB), U1.F13 (VDD_EB); also elsewhere on the board
VIO_NA: C32.1, C33.1, C34.1, C35.1, C36.1, R12.2, U1.A5 (VDD_NA), U1.B7 (VDD_NA), U1.E6 (VDD_NA), U1.E8 (VDD_NA), U1.F7 (VDD_NA); also elsewhere on the board
VIO_NB: C37.1, C38.1, C39.1, C40.1, C41.1, R13.2, U1.B10 (VDD_NB), U1.B13 (VDD_NB), U1.E10 (VDD_NB), U1.E12 (VDD_NB), U1.F11 (VDD_NB); also elsewhere on the board
VIO_SA: C52.1, C53.1, C54.1, C55.1, C56.1, R16.2, U1.P6 (VDD_SA), U1.P8 (VDD_SA), U1.P10 (VDD_SA), U1.U6 (VDD_SA), U1.U9 (VDD_SA); also elsewhere on the board
VIO_SB: C57.1, C58.1, C59.1, C60.1, C61.1, R17.2, U1.N11 (VDD_SB), U1.N13 (VDD_SB), U1.N18 (VDD_SB), U1.R15 (VDD_SB), U1.T18 (VDD_SB); also elsewhere on the board
VIO_WB: C22.1, C23.1, C24.1, C25.1, C26.1, R10.2, U1.H5 (VDD_WB), U1.J2 (VDD_WB), U1.K5 (VDD_WB), U1.M2 (VDD_WB), U1.M5 (VDD_WB); also elsewhere on the board
VIO_WC: C27.1, C28.1, C29.1, C30.1, C31.1, R11.2, U1.A2 (VDD_WC), U1.C2 (VDD_WC), U1.D5 (VDD_WC), U1.F2 (VDD_WC), U1.F5 (VDD_WC); also elsewhere on the board

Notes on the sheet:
Copyright (c) 2020-2024 Anton Kuzmin Licensed under CERN-OHL-P v2 https://github.com/gmm-7550/


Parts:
C62: 2.2uF; C_0805_2012Metric
C63: 0.47uF; C_0603_1608Metric
C64, C65, C66, C95, C96, C98, C99, C100: 0.1uF; C_0402_1005Metric
R18, R20, R21, R24, R35, R37, R38, R39, R40, R41, R45, R46, R47, R48, R49, R50, R51, R52, R53, R54: 10k; R_0402_1005Metric
R19, R28, R30, R33, R43, R44: 100k; R_0402_1005Metric
R22, R25, R29, R31, R32, R34, R36, R42: 33; R_0402_1005Metric
R23: 1k; R_0402_1005Metric
U1: CCGM1A1; BGA-324_15.0x15.0mm_Layout18x18_P0.8mm_Ball0.45mm_Pad0.35mm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
U4, U5, U8: STG3692; QFN-16-1EP_2.6x1.8mm_P0.4mm_EP1.5x0.7mm
U6: 74LVC1G08; SOT-353_SC-70-5
U7: 74LVC1G07; SOT-23-5
U9: IS25LQ032B-JNLE; SO-8_3.9x4.9mm_P1.27mm
U10: PCA9539AHF; Texas_S-PVQFN-N24_EP2.1x2.1mm

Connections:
+2V5: C62.1, C63.1, C64.1, C65.1, C66.1, C95.1, C96.1, C98.1, C99.1, C100.1, R18.1, R19.1, R20.1, R21.1, R24.2, R35.1, R37.1, R38.1, R39.1, R40.1, R41.1, R53.1, R54.1, U1.N5 (VDD_WA), U1.P3 (VDD_WA), U1.P5 (VDD_WA), U1.T1 (VDD_WA), U1.U3 (VDD_WA), U4.2 (VCC), U5.2 (VCC), U6.5 (VCC), U7.5 (VCC), U8.2 (VCC), U9.8 (VCC), U10.21 (VCC); also elsewhere on the board
/Configuration and Control/CFG_MD0: R52.1, U1.R5 (CFG_MD0/IO_WA_A0), U10.10
/Configuration and Control/CFG_MD1: R51.1, U1.T5 (CFG_MD1/IO_WA_B0), U10.11
/Configuration and Control/CFG_MD2: R50.1, U1.U4 (CFG_MD2/IO_WA_A1), U10.12
/Configuration and Control/CFG_MD3: R49.1, U1.V4 (CFG_MD3/IO_WA_B1), U10.13
/Configuration and Control/GM_SPI_CLK: U1.N4 (IO_WA_B8/SPI_CLK), U4.13 (D4)
/Configuration and Control/GM_SPI_CS_N: U1.N3 (IO_WA_A8/~SPI_CS), U4.8 (D3)
/Configuration and Control/GM_SPI_D0: U1.P2 (IO_WA_B7/SPI_D0), U4.16 (D1)
/Configuration and Control/GM_SPI_D1: U1.P1 (IO_WA_A7/SPI_D1), U4.5 (D2)
/Configuration and Control/GM_SPI_D2: U1.R2 (IO_WA_B6/SPI_D2), U8.16 (D1)
/Configuration and Control/GM_SPI_D3: U1.R1 (IO_WA_A6/SPI_D3), U8.5 (D2)
/Configuration and Control/NOR_CLK: U5.13 (D4), U9.6 (SCK)
/Configuration and Control/NOR_CS_N: R37.2, U5.8 (D3), U9.1 (~CE)
/Configuration and Control/NOR_D0: U5.16 (D1), U9.5 (IO0/SI)
/Configuration and Control/NOR_D1: U5.5 (D2), U9.2 (IO1/SO)
/Configuration and Control/NOR_D2: R39.2, U8.13 (D4), U9.3 (IO2/~WP)
/Configuration and Control/NOR_D3: R38.2, U8.8 (D3), U9.7 (IO3/~HOLD)
/Configuration and Control/POR_EN: R24.1, U1.U1 (POR_EN/IO_WA_A3), U10.2 (P01)
/Configuration and Control/SPI_SEL0: R48.1, U4.3 (SE12), U4.10 (SEL34), U10.14
/Configuration and Control/SPI_SEL1: R47.1, U5.3 (SE12), U5.10 (SEL34), U10.15
/Configuration and Control/SPI_SEL2: R46.1, U8.3 (SE12), U10.16
/Configuration and Control/SPI_SEL3: R45.1, U8.10 (SEL34), U10.17
CFG_DONE: U1.V3 (IO_WA_B2/CFG_DONE), U10.4 (P03); also elsewhere on the board
CFG_FAILED_N: R18.2, U1.V2 (IO_WA_A2/~CFG_FAILED), U10.3 (P02); also elsewhere on the board
GND: C62.2, C63.2, C64.2, C65.2, C66.2, C95.2, C96.2, C98.2, C99.2, C100.2, R23.1, R28.2, R30.2, R33.2, R43.1, R44.1, R45.2, R46.2, R47.2, R48.2, R49.2, R50.2, R51.2, R52.2, U4.11 (GND), U5.11 (GND), U6.3 (GND), U7.3 (GND), U8.11 (GND), U9.4 (GND), U10.9 (GND), U10.18 (A0), U10.23 (A1), U10.25 (EPAD); also elsewhere on the board
GPIO1: R53.2, U10.7 (P06); also elsewhere on the board
GPIO4: R54.2, U10.8 (P07); also elsewhere on the board
HWSWCTRL: U10.6 (P05); also elsewhere on the board
JTAG_TCK: R23.2, U1.R3 (JTAG_TCK/IO_WA_A5); also elsewhere on the board
JTAG_TDI: R21.2, U1.T2 (JTAG_TDI/IO_WA_A4); also elsewhere on the board
JTAG_TDO: R22.2; also elsewhere on the board
JTAG_TMS: R20.2, U1.T3 (JTAG_TMS/IO_WA_B4); also elsewhere on the board
unnamed: R25.2, U1.R4 (IO_WA_B5/SPI_FWD)
unnamed: R22.1, U1.U2 (JTAG_TDO/IO_WA_B3)
unnamed: U4.1 (1S0), U5.1 (1S0)
unnamed: R28.1, R29.2, U4.15 (1S1), U5.15 (1S1)
unnamed: U4.6 (2S0), U5.6 (2S0)
unnamed: R30.1, R31.2, U4.4 (2S1), U5.4 (2S1)
unnamed: U4.9 (3S0), U5.9 (3S0)
unnamed: R19.2, R32.2, U4.7 (3S1), U5.7 (3S1)
unnamed: U4.14 (4S0), U5.14 (4S0)
unnamed: R33.1, R34.2, U4.12 (4S1), U5.12 (4S1)
unnamed: U8.1 (1S0), U8.14 (4S0)
unnamed: R36.2, R44.2, U8.12 (4S1), U8.15 (1S1)
unnamed: U8.6 (2S0), U8.9 (3S0)
unnamed: R42.2, R43.2, U8.4 (2S1), U8.7 (3S1)
unnamed: R35.2, U6.2, U10.1 (P00)
POR_N: U6.1, U10.24 (~RESET); also elsewhere on the board
REFSEL: U10.5 (P04); also elsewhere on the board
RSTO_N: U7.4; also elsewhere on the board
RST_N: U6.4, U7.2; also elsewhere on the board
SCL: R40.2, U10.19 (SCL); also elsewhere on the board
SDA: R41.2, U10.20 (SDA); also elsewhere on the board
SPI_CLK: R34.1; also elsewhere on the board
SPI_CS_N: R32.1; also elsewhere on the board
SPI_D0: R29.1; also elsewhere on the board
SPI_D1: R31.1; also elsewhere on the board
SPI_D2: R36.1; also elsewhere on the board
SPI_D3: R42.1; also elsewhere on the board
SPI_FWD: R25.1; also elsewhere on the board

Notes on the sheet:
Copyright (c) 2020-2024 Anton Kuzmin Licensed under CERN-OHL-P v2 https://github.com/gmm-7550/


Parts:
C101, C117, C118: 0.1uF; C_0402_1005Metric
C103, C112, C115, C116: 47uF; C_1210_3225Metric
C111: 1500pF; C_0402_1005Metric
C113, C114, C120, C121, C122, C123, C124, C125: 22uF; C_1206_3216Metric
C119, C126: 10uF; C_0805_2012Metric
JP1, JP2, JP3: SolderJumper_2_Open_Small; SolderJumper-2_P1.3mm_Open_RoundedPad1.0x1.5mm
L5, L10: ASPIAIG-FLR4020-1R0M-T; L_Abracon_F4020_4.1x4.1mm
R5, R55, R56, R59, R60, R61: 10k; R_0402_1005Metric
R26, R57, R64: 10; R_0402_1005Metric
R58: 2k; R_0402_1005Metric
R62, R63, R68, R75: 15k; R_0402_1005Metric
R66, R67: 47.5k; R_0402_1005Metric
R69, R73: 2.49k; R_0402_1005Metric
R74: 7.5k; R_0402_1005Metric
U3: ADP1753; QFN-16-1EP_4x4mm_P0.65mm_EP2.1x2.1mm_ThermalVias
U11: TPS3840DL28DBV; SOT-23-5
U12, U13: ADP2164; QFN-16-1EP_4x4mm_P0.65mm_EP2.5x2.5mm_ThermalVias

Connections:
+1V0: C120.1, C121.1, C123.1, C125.1, JP2.1, L10.2, R69.1; also elsewhere on the board
+2V5: C113.1, C114.1, C122.1, C124.1, C126.1, L5.2, R56.1, R62.1, R67.1, U3.1 (VIN), U3.2 (VIN), U3.3 (VIN), U3.4 (EN), U3.15 (VIN), U3.16 (VIN); also elsewhere on the board
DCDC_SYNC: R5.1, U12.1 (SYNC), U13.1 (SYNC); also elsewhere on the board
GND: C101.2, C103.2, C111.2, C112.2, C113.2, C114.2, C115.2, C116.2, C117.2, C118.2, C119.2, C120.2, C121.2, C122.2, C123.2, C124.2, C125.2, C126.2, R5.2, R61.2, R63.2, R66.2, R68.2, R75.2, U3.6 (GND), U3.17 (EPAD), U11.3 (GND), U12.5 (GND), U12.6 (PGND), U12.7 (PGND), U12.8 (PGND), U12.17 (EPAD), U13.5 (GND), U13.6 (PGND), U13.7 (PGND), U13.8 (PGND), U13.17 (EPAD); also elsewhere on the board
MR_N: R55.2, U11.4 (~MR); also elsewhere on the board
unnamed: JP1.2, R58.2, R60.1
unnamed: JP2.2, JP3.1, R69.2, R73.1
unnamed: JP3.2, R73.2, R74.1
unnamed: L5.1, U12.9 (SW), U12.10 (SW), U12.11 (SW)
unnamed: L10.1, U13.9 (SW), U13.10 (SW), U13.11 (SW)
unnamed: R60.2, R61.1, U3.9 (ADJ)
unnamed: C111.1, U3.7 (SS)
unnamed: C101.1, U11.5 (CT)
unnamed: R67.2, R68.1, U12.4 (FB)
unnamed: R64.2, U12.2 (RT)
unnamed: C117.1, R26.1, R64.1, U12.3 (TRK), U12.14 (VIN)
unnamed: R74.2, R75.1, U13.4 (FB)
unnamed: R66.1, U13.2 (RT)
unnamed: R62.2, R63.1, U13.3 (TRK)
unnamed: C118.1, R57.1, U13.14 (VIN)
OFF_N: R59.2, U12.15 (EN), U13.15 (EN); also elsewhere on the board
POR_N: R56.2, U3.5 (PG), U11.1 (~RESET), U12.16 (PGOOD), U13.16 (PGOOD); also elsewhere on the board
VDD_SER: C119.1, JP1.1, R58.1, U3.10 (VOUT), U3.11 (VOUT), U3.12 (VOUT), U3.13 (VOUT), U3.14 (VOUT); also elsewhere on the board
V_IN: C103.1, C112.1, C115.1, C116.1, R26.2, R55.1, R57.2, R59.1, U11.2 (VDD), U12.12 (PVIN), U12.13 (PVIN), U13.12 (PVIN), U13.13 (PVIN); also elsewhere on the board

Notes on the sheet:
2.5V, 4A max
1.0/1.1V, 0.8A max
0.9/1.0/1.1V, 4A max
Copyright (c) 2020-2024 Anton Kuzmin Licensed under CERN-OHL-P v2 https://github.com/gmm-7550/


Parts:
C67, C68, C69, C70: 0.47uF; C_0603_1608Metric
C71, C72, C74, C75, C78, C79, C81, C82, C85, C86, C88, C89, C135, C136: 0.1uF; C_0402_1005Metric
C73, C76, C77, C80, C83, C84, C87, C90, C91, C137, C138: 0.01uF; C_0402_1005Metric
C109, C110, C127, C128, C129, C130, C131: 2.2uF; C_0603_1608Metric
L6, L7, L8: MPZ1608S181ATAH0; L_0603_1608Metric
U1: CCGM1A1; BGA-324_15.0x15.0mm_Layout18x18_P0.8mm_Ball0.45mm_Pad0.35mm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

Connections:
+1V0: C67.1, C68.1, C69.1, C70.1, C74.1, C75.1, C76.1, C77.1, C81.1, C82.1, C83.1, C84.1, C86.1, C88.1, C89.1, C90.1, C91.1, C128.1, C129.1, C130.1, C131.1, C135.1, C136.1, C137.1, C138.1, L8.2, U1.F9 (VDD), U1.G6 (VDD), U1.G8 (VDD), U1.G10 (VDD), U1.G12 (VDD), U1.H7 (VDD), U1.H9 (VDD), U1.H11 (VDD), U1.H13 (VDD), U1.J6 (VDD), U1.J8 (VDD), U1.J10 (VDD), U1.J12 (VDD), U1.K7 (VDD), U1.K9 (VDD), U1.K11 (VDD), U1.K13 (VDD), U1.L6 (VDD), U1.L8 (VDD), U1.L10 (VDD), U1.L12 (VDD), U1.M7 (VDD), U1.M9 (VDD), U1.M11 (VDD), U1.M13 (VDD), U1.N6 (VDD), U1.N8 (VDD), U1.N10 (VDD); also elsewhere on the board
GND: C67.2, C68.2, C69.2, C70.2, C71.2, C72.2, C73.2, C74.2, C75.2, C76.2, C77.2, C78.2, C79.2, C80.2, C81.2, C82.2, C83.2, C84.2, C85.2, C86.2, C87.2, C88.2, C89.2, C90.2, C91.2, C109.2, C110.2, C127.2, C128.2, C129.2, C130.2, C131.2, C135.2, C136.2, C137.2, C138.2, U1.A1 (GND), U1.A7 (GND), U1.A10 (GND), U1.A13 (GND), U1.A18 (GND), U1.B16 (GND), U1.C1 (GND), U1.E5 (GND), U1.E7 (GND), U1.E9 (GND), U1.E11 (GND), U1.E13 (GND), U1.E18 (GND), U1.F1 (GND), U1.F6 (GND), U1.F8 (GND), U1.F10 (GND), U1.F12 (GND), U1.F14 (GND), U1.G5 (GND), U1.G7 (GND), U1.G9 (GND), U1.G11 (GND), U1.G13 (GND), U1.H6 (GND), U1.H8 (GND), U1.H10 (GND), U1.H12 (GND), U1.H14 (GND), U1.H18 (GND), U1.J1 (GND), U1.J5 (GND), U1.J7 (GND), U1.J9 (GND), U1.J11 (GND), U1.J13 (GND), U1.K6 (GND), U1.K8 (GND), U1.K10 (GND), U1.K12 (GND), U1.K14 (GND), U1.L5 (GND), U1.L7 (GND), U1.L9 (GND), U1.L11 (GND), U1.L13 (GND), U1.L18 (GND), U1.M1 (GND), U1.M6 (GND), U1.M8 (GND), U1.M10 (GND), U1.M12 (GND), U1.M16 (GND), U1.N7 (GND), U1.N9 (GND), U1.N12 (GND), U1.N17 (GND), U1.P4 (GND), U1.P7 (GND), U1.P9 (GND), U1.R12 (GND), U1.R16 (GND), U1.T4 (GND), U1.T11 (GND), U1.T17 (GND), U1.U14 (GND), U1.U15 (GND), U1.U16 (GND), U1.V1 (GND), U1.V6 (GND), U1.V9 (GND), U1.V14 (GND), U1.V16 (GND), U1.V18 (GND); also elsewhere on the board
unnamed: C79.1, C80.1, C110.1, L7.2, U1.U12 (VDD_SER), U1.V17 (VDD_SER)
unnamed: C85.1, C87.1, C127.1, L8.1, U1.P16 (VDD_PLL)
unnamed: C72.1, C73.1, C109.1, L6.2, U1.T16 (VDD_SER_PLL)
VDD_SER: C71.1, C78.1, L6.1, L7.1; also elsewhere on the board

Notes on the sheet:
Copyright (c) 2020-2024 Anton Kuzmin Licensed under CERN-OHL-P v2 https://github.com/gmm-7550/

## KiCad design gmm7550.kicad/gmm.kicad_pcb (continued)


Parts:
MH1, MH2, MH3, MH4: MountingHole_Pad; MountingHole_3.2mm_M3_ISO7380_Pad
P1, P2, P3, P4, P5: 10144518-061802LF

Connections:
+2V5: P1.33, P1.34, P2.33, P2.34, P3.33, P3.34, P4.33, P4.34, P5.9, P5.10, P5.45; also elsewhere on the board
CFG_DONE: P5.36; also elsewhere on the board
CFG_FAILED_N: P5.35; also elsewhere on the board
CLK0: P5.23; also elsewhere on the board
CLK2_N: P5.11; also elsewhere on the board
CLK2_P: P5.13; also elsewhere on the board
CLK3_N: P5.3; also elsewhere on the board
CLK3_P: P5.5; also elsewhere on the board
CLKI_N: P5.4; also elsewhere on the board
CLKI_P: P5.6; also elsewhere on the board
GND: MH1.1, MH2.1, MH3.1, MH4.1, P1.1, P1.2, P1.7, P1.8, P1.13, P1.14, P1.19, P1.20, P1.25, P1.26, P1.41, P1.42, P1.47, P1.48, P1.53, P1.54, P1.59, P1.60, P2.1, P2.2, P2.7, P2.8, P2.13, P2.14, P2.19, P2.20, P2.25, P2.26, P2.41, P2.42, P2.47, P2.48, P2.53, P2.54, P2.59, P2.60, P3.1, P3.2, P3.7, P3.8, P3.13, P3.14, P3.19, P3.20, P3.25, P3.26, P3.41, P3.42, P3.47, P3.48, P3.53, P3.54, P3.59, P3.60, P4.1, P4.2, P4.7, P4.8, P4.13, P4.14, P4.19, P4.20, P4.25, P4.26, P4.41, P4.42, P4.47, P4.48, P4.53, P4.54, P4.59, P4.60, P5.1, P5.2, P5.7, P5.8, P5.15, P5.16, P5.21, P5.22, P5.25, P5.28, P5.37, P5.38, P5.43, P5.44, P5.49, P5.50; also elsewhere on the board
IO_EA_A0: P3.58; also elsewhere on the board
IO_EA_A1: P3.52; also elsewhere on the board
IO_EA_A2: P3.46; also elsewhere on the board
IO_EA_A3: P3.57; also elsewhere on the board
IO_EA_A4: P3.40; also elsewhere on the board
IO_EA_A5: P3.51; also elsewhere on the board
IO_EA_A6: P3.45; also elsewhere on the board
IO_EA_A7: P3.30; also elsewhere on the board
IO_EA_A8: P3.39; also elsewhere on the board
IO_EA_B0: P3.56; also elsewhere on the board
IO_EA_B1: P3.50; also elsewhere on the board
IO_EA_B2: P3.44; also elsewhere on the board
IO_EA_B3: P3.55; also elsewhere on the board
IO_EA_B4: P3.38; also elsewhere on the board
IO_EA_B5: P3.49; also elsewhere on the board
IO_EA_B6: P3.43; also elsewhere on the board
IO_EA_B7: P3.28; also elsewhere on the board
IO_EA_B8: P3.37; also elsewhere on the board
IO_EB_A0: P3.24; also elsewhere on the board
IO_EB_A1: P3.29; also elsewhere on the board
IO_EB_A2: P3.18; also elsewhere on the board
IO_EB_A3: P3.23; also elsewhere on the board
IO_EB_A4: P3.12; also elsewhere on the board
IO_EB_A5: P3.11; also elsewhere on the board
IO_EB_A6: P3.17; also elsewhere on the board
IO_EB_A7: P3.5; also elsewhere on the board
IO_EB_A8: P3.6; also elsewhere on the board
IO_EB_B0: P3.22; also elsewhere on the board
IO_EB_B1: P3.27; also elsewhere on the board
IO_EB_B2: P3.16; also elsewhere on the board
IO_EB_B3: P3.21; also elsewhere on the board
IO_EB_B4: P3.10; also elsewhere on the board
IO_EB_B5: P3.9; also elsewhere on the board
IO_EB_B6: P3.15; also elsewhere on the board
IO_EB_B7: P3.3; also elsewhere on the board
IO_EB_B8: P3.4; also elsewhere on the board
IO_NA_A0: P2.6; also elsewhere on the board
IO_NA_A1: P2.12; also elsewhere on the board
IO_NA_A2: P2.5; also elsewhere on the board
IO_NA_A3: P2.11; also elsewhere on the board
IO_NA_A4: P2.18; also elsewhere on the board
IO_NA_A5: P2.17; also elsewhere on the board
IO_NA_A6: P2.23; also elsewhere on the board
IO_NA_A7: P2.24; also elsewhere on the board
IO_NA_A8: P2.29; also elsewhere on the board
IO_NA_B0: P2.4; also elsewhere on the board
IO_NA_B1: P2.10; also elsewhere on the board
IO_NA_B2: P2.3; also elsewhere on the board
IO_NA_B3: P2.9; also elsewhere on the board
IO_NA_B4: P2.16; also elsewhere on the board
IO_NA_B5: P2.15; also elsewhere on the board
IO_NA_B6: P2.21; also elsewhere on the board
IO_NA_B7: P2.22; also elsewhere on the board
IO_NA_B8: P2.27; also elsewhere on the board
IO_NB_A0: P2.30; also elsewhere on the board
IO_NB_A1: P2.39; also elsewhere on the board
IO_NB_A2: P2.40; also elsewhere on the board
IO_NB_A3: P2.45; also elsewhere on the board
IO_NB_A4: P2.46; also elsewhere on the board
IO_NB_A5: P2.51; also elsewhere on the board
IO_NB_A6: P2.57; also elsewhere on the board
IO_NB_A7: P2.52; also elsewhere on the board
IO_NB_A8: P2.58; also elsewhere on the board
IO_NB_B0: P2.28; also elsewhere on the board
IO_NB_B1: P2.37; also elsewhere on the board
IO_NB_B2: P2.38; also elsewhere on the board
IO_NB_B3: P2.43; also elsewhere on the board
IO_NB_B4: P2.44; also elsewhere on the board
IO_NB_B5: P2.49; also elsewhere on the board
IO_NB_B6: P2.55; also elsewhere on the board
IO_NB_B7: P2.50; also elsewhere on the board
IO_NB_B8: P2.56; also elsewhere on the board
IO_SA_A0: P4.58; also elsewhere on the board
IO_SA_A1: P4.57; also elsewhere on the board
IO_SA_A2: P4.51; also elsewhere on the board
IO_SA_A3: P4.52; also elsewhere on the board
IO_SA_A4: P4.45; also elsewhere on the board
IO_SA_A5: P4.46; also elsewhere on the board
IO_SA_A6: P4.39; also elsewhere on the board
IO_SA_A7: P4.40; also elsewhere on the board
IO_SA_A8: P4.30; also elsewhere on the board
IO_SA_B0: P4.56; also elsewhere on the board
IO_SA_B1: P4.55; also elsewhere on the board
IO_SA_B2: P4.49; also elsewhere on the board
IO_SA_B3: P4.50; also elsewhere on the board
IO_SA_B4: P4.43; also elsewhere on the board
IO_SA_B5: P4.44; also elsewhere on the board
IO_SA_B6: P4.37; also elsewhere on the board
IO_SA_B7: P4.38; also elsewhere on the board
IO_SA_B8: P4.28; also elsewhere on the board
IO_SB_A0: P4.24; also elsewhere on the board
IO_SB_A1: P4.18; also elsewhere on the board
IO_SB_A2: P4.12; also elsewhere on the board
IO_SB_A3: P4.6; also elsewhere on the board
IO_SB_A4: P4.29; also elsewhere on the board
IO_SB_A5: P4.17; also elsewhere on the board
IO_SB_A6: P4.11; also elsewhere on the board
IO_SB_A7: P4.23; also elsewhere on the board
IO_SB_A8: P4.5; also elsewhere on the board
IO_SB_B0: P4.22; also elsewhere on the board
IO_SB_B1: P4.16; also elsewhere on the board
IO_SB_B2: P4.10; also elsewhere on the board
IO_SB_B3: P4.4; also elsewhere on the board
IO_SB_B4: P4.27; also elsewhere on the board
IO_SB_B5: P4.15; also elsewhere on the board
IO_SB_B6: P4.9; also elsewhere on the board
IO_SB_B7: P4.21; also elsewhere on the board
IO_SB_B8: P4.3; also elsewhere on the board
IO_WB_A0: P1.6; also elsewhere on the board
IO_WB_A1: P1.5; also elsewhere on the board
IO_WB_A2: P1.11; also elsewhere on the board
IO_WB_A3: P1.12; also elsewhere on the board
IO_WB_A4: P1.17; also elsewhere on the board
IO_WB_A5: P1.18; also elsewhere on the board
IO_WB_A6: P1.23; also elsewhere on the board
IO_WB_A7: P1.24; also elsewhere on the board
IO_WB_A8: P1.29; also elsewhere on the board
IO_WB_B0: P1.4; also elsewhere on the board
IO_WB_B1: P1.3; also elsewhere on the board
IO_WB_B2: P1.9; also elsewhere on the board
IO_WB_B3: P1.10; also elsewhere on the board
IO_WB_B4: P1.15; also elsewhere on the board
IO_WB_B5: P1.16; also elsewhere on the board
IO_WB_B6: P1.21; also elsewhere on the board
IO_WB_B7: P1.22; also elsewhere on the board
IO_WB_B8: P1.27; also elsewhere on the board
IO_WC_A0: P1.30; also elsewhere on the board
IO_WC_A1: P1.39; also elsewhere on the board
IO_WC_A2: P1.45; also elsewhere on the board
IO_WC_A3: P1.40; also elsewhere on the board
IO_WC_A4: P1.51; also elsewhere on the board
IO_WC_A5: P1.46; also elsewhere on the board
IO_WC_A6: P1.57; also elsewhere on the board
IO_WC_A7: P1.58; also elsewhere on the board
IO_WC_A8: P1.52; also elsewhere on the board
IO_WC_B0: P1.28; also elsewhere on the board
IO_WC_B1: P1.37; also elsewhere on the board
IO_WC_B2: P1.43; also elsewhere on the board
IO_WC_B3: P1.38; also elsewhere on the board
IO_WC_B4: P1.49; also elsewhere on the board
IO_WC_B5: P1.44; also elsewhere on the board
IO_WC_B6: P1.55; also elsewhere on the board
IO_WC_B7: P1.56; also elsewhere on the board
IO_WC_B8: P1.50; also elsewhere on the board
JTAG_TCK: P5.41; also elsewhere on the board
JTAG_TDI: P5.39; also elsewhere on the board
JTAG_TDO: P5.40; also elsewhere on the board
JTAG_TMS: P5.42; also elsewhere on the board
MR_N: P5.48; also elsewhere on the board
OFF_N: P5.47; also elsewhere on the board
RSTO_N: P5.46; also elsewhere on the board
RX_N: P5.19; also elsewhere on the board
RX_P: P5.17; also elsewhere on the board
SCL: P5.26; also elsewhere on the board
SDA: P5.24; also elsewhere on the board
SPI_CLK: P5.27; also elsewhere on the board
SPI_CS_N: P5.30; also elsewhere on the board
SPI_D0: P5.29; also elsewhere on the board
SPI_D1: P5.32; also elsewhere on the board
SPI_D2: P5.31; also elsewhere on the board
SPI_D3: P5.33; also elsewhere on the board
SPI_FWD: P5.34; also elsewhere on the board
TX_N: P5.20; also elsewhere on the board
TX_P: P5.18; also elsewhere on the board
VIO_EA: P3.35, P3.36; also elsewhere on the board
VIO_EB: P3.31, P3.32; also elsewhere on the board
VIO_NA: P2.31, P2.32; also elsewhere on the board
VIO_NB: P2.35, P2.36; also elsewhere on the board
VIO_SA: P4.35, P4.36; also elsewhere on the board
VIO_SB: P4.31, P4.32; also elsewhere on the board
VIO_WB: P1.31, P1.32; also elsewhere on the board
VIO_WC: P1.35, P1.36; also elsewhere on the board
V_IN: P5.51, P5.52, P5.53, P5.54, P5.55, P5.56, P5.57, P5.58, P5.59, P5.60; also elsewhere on the board

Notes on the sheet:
Copyright (c) 2020-2022 Anton Kuzmin Licensed under CERN-OHL-P v2 https://github.com/gmm-7550/



Board: 6 copper layers, 50.0 x 75.0 mm, 252 parts (86 on the bottom side), 268 nets.

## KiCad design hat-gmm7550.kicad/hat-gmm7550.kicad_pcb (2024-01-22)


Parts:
C1: 0.1uF; C_0603_1608Metric
FID1, FID2, FID3: Fiducial; Fiducial_1mm_Mask2mm
J1: VisionFive_GPIO; PinHeader_2x20_P2.54mm_Vertical
J2: Conn_01x02; PinHeader_1x02_P2.54mm_Vertical
J3: Conn_02x02_Odd_Even; PinHeader_2x02_P2.54mm_Vertical
J4: DNI; Molex_Micro-Fit_3.0_43045-0200_2x01_P3.00mm_Horizontal
MH1, MH2, MH3, MH4: MountingHole; RPi_Hat_Mounting_Hole
R1, R2: 3.9k; R_0603_1608Metric
R3: 1k; R_0603_1608Metric
U1: CAT24C32Y; TSSOP-8_4.4x3mm_P0.65mm

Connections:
+3V3: C1.1, J1.1 (3.3V), J1.17 (3.3V), R1.1, R2.1, R3.1, U1.8 (VCC); also elsewhere on the board
+5V: J3.2, J3.4, J4.2; also elsewhere on the board
/ID_SC: J1.28 (GPIO10_ID_SC), R2.2, U1.6 (SCL)
/ID_SD: J1.27 (GPIO9_ID_SD), R1.2, U1.5 (SDA)
/VF5V: J1.2 (5V), J1.4 (5V), J3.1, J3.3
GND: C1.2, J1.6 (GND), J1.9 (GND), J1.14 (GND), J1.20 (GND), J1.25 (GND), J1.30 (GND), J1.34 (GND), J1.39 (GND), J1.40 (GPIO0), J2.2, J4.1, U1.1 (A0), U1.2 (A1), U1.3 (A2), U1.4 (GND); also elsewhere on the board
unnamed: J2.1, R3.2, U1.7 (WP)
VF_MISO: J1.21 (GPIO16_MISO); also elsewhere on the board
VF_MOSI: J1.19 (GPIO18_MOSI); also elsewhere on the board
VF_MR: J1.11 (GPIO44); also elsewhere on the board
VF_NSS: J1.24 (GPIO15_CE0); also elsewhere on the board
VF_OFF: J1.13 (GPIO22); also elsewhere on the board
VF_ON: J1.7 (GPIO46); also elsewhere on the board
VF_RX: J1.10 (GPIO13_RXD); also elsewhere on the board
VF_SCL: J1.5 (GPIO47_SCL); also elsewhere on the board
VF_SCLK: J1.23 (GPIO12_SCLK); also elsewhere on the board
VF_SDA: J1.3 (GPIO48_SDA); also elsewhere on the board
VF_TX: J1.8 (GPIO14_TXD); also elsewhere on the board

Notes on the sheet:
Copyright (c) 2022-2024 Anton Kuzmin Licensed under CERN-OHL-P v2 https://github.com/gmm-7550/
40-pin GPIO (Raspberry Pi) HAT adapter for GMM-7550 Module
You may redistribute and modify this documentation and make products using it under the terms of the CERN-OHL-P v2 (https:/cern.ch/cern-ohl). This documentation is distributed WITHOUT ANY EXPRESS OR IMPLIED WARRANTY, INCLUDING OF MERCHANTABILITY, SATISFACTORY QUALITY AND FITNESS FOR A PARTICULAR PU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


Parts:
C6, C7, C8, C9, C10, C11, C12, C13, C14, C15: 0.1uF; C_0603_1608Metric
J7: 10144517-064802LF; 10144517-061802LF
J9, J10: Pmod 2x6; PmodSocket_2x06_P2.54mm_Horizontal
R16, R17: 10k; R_0603_1608Metric
U4, U5, U6, U7: LSF0204PW; TSSOP-14_4.4x5mm_P0.65mm
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

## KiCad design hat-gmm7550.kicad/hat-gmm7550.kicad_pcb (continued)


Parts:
C2, C5: 47uF, 16V; CP_EIA-6032-28_Kemet-C; Part Number T491C476M016AT
C3, C16, C17, C18, C19, C20: 0.1uF; C_0603_1608Metric
C4: 1.0uF; C_0603_1608Metric
D1, D2: APT1608PGW; LED_0603_1608Metric
D3: HSMA-C197; LED_0603_1608Metric
D4: HSMC-C197; LED_0603_1608Metric
J5: DNI; PinHeader_1x04_P2.54mm_Vertical
J6: 10144517-064802LF; 10144517-061802LF
J8: JTAG; PinHeader_2x05_P2.54mm_Vertical
MH5, MH6: 3.2mm; MountingHole_3.2mm_M3_ISO7380
Q1, Q2, Q3: NX6008NBK; SOT-23
Q4: FDC855N; SuperSOT-6
R4, R8, R9, R10: 1k; R_0603_1608Metric
R5, R6, R7, R11, R12, R13, R20, R21: 10k; R_0603_1608Metric
R14: 50 mOhm; R_Shunt_Ohmite_LVK12; Part Number LVK12R050FER
R15: 10; R_0603_1608Metric
R18: 0; R_0603_1608Metric
R19: DNI; R_0603_1608Metric
TP1: Clock_25MHz; TestPoint_THTPad_D1.0mm_Drill0.5mm
TP2, TP3: Ref_CLK; TestPoint_THTPad_D1.0mm_Drill0.5mm
TP4, TP5: GND; TestPoint_THTPad_D1.0mm_Drill0.5mm
U2: 74LVC1G07; SOT-23-5
U3: ADM1177; MSOP-10_3x3mm_P0.5mm
U8, U9: LSF0204PW; TSSOP-14_4.4x5mm_P0.65mm
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

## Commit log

2020-04-01 GateMate Module -- first step
    [CnC.sch, cfg_spi.sch, clk_serdes.sch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]
2020-04-02 FPGA core and IO power, PLL and SERDES, FPGA GPIO signals are connected... WIP
    [cfg_spi.sch, clk_serdes.sch, connectors.sch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]
2020-04-08 Schematic is [almost] done. TODO: Connectors and a few footprints
    [cfg_spi.sch, clk_serdes.sch, gmm.kicad_pcb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]
2020-04-08 Footprint for high bandwidth quad SPDT switch (STmicro STG3692) is created.
    [gmm.kicad_pcb]
2020-05-20 Switch to five identical connectors, draft IO connection, current working PCB size is 50 x 75 mm
    [cfg_spi.sch, clk_serdes.sch, connectors.sch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]
2020-06-03 BOM clean-up: unified R/C values and footprints
    [cfg_spi.sch, gmm.kicad_pcb, gmm.sch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]
2020-06-03 Add missing connection
    [connectors.sch]
2020-06-03 Placement and a bit of FPGA fanout
    [gmm.kicad_pcb]
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2020-07-08 CologneChip logo is added to all schematic pages
    [cfg_spi.sch, clk_serdes.sch, connectors.sch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]
2020-07-08 Change power decoupling caps according to the Eval.Board schematic
    [cfg_spi.sch, fpga_pwr.sch, io.sch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]
2020-07-23 PLL core power from a low-noise LDO (1.8V)
    [clk_serdes.sch]
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2020-07-27 Add footprints for solder jumpers and L10 inductor
    [gmm.kicad_pcb, power.sch]
2020-10-01 Schematic freeze, preliminary placement is done.
    [cfg_spi.sch, clk_serdes.sch, connectors.sch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]
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2022-03-16 The module design is updated to revision 2.0, 40-pin GPIO (HAT) adapter board is created
    [cfg_spi.kicad_sch, cfg_spi.sch, clk_serdes.kicad_sch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]
2022-04-19 DRC and cleanup HAT GMM-7550
    [hat-gmm7550.kicad_pcb]
2022-04-25 Change U2 footprint due to the part availability, revision and date are updated (HAT GMM-7550)
    [gmm-7550-power.kicad_sch, hat-gmm7550.kicad_pcb, hat-gmm7550.kicad_sch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]
2022-04-25 HAT GMM-7550 -- add mounting holes positions to a mechanical drawing
    [hat-gmm7550.kicad_pcb]
2022-04-25 Change U7 footprint due to the part availability, revision and date are updated, DRC warnings clean-up (GMM-7550)
    [cfg_spi.kicad_sch, clk_serdes.kicad_sch, connectors.kicad_sch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]
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2023-04-13 Small module with SRAM and SPI-NOR FLASH
    [ram-gmm7550.csv, ram-gmm7550.kicad_pcb, ram-gmm7550.kicad_sch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]
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2024-01-22 Update designs to KiCad v7
    [cfg_spi.kicad_sch, clk_serdes.kicad_sch, connectors.kicad_sch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]
2024-01-22 Update copyright years and increment revision
    [cfg_spi.kicad_sch, clk_serdes.kicad_sch, connectors.kicad_sch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]
2024-01-25 Minor updates based on the test results
    [gmm-7550-power.kicad_sch, gmm.kicad_sch, power.kicad_sch]
2024-01-29 Update QR-code with a link to the project web site
    [gmm.kicad_pcb, gmm.kicad_sch]
2024-02-12 Change module connector part number: 9mm board-to-board distance
    [gmm-7550-power.kicad_sch, pmod.kicad_sch]
2025-05-31 The first step of the USB 3 project -- adapter block diagram
    [block_diag.kicad_sch, usb3-gmm7550.kicad_pcb, usb3-gmm7550.kicad_sch]
2025-07-05 Add USB 1.1 Driver/Receiver implementation option
    [block_diag.kicad_sch]
2025-07-12 Add pages to the USB 3 Adapter schematic and new project symbols
    [gmm-7550-io.kicad_sch, gmm-7550.kicad_sch, rp2040.kicad_sch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]
2025-07-17 USB 3 adapter schematic -- WIP
    [block_diag.kicad_sch, gmm-7550-io.kicad_sch, gmm-7550.kicad_sch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]
2025-07-20 USB 3 adapter schematic -- WIP: new components and footprints
    [block_diag.kicad_sch, gmm-7550-io.kicad_sch, gmm-7550.kicad_sch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]
2025-07-22 USB 3 adapter schematic -- WIP: USB 3 and Power Delivery pages
    [gmm-7550-io.kicad_sch, gmm-7550.kicad_sch, rp2040.kicad_sch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]
2025-07-23 USB 3 adapter schematic -- WIP: USB 1.1 and 2.0 page, connections to the GMM-7550 IOs
    [block_diag.kicad_sch, gmm-7550-io.kicad_sch, gmm-7550.kicad_sch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]
2025-07-24 USB 3 adapter schematic: revision 0.9 (pre-layout) is ready
    [block_diag.kicad_sch, gmm-7550-io.kicad_sch, gmm-7550.kicad_sch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]
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2025-07-24 Fix typo in the USB 3 Adapter schematic pdf filename
2025-08-07 Placement: WIP, schematic update to 0.9.1 -- BoM simplification and minor improvements
    [block_diag.kicad_sch, gmm-7550-io.kicad_sch, gmm-7550.kicad_sch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]
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2025-08-17 Change LED current limiting resistors to smaller package
    [gmm-7550.kicad_sch]
2025-08-17 Change SPI NOR Flash (U14) to smaller package and wide Vcc range (for possible update to Vio=1.8V)
    [rp2040.kicad_sch]
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2025-09-02 Add USB Type-C plug polarity indication (A_B_SIDE signal from PD controller)
    [block_diag.kicad_sch, gmm-7550-io.kicad_sch, gmm-7550.kicad_sch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]
2025-09-16 Layout -- re-arrange and connect all GMM-7550 IOs on J4 (USB 1.1 and 2.0)
    [block_diag.kicad_sch, gmm-7550-io.kicad_sch, gmm-7550.kicad_sch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]
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2025-09-27 Revert "Add symbol and footprint for TI TPS25751 -- USB Type-C PD Controller"
    Another PD controller will be used instead.
    This reverts commit 4d805ddc3812accc94c9496ae357a3b6832bdf56.
2025-10-01 USB Power Delivery redesign (STmicro controller is NRND)
    [block_diag.kicad_sch, gmm-7550-io.kicad_sch, gmm-7550.kicad_sch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]
2025-10-04 Layout WIP: split power plane (internal layer 2)
    [gmm-7550-io.kicad_sch, rp2040.kicad_sch, usb3-gmm7550.kicad_pcb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]
2025-10-08 Layout [almost] complete -- all connections are routed
    [gmm-7550-io.kicad_sch, gmm-7550.kicad_sch, rp2040.kicad_sch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]
2025-10-11 Final touches -- revision 1.0 schematic is released
    [block_diag.kicad_sch, gmm-7550-io.kicad_sch, gmm-7550.kicad_sch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]
2025-10-16 Final touches to the PCB, get ready to generate manufacturing files
    [usb3-gmm7550.kicad_pcb]
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2025-10-16 Fix release date on the schematic title sheet and add a link to the schematic from README
    [usb3-gmm7550.kicad_sch]
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

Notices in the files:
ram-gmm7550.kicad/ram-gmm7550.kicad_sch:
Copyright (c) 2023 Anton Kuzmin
